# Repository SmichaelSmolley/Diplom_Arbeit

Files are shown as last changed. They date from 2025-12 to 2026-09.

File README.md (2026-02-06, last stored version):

# VS Code Githubsetup

aus github die noreply email heraus suchen dann **git config --global user.email [deine email]**                                      

und auch den username einstellen: **git config --global user.name SmichaelSmolley**

# Ordnerstruktur

## Bokumentation

> In Dokumentation bitte nur words oder Rechnungen

## Hardware

> In Hardware bitte alle datein die mit der hardware seite der DIP zusammenhängen

## Software

> LIBs, python scripts und cpp desktop programme

> Um Python programme laufen zu lassen bitte die *venv.bat* ausführen, dieses installiert alle libs aus requirments, dann mit *.\venv\Scripts\activate* venv starten und dort mit *python dasprogramm* starten, wenn neue libs hinzukommen bitte chatgpt fragen wie du die requirments erweiterts.

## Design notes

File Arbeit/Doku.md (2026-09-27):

# Doku

### **_Spannungsversorgung_** 

Für ferschidenste ics oder uC worden LDOS gewählt weil niergents auf der PCB große kontinurliche ströme gebracuht werden. 
es werden 3,3V 5V und eine ± versorgung benötigt für die benötigten opvs. 
da die digital versorgung muss nicht shönsein da eigenlich nur spannung gebracuht wird nichts schönen doch die analog 5v versorgung sollte schön sein.
es werden hauptsächlich auf Psrr und auf low noise, nciht umbedingt high accuracy. 

### **_Drivers_** 

PINs.c

im PINs.c werden die GPIO pins konfiguriert. 

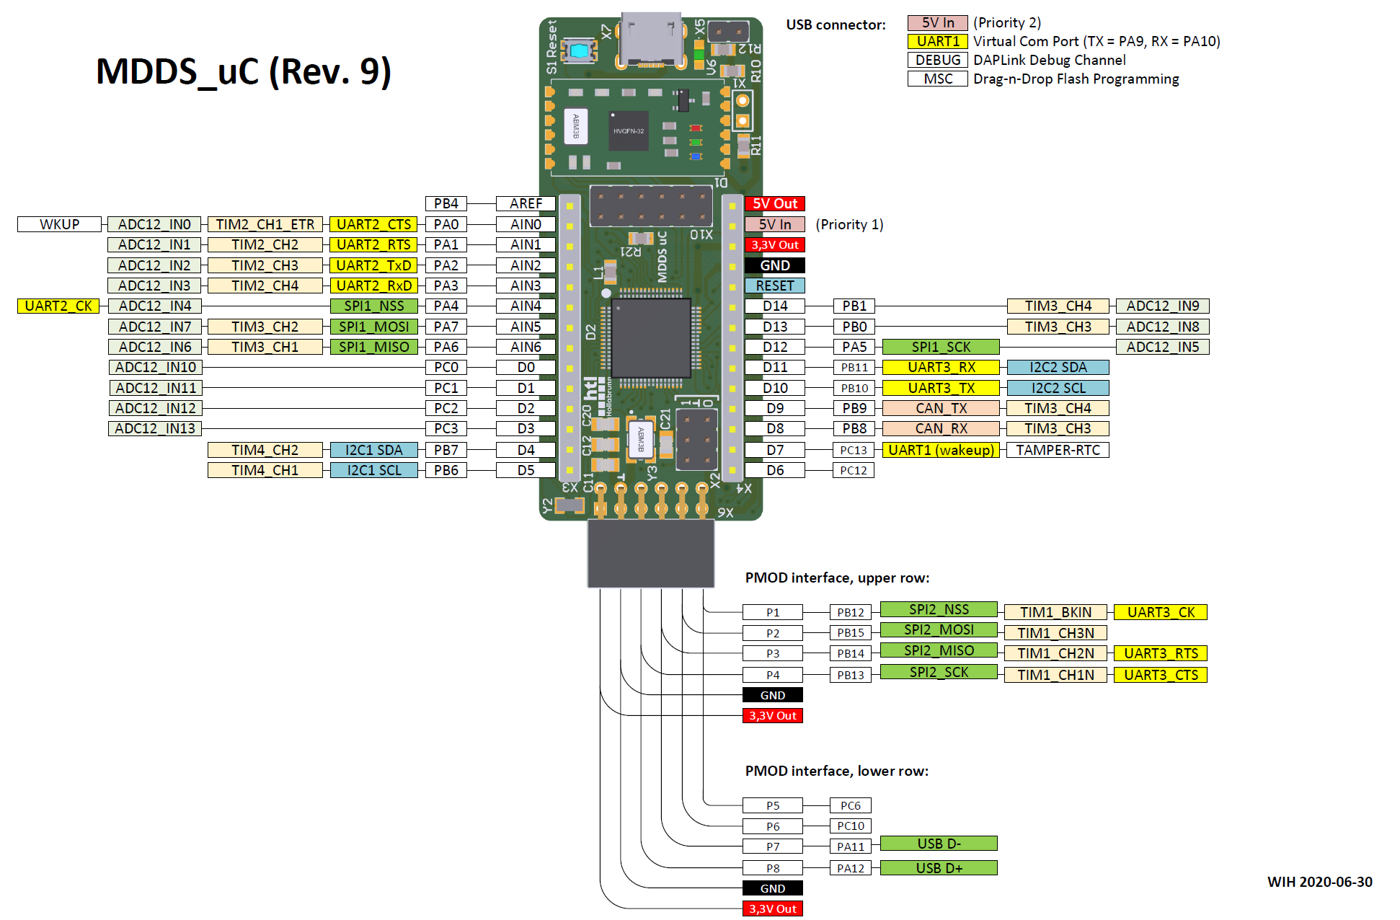
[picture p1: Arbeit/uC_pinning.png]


Der Port A: pin 1,2,4 werdenals Output push pullkofiguriert. PA1 ist die CS* für den DAC (AD5689) biem SPI bus. PA2 ist der konfigurations pin des DAC der zwischen einem gain von 1 und gain von 2 umschaltet, bei einem 1 auf PA2 ist der Gain 2, und damit ist die ausgangs range von 0V bis 5V, und bei PA2 low ist die range 0V bis 2.5V. PIN PA4 ist der CS* für den SPI bus des ADC ADS8681.
Port A: 5,6,7: Pin PA5,7 wird als Alternate funktion PP definiert für die SPI kommunikation. PIN PA6 idt für den MISO pin und ist für analog floating.

Port b: pin 1,4,7 sind im output push pull defniert, 1 ist für die Analog psu enable leitung und aktiviert die 5V versorgung. 4 ist für die Reset* leitung. 7 ist für die OPV enable leitung da die opv enleitungen nicht ganz funktioniern immer auf high lassen.
PB0 ist open drain ist für den One wire bus für in und out, auf diesem bus sind temp sensren und auch einen eeprom.

Portb PB8,9,11: die Ports PB8,9 sind open push pull welche auf die anzeige leds geleitet werden, 9 grün, 8 rot. Pin 11 ist für die 3,3V versorgung also immer high. 

port c: 0,1,2,3, sind immer gp pp und steuern die ralai spulen.

port C: 12 input pull up, ist die ADC* Alarm leitung diese liefert infos wenn ein alarm zustand beim adc auftritt. PC13 ist General purpus pp und ist für den ADC die Reset* leitung.

SPI.c

`#ifndef SPI_H
#define SPI_H

#include <stm32f10x.h>
#include <stdbool.h>

void spi1_init();

void spi1_set_baud(uint8_t baut);

void spi1_rx_dma(bool setting);

uint16_t spi1_transfer16(uint16_t tx_data);

uint8_t spi1_transfer8(uint8_t tx_data);

#endif`

die funmtion spi1 init wird die ganze regisdter konfig gesetzt. anfangs wird eine 8bit übertragung gesetz, es wird standart mäßig ein teiler von 16 verwendet. mit der funktion set baud kann der teiler gesetzt werden nach der tabelle:

	000: fPCLK/2
	001: fPCLK/4
	010: fPCLK/8
	011: fPCLK/16
	100: fPCLK/32
	101: fPCLK/64
	110: fPCLK/128
	111: fPCLK/256

die funktion rx_dma kann den dma für die z.b. adc auswetung geladen werden. die funktion spi transfer8 leitet einen transfer ein der daten die in einem uint8 angegeben wird, die funktion transfer 16 verwendet 2 mal die transfer 8 funktion beide funktionen sind blocking.

AD5689

Im `AD5689.c` wird der AD5689 DAC über SPI angesteuert. Die Initialisierung erfolgt mit `AD5689_init()`. Dabei wird der DAC zurückgesetzt, der Gain auf 1 gesetzt und der Ausgang zunächst auf 0 V gestellt.

Mit `AD5689_send_command()` werden die Befehle an den DAC übertragen. Dabei werden insgesamt 24 Bit übertragen. Das erste Byte enthält Befehl und Adresse, die nächsten zwei Bytes den 16-Bit-Datenwert.

Die Funktion `AD5689_set_Voltage()` wandelt eine gewünschte Spannung von 0 V bis 2,5 V in einen 16-Bit-DAC-Wert um. Werte außerhalb dieses Bereichs werden auf 0 V bzw. 2,5 V begrenzt. Der berechnete Wert wird anschließend an den ausgewählten DAC-Kanal übertragen.

Ads8681

Im `ADS8681.c` wird der ADS8681 ADC über SPI angesteuert.

`ADS8681_transfer_frame()` überträgt einen 32-Bit Frame. Dieser wird in zwei 16-Bit Übertragungen aufgeteilt. Vor der Übertragung wird `ADC_SPI_NCS` auf Low gesetzt und danach wieder auf High.

`ADS8681_send_Command_blocking()` erstellt den benötigten 32-Bit Frame aus Command, Registeradresse und Daten. Der Frame wird anschließend übertragen. Danach wird ein NOP-Frame gesendet, um die Antwort des ADC aus dem Sendepuffer auszulesen.

`ADS8681_init()` setzt den ADC zuerst über `ADC_NRESET` zurück. Danach wird über das Range-Select-Register der Eingangsbereich eingestellt. Im Code wird `ADS8681_RANGE_SEL_UP_1_25_VREF` verwendet.

`ADS8681_get_VOLT()` wandelt den 16-Bit Rohwert des ADC in eine Spannung um. Dabei wird `VREF = 4,096 V` verwendet. Durch die eingestellte bipolare Eingangsspannung ergibt sich ein Messbereich von ungefähr `-2,56 V bis +2,56 V`.

# Messung am 22.09.2026

Messaufbau mit platiene von Drain 1V über 2*8,5Meg Ohm wiederstände an den Source anschluss.
ergebniss sollten:

Ir = 1V/ 17Meg OHM = 58.8nA
dann am TIA:
Uout = Ir * Rf = 58.8nA * 10Meg = 0,588V

nach dem Dämpfer:
Ud = Utia * (10/33) = 0,178V

bei einer messung mit mustimeter kamm richtige spannung bei der adc auswertung kammen die falschen daten, anschluss messung mit oszi nach dem dämper eins mit DC 0,178V überlagertes 400mV pp 50 Hz signal. vermutung aufgrund des widerstands aufbeu und einstrahlung da, denn diese einstarhlung ~10meg verstärkt wird ist es sehr groß. _Abschirmung notwendig_ .

code für die testung:

`int main()
{
	PIN_init();
	set_up_uart1();
	spi1_init();
	
PER_33V_PSU_EN = 1;
ANALOG_5V_PSU_EN = 1;
OPV_PSU_EN = 1;

cal_Select_Reset = 0;
cal_Select_set = 0;
Range_Select_Reset = 0;
Range_Select_set = 0;

DAC_GAIN=0;
DAC_SPI_NCS = 1;
ADC_SPI_NCS = 1;

uart1_set_baud(9600);

{
uint16_t i;
for( i = 0; i < 10000; i++);
}

spi1_set_baud(7);

uart_put_string("UART TEST\r\n");

set_range_10meg();
reset_GND_Relai();
AD5689_set_Voltage(0,AD5689_ADDR_DAC_AB);

wait_ms(1000);

static double buffer[1000];

AD5689_set_Voltage(1.0, AD5689_ADDR_DAC_AB);
char uart_buffer[64];
	wait_ms(1000);
	int i;
for ( i = 0; i < 20; i++)
{
    /* Frame 1: Ergebnis verwerfen */
    ADC_SPI_NCS = 0;
    spi1_transfer16(0x0000);
    ADC_SPI_NCS = 1;

for (volatile int j = 0; j < 1000; j++);

/* Frame 2: Ergebnis verwenden */
ADC_SPI_NCS = 0;
uint16_t raw = spi1_transfer16(0x0000);
ADC_SPI_NCS = 1;

sprintf(
    uart_buffer,
    "%d,0x%04X,%.9f\r\n",
    i,
    raw,
    ADS8681_get_VOLT(raw)
);

uart_put_string(uart_buffer);
}`

# Messung am 23.09.2026

beid er messung im DIC raum wurde mit den giwnsteck die netzspannugnen der pcb eingestellt:

psu1: Ch1: +9V Ch2 -9V
psu2: Ch1: 5V Ch2 6,5V

dnach wurde mit bnc to banana kabeln wurden zuerst mit einem 10Meg weiderstand verbunden zwischen Drain und source anschlussen auf der PCB.

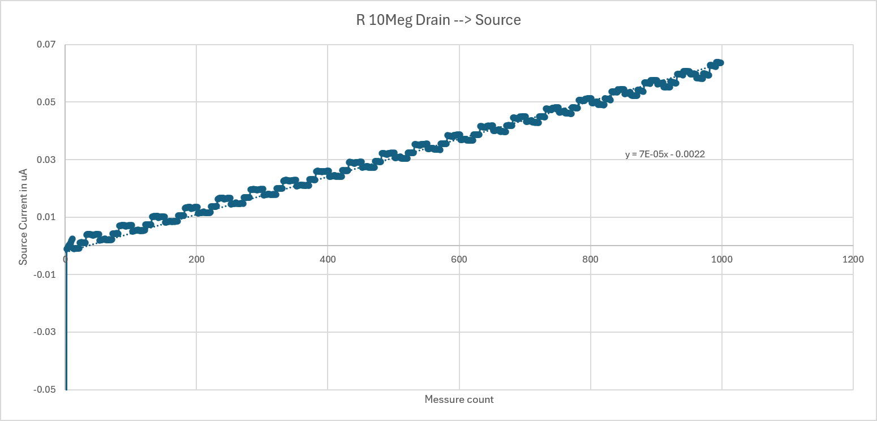
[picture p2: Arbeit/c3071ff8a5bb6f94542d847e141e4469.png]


bei jedem messpunkt wird die spannung des Drain ausgangs geändert, zusehen ist das ein ~50Hz raushcen über dem signal liegt, müsste bei transienten messungen rausgemittelt werden oder versuchen mit dem case zu arbeiten. um es zu minimieren, es wurde versucht bei der IDVG messung mittels 10messwerte pro punkt.

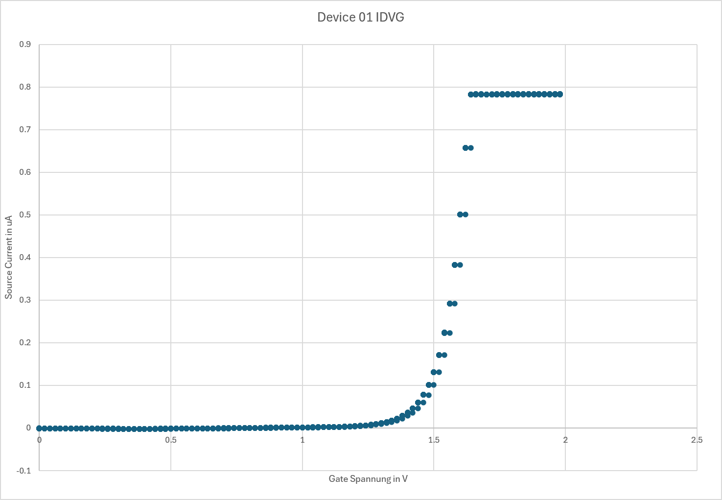
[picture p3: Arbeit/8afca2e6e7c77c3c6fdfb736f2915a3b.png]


Die idvg ab 1,5V gate spannung bis zu~1,7V ist die daten dichte punkte ziemlich gering.

# code 27.09
uint16_t Sps = 1000;
	
	static uint8_t buffer[2000];
	
	init_tim2(Sps);
	
	spi1_tx_dma_init();
	
	spi1_rx_dma_init();
	
	spi1_rx_dma(buffer, 2000);
	
	tim2_enable();
	
	/*static double buffer[1000];
	char uart_buffer[64];
	AD5689_set_Voltage(1.0, AD5689_ADDR_DAC_A);
	wait_ms(2000);
	LED_RED = 1;
	int i = 0;

	for(i = 0; i < 100; i++)
	{
		int j;

		for(j = 0; j < 10; j++)
		{
			ADC_SPI_NCS = 0;

			uint16_t raw = spi1_transfer16(0x0000);
			double volt = ADS8681_get_VOLT(raw);

			buffer[(i * 10) + j] = volt;

			ADC_SPI_NCS = 1;
		}

		DAC_SPI_NCS = 0;

		AD5689_set_Voltage(
			(i*0.02),
			AD5689_ADDR_DAC_B
		);
		wait_ms(100);
		DAC_SPI_NCS = 1;
		
	}
	
LED_GREEN = 1;

for(i = 0; i < 1000; i++) 
	{
		sprintf( 
		uart_buffer, 
		"%i,%.9f\r\n", 
		i, 
		buffer[i] 
		);
		uart_put_string(uart_buffer);
	}

	LED_GREEN = 0;
	LED_RED = 0;
	
	AD5689_set_Voltage(0,AD5689_ADDR_DAC_AB);
	
	while(1)
	{
	}
	
	*/
	/*
	spi1_set_baud(2);
	
	uart1_set_baud(9600);

	init_tim2(1,79); //uint8_t clk_div, uint16_t period_ticks
	
	spi1_rx_dma_init();
	
	uint8_t Adc_data_buffer [1000];
	
	spi1_rx_dma(Adc_data_buffer,1000);
	
	spi1_tx_dma_init();
	
	tim2_enable();
*/
/*	
	
	// Nutzung von uint16_t anstelle von uint32_t
	//uint16_t data = (uint16_t)((ADS8681_RANGE_SEL_UP_1_25_VREF & ADS8681_RANGE_SEL_MASK) << ADS8681_RANGE_SEL_SHIFT);
		
	// Befehl und Adresse direkt in einen uint16_t Wert kombinieren (statt uint8_t bytes[2])
	//uint16_t cmd = (uint16_t)(((ADS868X_SPI_COMMAND_WRITE_FULL << 1) | ((ADS868X_REGISTER_ADDRESS_RANGE_SEL >> 8) & 0x01)) << 8) 
	//             | (ADS868X_REGISTER_ADDRESS_RANGE_SEL & 0xFF);

	//AD5689_init();
	//AD5689_set_Voltage(3, AD5689_ADDR_DAC_AB);
	
	//AD5689_send_command(AD5689_CMD_WRITE_DAC, AD5689_ADDR_DAC_AB, 0xFFFF);

	reset_GND_Relai();
	
	//set_range_100k();
	wait_ms(1000);
	//set_range_10meg();

	//TO-DO: test dac

	spi1_transfer16(0x0000);// das kein befehl mer in wait ist;
	while(1)
	{
		uint16_t raw = spi1_transfer16(0x0000);
		uart_put_char(raw >> 8);
		uart_put_char(raw & 0x00ff);
	}
	
	uint8_t ADC_SPI1_BUFF [100];
	uint8_t ADC_SPI1_DUMMY = 0x00;
	
	spi1_tx_dma_init(&ADC_SPI1_DUMMY, 100);
	spi1_rx_dma_init(ADC_SPI1_BUFF, 100);
	
	uint8_t i = 0;
	for(i = 0; i < 100; i++)
	{
		uart_put_char(ADC_SPI1_BUFF[i]);
	}
	
	uart_put_string("EOS");

	char buffer[64];
	while(1){
	ADC_SPI_NCS = 0;
	uint16_t raw = spi1_transfer16(0x0000);
	double volt = ADS8681_get_VOLT(raw);
	ADC_SPI_NCS = 1;
	sprintf(buffer, "%.3f\r\n", volt);
	uart_put_string(buffer);
	}
	*/

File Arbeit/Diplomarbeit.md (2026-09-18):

---
title: "Analyse von Degradationseffekten bei Feldeffekttransistoren"
author: "Watzek, Traube, Siedersleben, Pernerstorfer"
toc: false
toc-title: Inhaltsverzeichnis
toc-depth: 3
shift-heading-level-by: 1

header-includes:
  # header and footer
  - \usepackage{fancyhdr, titling, lastpage}
  - \pagestyle{fancy}
  - \fancyhf{}
  - \fancyhead[L]{27.01.2026}
  - \fancyhead[R]{Analyse von Degradationseffekten bei Feldeffekttransistore}
  - \fancyfoot[L]{\hspace{0.5cm}HTBL – Hollabrunn}
  - \fancyfoot[C]{Watzek, Traube, Siedersleben, Pernerstorfer}
  - \fancyfoot[R]{\thepage~/~\pageref{LastPage}\hspace{0.5cm}}
  - \renewcommand{\headrulewidth}{0pt}               # header line remove
  - \renewcommand{\footrulewidth}{0.4pt}             # footer line add

  # higher title
  - \usepackage{titling}
  - \setlength{\droptitle}{-8em}

  # margin
  - \usepackage[left=3cm,right=3cm,top=2cm,bottom=2cm]{geometry}
  - \setlength{\headwidth}{\textwidth}
---

\input{titlepage.tex}
\pagebreak
\renewcommand{\contentsname}{Inhaltsverzeichnis}
\tableofcontents
\pagebreak

# Begriffsdefinition

**ADC** – Analog-to-Digital Converter

**BTI** – Bias Temperature Instability

**DAC** – Digital-to-Analog Converter

**DUT** – Device Under Test

**FET** – Field-Effect Transistor

**GIDL** – Gate-Induced Drain Leakage

**HC** – Hot Carrier

**IDVG** – Drain Current over Gate Voltage

**MOS** – Metal-Oxide-Semiconductor

**MOSCAP** – MOS Capacitor

**MOSFET** – MOS Field-Effect Transistor

**MSM** – Measure-Stress-Measure

**OPV** – Operational Amplifier

**PSD** – Power Spectral Density

**RAM** – Random Access Memory

**RDS** – Resistance between Drain and Source

**RTN** – Random Telegraph Noise

**RTS** – Random Telegraph Signal

**SILC** – Stress-Induced Leakage Current

**SNR** – Signal-to-Noise Ratio

**SPICE** – Simulation Program with Integrated Circuit Emphasis

**VTH** – Threshold Voltage

\pagebreak

# Ausgangslage

Heutzutage werden in der Elektronik Schalter meist mit Feldeffekttransistoren realisiert. Diese sind geeignet für hohe Schaltfrequenzen, können kleiner hergestellt und zuverlässiger designt werden. Diese nutzen das Prinzip der elektrischen Felder. Durch das Anlegen einer Spannung am Gate des Transistors wird die Breite des leitfähigen Kanals zwischen den Drain- und Source-Anschlüssen moduliert. Durch diese Gegebenheit sind die Feldeffekttransistoren geeignet, als elektrische Schalter verwendet zu werden.

Doch auch rein elektrische Schalter wie MOSFETs können mit der Verwendung immer unzuverlässlicher werden, allerdings können sich auch die Eigenschaften wie der RDS mit der Alterung der Bauteile ändern. Ursache für diese Änderung mit dem Alter können Defekte in der Kristallstruktur des Bauteiles sein.

Da immer neue Verfahren zur Herstellung von MOSFETs entstehen und die entstehenden Produkte auf die Zuverlässigkeit und den MTTF untersucht werden. Effekte, die verstärkt mit zunehmendem Alter auftreten, sind Drifts der Vth und die Zunahme des GIDL. Neben diesen zeitlich langsamen Veränderungen können Defekte auch zu zeitlich veränderlichen elektrischen Signalen führen.

Diese Änderungen der Eigenschaften können Rückschlüsse auf die MTTF als auch die Ageing Rate erlauben. Weiters kann durch die Untersuchung solcher Effekte die Auswirkung von Defekten auf das Verhalten eines MOSFETs genauer charakterisiert werden.

# Theoretische Grundlagen

Während der Herstellung von Halbleitern werden verschiedene Schichten von verschieden dotiertem Silizium aufgetragen. Auch bei diesem Auftragen der Schichten können an den Grenzflächen zwischen Schichten Defekte auftreten, in Form von nicht verbundenen Atombindungen. Auch innerhalb einer Schicht können z. B. Einschlüsse von O (Sauerstoff-)Atomen oder fehlende Verbindungen zu Defekten in der Kristallstruktur des Siliziums führen.

Die Defekte an der Verbindungsstelle zwischen dem Isolator des MOSFETs und der Siliziumschicht, in der sich der leitfähige Kanal bildet, sind die Defekte, welche den größten Einfluss auf die Degradation haben. Dadurch, dass diese Defekte Ladungsträger aufnehmen oder abgeben können, sind geringere Energien der Ladungsträger notwendig. Da diese Ladungsträger auch leichter wieder abgeben können, sind diese Defekte eher für kurzfristige Effekte verantwortlich.

Defekte im Isolator sind stabiler und können Ladungsträger über längere Zeit speichern. Durch das Auf- und Abgeben von Ladungsträgern können sich Defekte im Isolator verändern und zur weiteren Degradation beitragen.

Degradation bedeutet, dass Defekte im MOSFET ihren Zustand ändern, dadurch, dass sie Ladungsträger aufnehmen. Durch das Abgeben und Aufnehmen von Ladungsträgern können Defekte aktiviert, verändert oder erzeugt werden.

Die relevantesten Eigenschaften, die sich durch die Degradation verändern, sind unter anderem die Ladungsträgermobilität im Leitungskanal und damit der RDS. Bei den in dieser Arbeit hauptsächlich behandelten N-Kanal-MOSFETs kann eine zunehmende Anzahl von Defekten und eingefangenen Ladungsträgern zu einer Verringerung der Ladungsträgermobilität führen. Dadurch kann der RDS zunehmen.

# Technische Grundlagen

## elektrische Messgrößen

Die relevanten Messgrößen die notwendig sind um auf defekt aktivität zu schleisen lassen sich auf 2 Spannungen und 1 strom herunter brechen. die beiden spannungen wären die Gate und Drain spannung des MOSFET, die relevanteste messgröße ist der Source strom den dieser ändert sich mit der zuhname der degradation. 

Der Source strom ändert sich in binären in ~10nA schritten.

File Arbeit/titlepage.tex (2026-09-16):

% titlepage.tex
\thispagestyle{empty}  % removes header/footer for this page

\vspace*{2cm}

\begin{center}
{\Huge \textbf{Analyse von Degradationseffekten bei Feldeffekttransistoren}\par} % bold, big title
\vspace{1cm}

\begin{tabular}{ll}
\textbf{Beteiligte:} & Michael Watzek \\
& Peter Traube \\
& Felix Siedersleben \\
& Augustin Pernerstorfer \\
\textbf{Datum:} & \today \\
\end{tabular}

\vspace{1cm}

% Some extra notes
\end{center}

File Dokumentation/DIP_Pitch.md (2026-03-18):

# DIP_PITCH

## Bauteile

### Wiederstände

USF340-1.00M-0.1%-5PPM
USF340-10.0M-0.1%-5PPM

### Digital
MPU ESP32 Wroom dev board
LVTTL Diff. Sender SN65LVDS1
LVTTL Diff. Transsever SN65LVDS2
LVTTL Diff. Quad Recifer DS90LV048A
LVTTL Diff. Quad Sender DS90LV047A

### Analog
OPV OPA928 ultra low Bias, low noise Opv
OPV LMC6001 low Bias, low noise Opv

### Converter
ADC ADS8681 16Bit, variable Input range, low glitch adc

### PSU
LDO LT3094EMSE#TRPBF low noise, low DropOut, Negative LDO
LDO LT3042EMSE#TRPBF low noise, low Dropout, Positive LDO

### BOX

Modulares Messgeräte-Chassis
https://www.metcase.de/
Instromenten gehäuse
so in der art etwas
Eigentlich ein euro card case und die platienen werden sich an die euro card halten
https://subrack.eu/120-subracks-frames/74183-1-x-3u-84hp-x-178-module-holder-subrack-p160

## Dokumentation

### Idee der Arbeit

Durch den Aufbau des MOSFET, liegt eine Isolierungsschicht am Balk, da solche Isolatoren fertigungsbedingt nicht perfekt hergestellt werden können enstehen unreinheiten, sogenannten ladungsfallen, denn bei einem stromfluss durch den nkanal kann durch den Tunneleffekt dazu kommen das siche ladungsfallen mit elektronen befüllt werden diese verringern durch ihre ladung die dicke des kanales und diese änderung äusert sich als RTN(Random Telegram Noise), dieses ist wiederum messbar. durch analyse des RTN lassen sich rückschlusse auf die Lebensdauer und beschaffenheit von solchen Halbleitern evaluieren.

### Bereichseingrenzung

Es soll eine messschaltung für die messung von nA strömen entworfen werden um die änderung im Strom durch das RTN zu vermessen. Auch die Ansteerung der anschlüsse (Drain, Gate), sollen ansteurbar sien zur automatischen erfassung von der IDVG kennlineie und einstellung des Source stromes. dies soll von einer MCU gstert und reguliert werden diese nimmt die messdaten auf und speichert diese bis zum ende der messung und sendet diese nach dem beendigen der messung an ein Auswerte gerät weiter leiten. 

Auf diesem Auswerte gerät sollen die messdaten entgegengenommen werden und analysiert werden(FFT, Transienten, Digital Tiefpassfilter).

### Motivation der Arbeit

war cool und so

## Arbeitsprogress

+ programmerstellung für die berechnung der TIA stufe
+ Block-Diagramm des Analog Messsystems
+ Auswahl des ADS8681
+ Besprechung mit TU-Kontakt
+ Programm lib erstellung für ADS8681 Kommunikation
+ Herstellung einer Test Kommunikations Platine
+ Entwicklung eines entwurfes für ein Modulares Messsystems

## Blockdiagramm Basic Idee

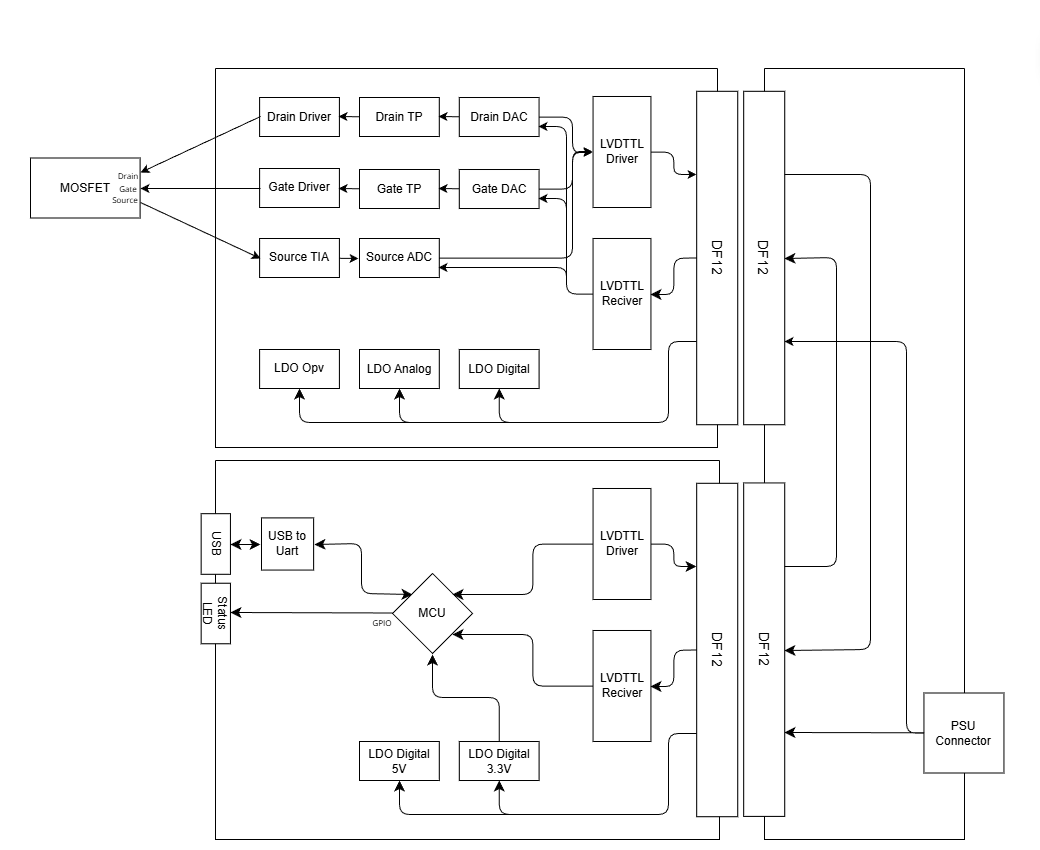
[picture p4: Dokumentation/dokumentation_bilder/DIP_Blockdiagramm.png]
Modulares Messsystem Block


#### DF12:

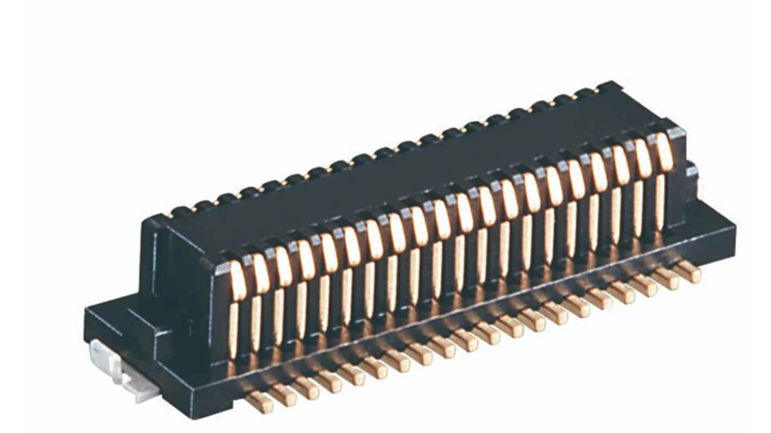
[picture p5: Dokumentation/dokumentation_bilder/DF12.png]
DF12 Conn


#### Board Edge Conn

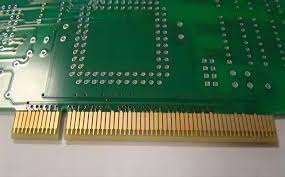
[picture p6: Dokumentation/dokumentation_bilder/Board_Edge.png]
Board Edge Conn


villeicht tausche ich die DF12 noch mit "Board Edge Connector" ist besser für frequentes ein und ausstecken. 

## Diff-Leitung Stecker Systems

Es sollten Diff-Leitungen verwendet werden um EMV zu verbessern und um das EM abstralen zu minmieren und da es sich um eine leitung über 20cm handelt sollte wegen der leitungslänge eine LVD (Low Voltage Diff) Driver und reciver verwedent werden. bei diesen Diff Drivern und Recivern handelt es sich um 100 Ohm systeme, die leitungen mussen entweder mit 100 Ohm abgeschlossen werden bevor die driver und reciver angeschalten werden, es muss eine logik her welche das eichschalten verbitet wenn kein reciver da ist.

## Spannungs Versorgung

Es werden die einzelnen LDO's auf die zuversorgenden Bereiche zu platzieren wenn es sich um spannungs Kritische Bauteile handelt,um Leitungs Wiederstand zu minimieren. Weiters soll auf die Rauschunterdrückung geachtetwerden um dadurch entstehenden Störungen zu minmieren. Zu überselgen ist ob ein Power good verwendet wird um davür zu sorgen das bei start up erst die spannung der bauteile steht dann daten gesendet werden.

## LVDS Impedanz anpassung

bei lvds muss auf die impedanz auf der pcb geachtet werden, die jetzigen lvds transiever sind ein 100 ohm prinzip.

## Messungs datenmengen

wir verwenden gerade so einen adc mit 16bit, der wunsch ist das wir die vollen 1Msps (1M messung pro sekunde) zu verwenden. das heist wir haben 2MByte pro sekunde, und wir wollen messungen bis zu 5min(300sek) daraus rechnet sich eine Messung hat eine daten menge von 600Mbyte(fuck viel, vieleicht so einen Flash chip oder eine sd karte oder so am besten über spi oder über ein anderes MCU protokoll), wir müssen das speichern, ein ansatz um die daten menge zu minimieren ist messungen zu mitteln(5 messungen zusammen addieren und später durch 5 rechenen) das ist aber auch mehr cpu lastig. 

Da auch die DAC angesteuert wrden müssen ist zu überlegenn die spi schnittstellen nicht alzu sehr zu belastgen.

## DMA

wir sollten einen dma verwenden um die CPU zu entlasten da die mit der controlle der umgebung und der steuerung der DAC und sonst beschäftigt ist. der DMA über nimmt die comm mit dem ADC speichert alle daten ins ram dort könnten wir einen weiteren ansetzten um die daten aus dem Ram auf einen flash speicher zu geben. die cpu sollte nicht das daten lifting übernehmen

## Cycle Buffer

ein cycle buffer oder ringbuffer oder einefach zwei buffer, wärend der eine buffer beschreiben wurde wird der andere z.b. auf die Flash zelle speicher, wenn der erste voll ist wird es wieder gecycled

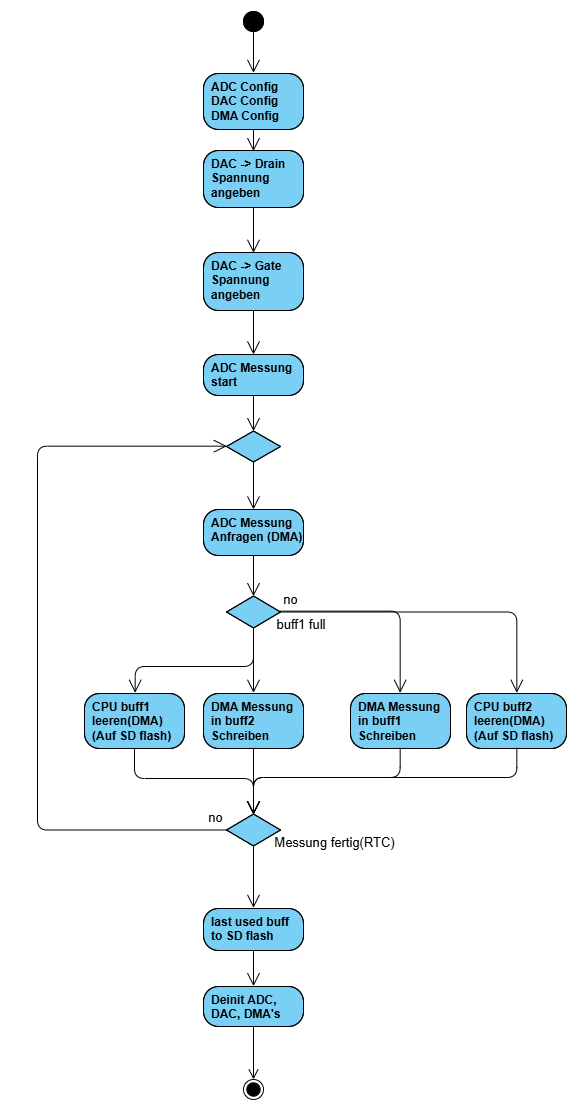
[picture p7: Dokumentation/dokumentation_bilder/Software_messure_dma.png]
buffer cycle


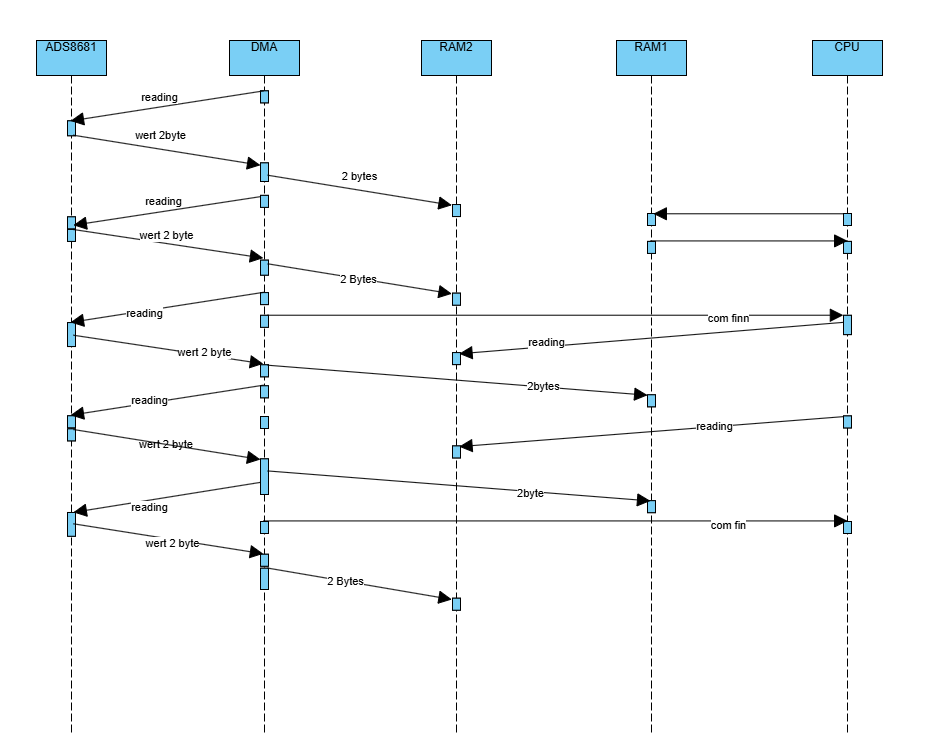
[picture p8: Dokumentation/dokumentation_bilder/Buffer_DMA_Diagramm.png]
Buffer Cycle


## Software Calibrate

einmal nach dem start up der analog platine soll die option eines callibireirn begeben sein, einmal den ADC einlesen, eingang auf null legen offset merken, rausch messung zur bestimmung des signal noise distance temperatur messung und psu kontrolle.

## MCU Auswahl

der uC muss die anforderungen erfüllen: genug dma, SPI speed, genug ram für die buffer, und funktionalität der usb und rs232  verbindung. ambesten einen stm m4 oder einen esp. bei einem stm können wir schon leichter programmieren und einen esp nicht aber der ist bisschen leistungsfähiiger und leichter of board(auf eine eigene platine bringen) bringen.

## Messbox

ich hätte mir so was vorgestellt keine ahnung wie das heist bitte herausfinden.

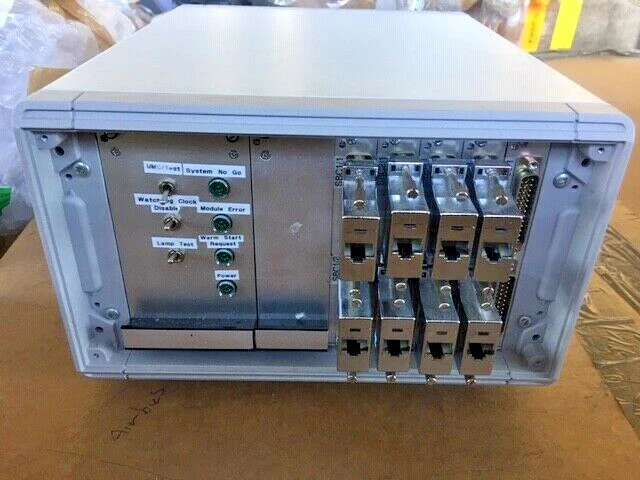
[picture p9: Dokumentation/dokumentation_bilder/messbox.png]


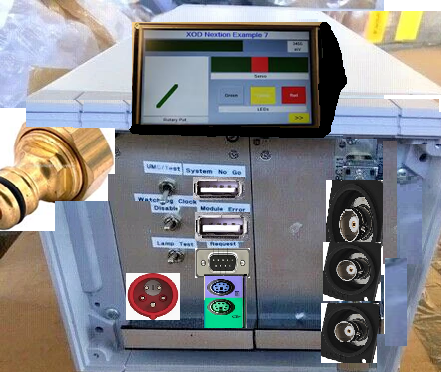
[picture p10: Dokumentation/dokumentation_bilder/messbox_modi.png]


## Software
### Software Data Structure Messure

<<<<<<< Updated upstream
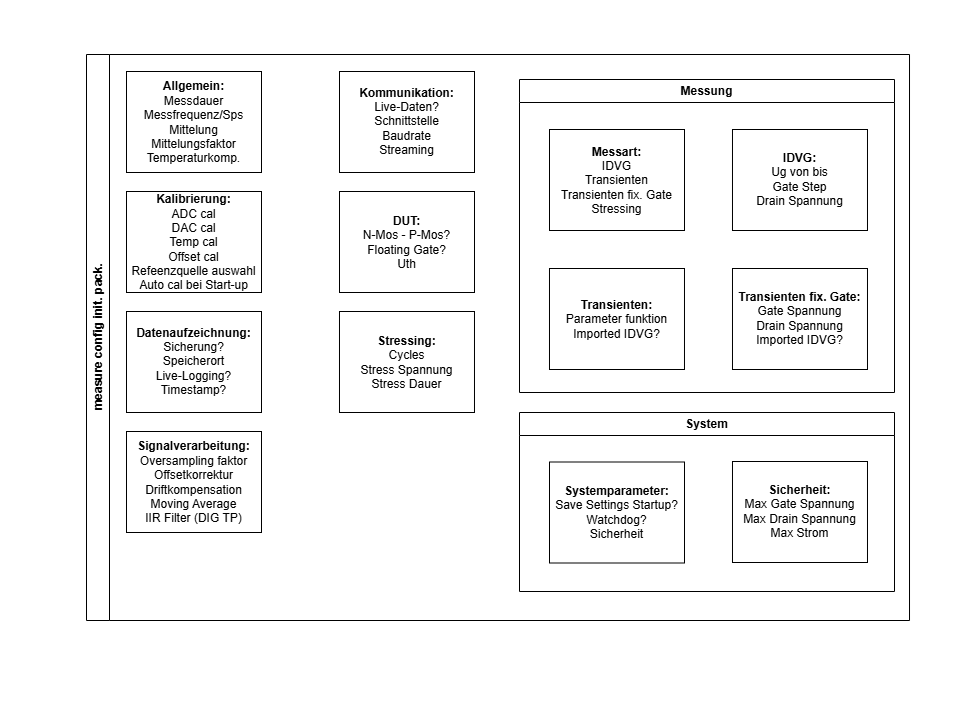
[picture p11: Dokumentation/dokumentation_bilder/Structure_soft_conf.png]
Software Data Structure Messure


=======
>>>>>>> Stashed changes

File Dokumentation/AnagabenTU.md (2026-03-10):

# Diplomarbeitsspezifikationen

## Grundlegende Angaben:
Es soll ein modulares und rauscharmes Messsystem zur Charakterisierung von MOSFETs und zur Untersuchung deren RTN-Effekten entworfen werden. RTN entsteht durch einzelne Defekte im Gate-Oxid oder an der Grenzfläche, welche durch das Einfangen und Abgeben von Ladungsträgern entstehen. Durch diesen Vorgang entstehen diskrete Stromstufen im Sourcestrom des MOSFETs. Mit diesem Messsystem sollen diese Stromfluktuationen analysiert sowie die Auswirkungen von Stressspannungen auf das Auftreten von Defektaktivitäten untersucht werden.

## Funktionelle Angaben:

ID-VG:
Die Gate-Spannung soll mittels eines DC-Sweeps variiert werden, während die Drain-Spannung konstant gehalten wird. Der Sourcestrom des MOSFETs wird über einen TIA gemessen. Die Drain- und Gate-Spannung sollen auch durch das Messgerät zur Verfügung gestellt werden. Die Sweep-Parameter (Startspannung, Endspannung, Schrittweite) sollen konfigurierbar sein.

RTN Messung:
Für die Untersuchung von Random Telegraph Noise wird ein fester Arbeitspunkt am MOSFET eingestellt (konstante Gate- und Drain-Spannung). Anschließend wird der zeitabhängige Strom über einen längeren Zeitraum aufgezeichnet. Bei kleinen MOSFET-Strukturen können dabei Stromstufen auftreten. Diese können durch einzelne aktive Defekte im Isolator oder an der Grenzschicht zwischen Isolator und Bulk-Material entstehen. Die Messdaten werden anschließend analysiert. Folgende Auswertungen sind vorgesehen: Histogramm der Stromwerte, Stromsprunghöhen, Dwell-Times der einzelnen Zustände und Power Spectral Density (PSD) zur Analyse des Low-Frequency-Noise.

Stress Messung:
Beim Stressen wird eine erhöhte Gate-Spannung über einen definierten Zeitraum angelegt, wodurch sich Defekte im Gate-Oxid oder an der Grenzfläche laden können. Nach der Stressphase wird der MOSFET erneut am Arbeitspunkt vermessen, um Veränderungen im Stromverhalten oder der Defektaktivität zu analysieren. Je nach Device-Größe kann es zu Stromstufen oder zu einem kontinuierlichen Stromanstieg kommen.

Frequenzanalyse:
Die aufgezeichneten Stromtransienten sollen zur Berechnung der PSD verwendet werden, um das Rauschen des Messgerätes zu analysieren. Weiters soll die PSD verwendet werden, um charakteristische Noise-Spektren sowie mögliche Störfrequenzen zu identifizieren.

Strom Messbereich:
Das Messsystem soll mehrere Bereiche abdecken, um sowohl kleine als auch größere Ströme messen zu können. Das Hauptziel ist die Messung von Strömen im Bereich unter 10 nA, da RTN-Effekte typischerweise in diesem Bereich auftreten.
Strom-Messbereich:
10 nA – 1 µA
1 µA – 1 mA

Rauschverhalten
Das Messsystem soll so ausgelegt werden, dass das Eigenrauschen des Verstärkers möglichst gering ist, um Ströme im Nanoampere-Bereich detektieren zu können. Das Rauschverhalten soll über die Power Spectral Density (PSD) charakterisiert werden. Das Eigenrauschen des Messsystems soll klein genug sein, um Stromfluktuationen im Bereich unter 10 nA detektieren zu können.

Linearität:
Die Linearität des Strommesspfades soll mit Hilfe einer Referenzstromquelle überprüft werden. Dabei sollen Offsetfehler, Gainfehler sowie die Nichtlinearität des Systems bestimmt werden.

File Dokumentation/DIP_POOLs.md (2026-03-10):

# DIP_POOLs

so einteilung in tehemen und die dann in pools und so das sich jeder eines aussuchen kann was er machen will

## Digital

- [ ] LVDS Trancivers -Peter
- [ ] LVDS Impedanz berechnung -Peter
- [ ] MCU auswahl
- [ ] USB - Uart
- [ ] Rs232
- [ ] Speicher (Massenspeicher)
- [ ] DMA
- [ ] DMA Trigger
- [ ] DAC auswahl
- [x] ADC auswahl -Michael
- [ ] SPI Hintergrund -Peter

## Analog

- [x] TIA Schaltung -Michael
- [ ] Gate Schaltung -Michael
- [ ] Drain Schaltung -Michael
- [ ] LDO Auswahl
- [ ] Rauschberechnung
- [ ] PSRR
- [x] Bandbreitenanalyse -Michael
- [x] OPV Supply -Michael (Vorrübergehend)
- [ ] 1/f rauschen -Felix
- [ ] Rauschdichte 
- [ ] 50Hz Filter 
- [ ] Guard-Rings 
- [ ] PCB Oberfläche
- [ ] Leckströme
- [ ] Messungs Blockdiagramm -Michael

## Software

- [x] Software Parameter -> uC -Michael
- [ ] Software Blockdiagramm -Michael
- [ ] DMA Support
- [ ] Callibrate
- [ ] Software ADC
- [ ] Software DAC
- [ ] Cycle Buffer
- [ ] PC MCU Comm
- [ ] MCU PC Comm
- [ ] System init
- [ ] System tests
- [ ] System stability
- [ ] SPI Hs

## EMV

- [ ] Leitungsgebundene
- [ ] gestrahlte Störung
- [ ] Gleichtakt vs. Differenziell
- [ ] Nahfeld vs. Fernfeld
- [ ] Koppelform(cap, ind, gal)
- [ ] Low-Freq-kopp
- [ ] 50Hz magnetfeld Koppelung
- [ ] Masseführung
- [ ] Versorgungs ripple
- [ ] LDO PSRR
- [ ] GND Split
- [ ] Stecker
- [ ] Abschirmung Metallgehäuse
- [ ] Messung (Nahfeldsonde) (Spektrum) (Ripple)

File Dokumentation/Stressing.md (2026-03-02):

# Stressing-Measure

## Stressing
- TDDB .. Time-Dependent Dielectric Breakdown (zeitabhängiger dielektrischer Durchschlag)
- DIP .. Diplomarbeit
- FG .. Floating-Gate MOSFET
- DUT .. Device under Test
- ID-VG .. Drain-Strom über Gate-Spannung

Das Stressen ist eine der Hauptanalysen der DIP, wobei in der DIP 2 Arten von MOSFET's gestresst werden, ein "Normaler" und ein Floating-Gate.
Stressen heißt, dass das Gate mit hohen Spannungen (je nach MOSFET) zu versorgen ist. Während der Messung darf am Drain keine Spannung anliegen, da diese zu hohen Drain-Strom führt, welcher den Source TIA und den Drain Driver zerstören könnte. Bei einem normalen MOSFET soll das TDDB vermeseen werde, bei einem FG soll die Endurance vermessen werden. Die Messungen geben auskunft über die Lebensdauer und über das Verhalten des DUT

Das Stressen wird in Zyklen aufgebaut, z.b. es sollen 100 Stresszyklen durchgeführt werden, danach eine IDVG-Messung vorgenommen werden und anschließend weitere 100 Stresszyklen.
Durch das Stressen erwartet man sich folgenden Effekte in der Messung der ID-VG Kennlinie zu erkennen:

- Verschiebung der Threshold-Spannung
    - Das Aufladen von Traps (Fallen Oxid) beim TDDB. Traps sind Defekte in der Oxidschicht.
 
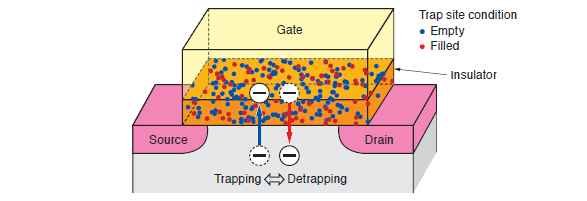
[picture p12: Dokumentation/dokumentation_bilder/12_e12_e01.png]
traps


- Verschiebung der Kurve nach rechts bei einem N-Kanal.

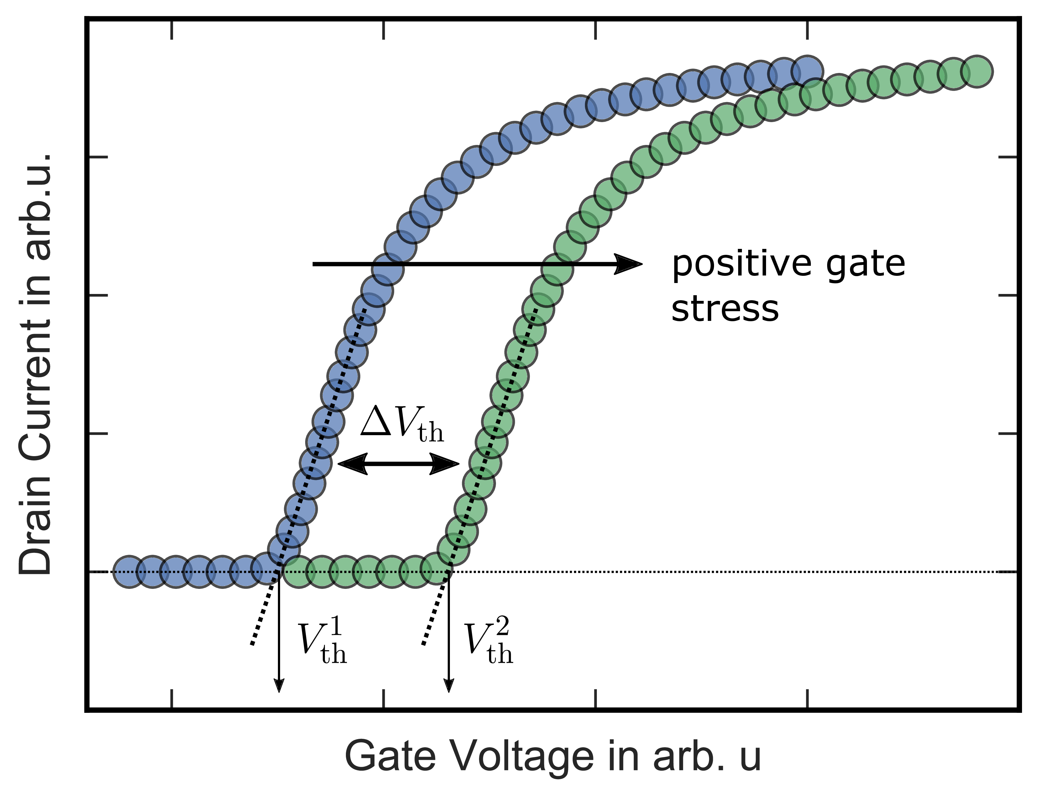
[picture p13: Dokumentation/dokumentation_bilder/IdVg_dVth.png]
IDVG


- Leakage Current durch das Oxid
    - Durch das Stressen können lokale Schwachstellen enstehen-> Leakage steigt
    - kann im Subthreshold-Bereich den Strom steigern
- Reduzierung des Kanalstromes
    - wenn die Fallen aufgeladen sind, kann es zur Mobility Beeinträchtigung der Elektronen kommen
    - IDVG wird flacher

Messung eines FG

- Abbau des Tunneloxids
    - Jedes schreiben oder löschen erzeugt Traps und lokale Defekte
    - Diese Führen zur Threshold-Verschiebung im nicht beschriebenen Zustand, bzw. zum Ladungsverlust am FG
- Die Ladung am FG kann sich auch ohne Strom langsam ändern
- Vth-Drift: Der gleiche Program/Erase-Befehl führt nach 100 Zyklen zu einer anderen Threshold-Spannung, weil sich Fallen im Oxid angesammelt haben.
- Subthreshold-Leak: Leichte Erhöhung durch Oxid-Defekte.
- Programmier-/Lösch-Effizienz sinkt: Die Zelle benötigt evtl. höhere Spannung oder längere Zeit, um dieselbe Threshold-Spannung zu erreichen.
- Langzeit-Ausfallrisiko: Nach sehr vielen Zyklen (10⁴–10⁶) kann das Oxid durchbrechen → permanente Datenverluste.
- Durch das Analysiern der Threshold-Verschiebung und durch das steigen des RTN lassen sich Rückschlüsse auf die Lebenszeit schließen

## Measure

Die Größen welche vermessen werden sollen sind das RTN, IDVG und leak current. 

### RTN

Bei RTN handelt es sich um Random Telegraph Noise, bei diesen handelt es sich um Rauschen im nA Bereich. Es handelt sich um ein digital ähnliches Rauschen(deswegen Telegrapf). Dieses tritt auf beim Laden und Entladen von Fallen im Oxid. Die Häufigkeit von diesem Rauschen kann Rückschlüsse auf den Zustand des Oxides liefern, und damit auf die Auswirkungen des Stressens. Bei einem langen Stressen eines FG kann das Tunnel Oxid beschädigt werden und so kann vermehrt RTN vorkommen. 

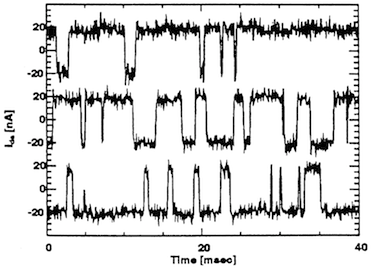
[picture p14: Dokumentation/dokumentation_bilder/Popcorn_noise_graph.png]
RTN


### IDVG

Bei der IDVG handelt es sich um die Kennlinie eines MOSFET (der Drain-Strom über die Gate-Spannung).

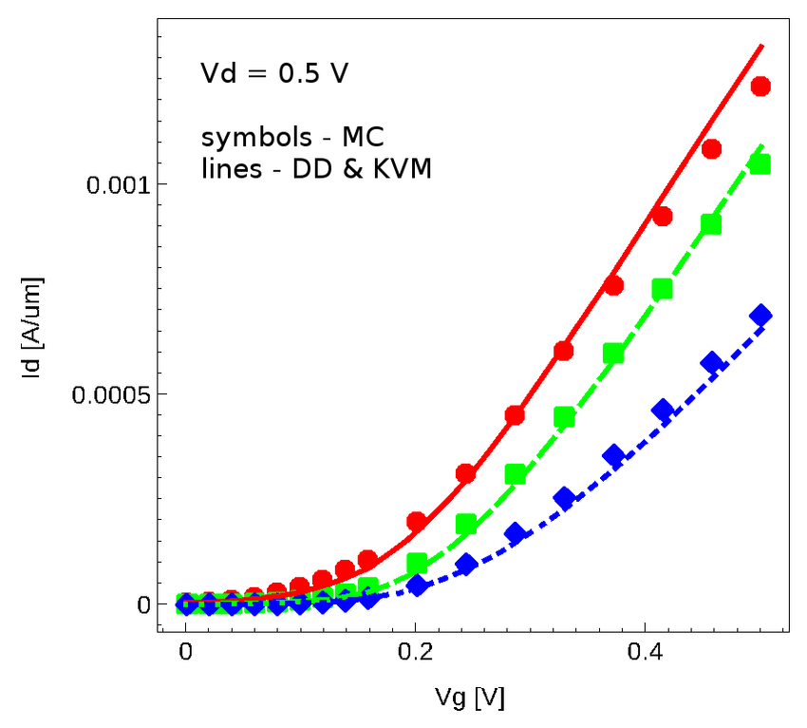
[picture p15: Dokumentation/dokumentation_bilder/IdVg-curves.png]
IDVG


Diese können durch einen Sweep über die Gain-Spannung erstellt werden. Bei dieser Kennlinie kann es zu Veränderungen durch verschiedenste Stresseffekte kommen. Die Threshold-Spannung kann durch das Stressen von geladenen Ladungsfallen erhöht werden, was die gesammte Kennlinie nach rechts verschiebt. Die Steigung kann ebenfalls durch das Stressen beeinflusst werden. Ebenfalls kann der Subthreshold-Strom durch Beschädigungen im Oxid, welche Leakage-Current zulassen, beeinflusst werden.

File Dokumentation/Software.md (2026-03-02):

## Software

Anzudenken ist eine funktion die Stresst (n cycles-mit den itgegebenen parametern), dann misst, und wieder stresst,( es sollen einfach ein programm ablauf vorgenommen werden, die die mitgegebenen parameter nimmt)

Parameter einer Messung:

**Allgemein:**

- Messdauer
- Messfrequenz/Samplingrate
- Mittelung
- Mittelungsfaktor
- Temperaturkompensation?

**Messart:**

- IDVG
    - Gate von bis
    - Gate Step
    - Drain Spannung
- Transienten
    - Parameter funktion
    - Imported IDVG
- Transienten fixed Gate
    - Gate Spannung
    - Drain Spannung
    - Imported IDVG?
        - Source Current
- Stressing
    - Cycles
    - Count
    - Stress Spannung
    - Stress Dauer

**Signalverarbeitung:**

- Oversampling Faktor
- Offsetkorrektur
- Driftkompensation
- Moving Average
- IIR Filter (Dig TP)

**Kalibrierung:**

- ADC cal
- DAc cal
- Temp cal
- Offset cal
- Referenzquelle auswählen
- Auto cal bei Start-up?

**Datenauzichnung:**

- Speicherung?
- Speicherort
    - RAM
    - SD
- Live Logging?
    - Logging Intervall
- Timestamp?

**Kommunikation:**

- Live-Daten?
- Schnittstelle
    - USB
- Baudrate
- Streaming
    - kontinuierlich
    - paketbasiert

**Systemparameter:**

- Save Settings at Startup?
- Watchdog?
- Sicherheit
    - Max Gate Spannung
    - Max Drain Spannung
    - Max Strom

**DUT:**

- N-MOS - P-MOS?
- Floating Gate?
    - Program/Erase-Spannung
- Uth

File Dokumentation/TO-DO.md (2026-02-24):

## To-Do Liste

+ Zeichnen des Blockdiagramms (done)
+ Blockdiagramm für ein Modulares Messsystems (done)
+ erklärung Diff-Leitungen Stecker Systems(done)
+ peter Quälen
+ Programm ssd zustand

## To-Dos alsnächstes

- [ ] Esp Footprint
- [ ] dev board
- [ ] messure with board
- [ ] 

## To-Dos allgemein
**Versorgung**
- [ ] Eigangsspannung auf Platinen Definieren(Drop out berücksichtigen)
- [ ] Verlustleitung der LDO's berechnen
- [ ] Termische evaluierung der LDO's
- [ ] PG(Power Good) Signal entweder verwenden oder nicht (eher schon schon wichtig beim LT3094 **BIGL** fragen)
- [ ] ESD Schutz und überspannung Schutzkonzept

**Ground-Konzept**
- [ ] Durchgehende Ground-Plane
- [ ] Via-Fence bedenken
- [ ] Rückstrompfade analysieren (Digital und Analog)
- [ ] Sicherstellen: Kein Split unter LVDS-Leitungen
- [ ] Analog-Referenzpunkte klar definieren und stützen

**TIA / Hochimpedanzbereich**
- [ ] Guard-ring und pines für opa928 einplanen
- [ ] feadback wiedestand villeicht mit reed relais
- [ ] hoch impedanz leitungen kurz halten maybe guard
- [ ] Leckstromquellen klein halten (Stecker, Fluxreste, Feuchte)
- [ ] Masse für analog stabil und keine hohe leistung und keins Schalten

**Rauschbetrachtung**
- [ ] Noise maybe berechnen 
- [ ] PSRR der LDOs prüfen 100Hz
- [ ] 50-Hz-Einkopplung analysieren
- [ ] EMV box bauen
- [ ] Digitale Lastströme vom Analogbereich fernhalten

**LDO-Layout**
- [ ] Ausgangskondensatoren laut Datenblatt auswählen
- [ ] SET-/Noise-Kondensator korrekt dimensionieren
- [ ] Masseanschlüsse lokal bündeln
- [ ] Datenblatt-Layout-Empfehlungen umsetzen

### Impedanzkontrolle
- [ ] Zielimpedanz definieren (100 Ω differentiell)
- [ ] PCB-Stackup festlegen (2-Layer oder 4-Layer)
- [ ] Leiterbahnbreite und Abstand berechnen
- [ ] Hersteller-Stackup-Daten einholen
- [ ] Impedanzsimulation durchführen (falls möglich)

### Routing-Regeln
- [ ] Beide Leitungen gleich lang führen
- [ ] Gleiche Anzahl an Vias pro Leitung
- [ ] Keine Via-Stubs
- [ ] Keine Unterbrechung der Referenzebene
- [ ] Keine 90°-Winkel
- [ ] GND nahe am Diff-Pair platzieren

### Stecksystem
- [ ] Board-to-Board oder Edge-Connector festlegen
- [ ] Mechanische Führung berücksichtigen
- [ ] GND-Pins um jedes LVDS-Paar anordnen
- [ ] Kontaktanzahl für Erweiterung prüfen

### Mechanik
- [ ] Steckzyklen abschätzen
- [ ] Einschubmechanik definieren
- [ ] Führungsschienen oder Zentrierhilfen planen
- [ ] Toleranzen berücksichtigen
- [ ] Verriegelung oder Verschraubung einplanen
- [ ] EMV-Schirmkonzept berücksichtigen

### 5. Digitale Integration

- [ ] LVDS-Pegel prüfen
- [ ] 100-Ω-Termination am Empfänger platzieren
- [ ] Referenzspannung prüfen
- [ ] Clock-Verteilung bewerten
- [ ] Übersprechen zwischen LVDS und Analogbereich analysieren

### 6. Test- und Debug-Konzept

- [ ] Messpunkte einplanen (LDO, Sternpunkt, TIA-Ausgang)
- [ ] Analog- und Digitalteil separat testbar machen
- [ ] LVDS-Testpattern-Einspeisung vorsehen
- [ ] Versorgung getrennt messbar machen
- [ ] Optionale Serienwiderstände oder Jumper für Debug einplanen

### 7. Dokumentation

- [ ] Blockdiagramm erstellen
- [ ] Ground-Return-Path grafisch darstellen
- [ ] Impedanzberechnung dokumentieren
- [ ] LDO-Auswahl technisch begründen
- [ ] Noise-Budget berechnen
- [ ] Layoutentscheidungen begründen
- [ ] Alternativen vergleichen
- [ ] TIA berechnungen dokumentieren

### Themen zur Vertiefung

- [ ] Rückstrompfade bei High-Speed-Signalen
- [ ] Microstrip vs. Stripline
- [ ] Differential Impedance Berechnung
- [ ] Low-Frequency Noise bei LDOs
- [ ] EMV-Grundlagen
- [ ] Ground-Bounce und Referenzverschiebung
- [ ] Leckstrom-Mechanismen auf PCBs

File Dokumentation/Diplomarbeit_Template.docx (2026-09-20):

HÖHERE TECHNISCHE BUNDESLEHRANSTALT

HOLLABRUNN

Höhere Abteilung für Elektronik – Technische Informatik

Projektnummer: 10313 | Projekt Betreuer: BIGL
Version: 01 | Projekttitel: Messung und Analyse von Feldeffekttransistoren
Datum: 25.06.2026 | Teilnehmer: WATZEK, TRAUBE, SIEDERSLEBEN, PERNASTORFER

Inhaltsverzeichnis

# 1 Begriffsdefinition

ADC analog-to-digital coverter

BTI bias temperature instability

DAC digital-to-analog coverter

DUT device under test

FET field-effect transistor

GIDL gate-induced drain leakage

HC hot carrier

IDVG Drain current over Gate Voltage

MOS metal-oxide-semiconductor

MOSCAP MOS capacitor

MOSFET MOS field-effect-transistor

MSM measure stress measure

OPV operational amplifier

PSD power spectral density

RAM random access memory

RDS Resistance between Drain and Source

RTN random telegraph noise

RTS random telegraph signal

SILC stress induced leakage current

SNR signal-to-noise ratio

SPICE simulation program with integrated circuit emphasis

VTH Threshold Voltage

# 2 Theorie der Arbeit

## 2.1 Grundlagen von Feldeffekttransistoren

In the modern world, electronic devices have become an integral part of daily life.

This has been mainly enabled as the electronic industry has seen rapid progress in recent

years with the development of smaller, faster, and more reliable devices. At the heart

of most of the electronic devices lies the metal-oxide-semiconductor (MOS) transistor

as one of the main building blocks, which at a first glance seems like a simple stack of

three material layers [1]. MOS structures function by exploiting the field effect: applying

voltage to their metal gate terminal modulates the conductivity between the source

and drain terminals. This creates a channel at the semiconductor-insulator interface,

allowing for the switching of electronic signals, making them essential to reproduce the

binary logic necessary for logic gates of computer architectures – Quelle 1, Page 1

Heutztage sind in der elektronik werden schalter meist mit Feldeffekttransistoren realieseirt, diese sind geeignet für hohe schaltfrequenzne können kleiner hergesetllt und zuferlässiger desingt werdem. Diese nutzen das prinzips der elektrischen felder, durch das anlegen einer spannung am Gate des tranisitors wird die breite des leitfähigen kanals zwischen den Drain und Source anschlüssen moduliert. Durch diese gegebenheit sind die Feldefekt transistoren geeignet als elektrischeer schalter verwedet zu werden.

Die Bajeren die der entwiklung besserer FETs im wege steht ist die hersstellung und sind parameter wie leistungs aufnahme als auch schaltgeschwindigkeit. Diese parameter sind durhc die herstellung bestimmt und die defekte die bei dieser entsthen. Mosfets werden aus verscheidenen sichten aufgebaut, da dies wie nicht in der tehckink perfekt vor sich geht entstehen defekte zwischen den verscheidenen schichten als auch in den einzelnen schichten. Diese defekte in der silitium kristall struktur können die eigenschaften der halbleiter veerändern, das elektrische feld des matall gates, indem defekte ladungsträger aufnehmen können als auch abgeben können. Durch das aufnehmen kann sich

# 3 Grundlage der MOSFET Vermessung

## 3.1 MOSFET Parameter

Parameter eines FET können durch alterung ändern, durch dasändern kann in exctrenem alterung auch zu vollem versgen des bauteiles kommen z.b. Durchbruch des Gate isulators, nicht vostendiges leitend werden durch verschiebung der VTH. Die relevanten Parameter der Angepeilten messungen ist die IDVG, VTH, RDS, das RTN und deren verschiebung bei einem MSM verfahren.

## 3.2 Messung von MOSFET Parameter

Das bestimmen der genannten parameter ist möglich über das einstellen der Drain und Gate spannung und dem messen des resultierenden Drain Source Stromes.

Eine IDVG kann erstellt werden indem eine fixe Drain spannung am DUT angelegt wird und die gate spannung variiert wird und der Drain Source Current aufgezeichnet wird.

Die VTH kann bestimmt werden durch die analyse einer IDVG.

Der RDS kann durch die steigung der kennlienen in einem Ausgagngskannlienen feld bestimmt werden.

Ein Ausgangskannlinenfeld kann erstellt werden durch das anlegen einer bestimmten Gate spannung und dem variieren der Drain spannung und der aufzeichung des Drain Source Currents.

RTN kann analysiert werden durch das anlegen einer Gate spannung biss ein gewünschter drain source current erreicht ist, dieser wird über die gesamnmte messung fix gehalten. Bei dieser messung sind absulute source current werte nicht im haupt fokus sondern der unterschied zwischen den strom nivos des stromes bei einem absorbierten als auch emitierten lkadungsrträger.

## 3.3 Messungsaufbau

Das messen des drain Source Current würde auf mehrere weisen funktionieren, mithilfe von jall sensoren, einer OPV Intehratorschaltung, einem schalt wiederstand und den spannungsabfall andiesem allerdings bieten diese möglichzeiten nachteile wenn es entweder un den nano Ampereberichcj hejt oder in der sample grequenz. Ein hallsensor bietet nicht die nötige auflösing bei nano Ampere und kann zustag von aiseren einflussen beeinflusst werden. ein OPV intehrator schaltkeis bietet die nötige auflösung in nA bereich doch biestet nicht eine braicjbare sample frequenz. Bei einem Schant wiederstand wird der spannungs abfall gemessen dich dieser verschiebt je nach source current die Drain source soannung dieses musste kommpensiert werden denn dies würde wie eine strom gegenkoppplung wirken.

Eine schaltunf die offt für nano amperströme verwendet wird, im bezug auf das verstärken von photodioden, ein Tranzimpedanz wadler. Dieser misst den spannungsabfall über einenhohen feadbackwiederstand.

I = 1nA

R = 1GOhm

U=R*I=10^(+12) *10^(-12) =1V

Diese Schaltung bietet unter den richtigen bedingungen eine hohe samplerate, bis zu mehrerren kHz. Eines der größeren probleme ist unterandeerem die Granz als auch polefrquenzen und das thermische rauschen des Feadback wiederstandes begrenst die auflösung der schaltung.

Dies ist der Grobe aufbau um eine Variable Drain und Gate spannung als auch eine messung des soruce stromes. Der I_Sorce fliest gegen ein phantom graund am – port des OPV U1 der OPV versucht diesen strom auszugleichen indem er die ausgagngsspannung am RF solange steigert bis über diesen wiederstand I_Source fliest. CF muss aufgund dieser gegebenheit eine geringe leak current haben um nicht die messung zu beeinflussen, witers begrenst er die frequenz der OPV schaltung, denn bei Tranz impedanz wandlern kann es zum schwingen könnem die die grenzfrequenz zu hoch gewählt wird. Zum schwingen kommt es aufgrund von parasietöten kapazitäten aud der Source seite des MOSFET.

Die Verstärkung des TIA lässt sich einfach mit den genannten gegebenheiten berechnen.

U_(out) = R_F *I_(Source) →(U_(out))/(I_(Source))=R_F

Allerdings ist diese schaltung inverteirend, das bedeutet um von einem ADC verarbeitet zu werden sollte ein wieterer invertierender OPV verwendet werden um einen Positiven zusammenhang zwischen Ausgangsspannung und eingangsstrom ensteht. Der nachgeschaltener OPV sollte auch eine bereichs anpassung vornehmen um den eingangsspannungsbereich des ADC zu berücksichtigen.

### 3.3.1 Grenzfrequenz

Der Cf wurde mittels einem erstellen python programm berechnet.

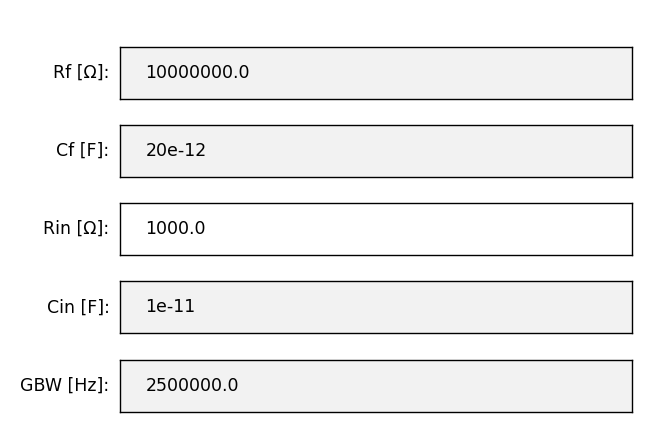
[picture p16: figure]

In diesem Programm konnte durch Iteratiefes ausprobieren ein wert für CF gefunden bei diesem die bandbreite der schaltung noch hochgenug ist um nicht zufiel signal wegzuschneiden, aber auch die stabilität der schaltung gegeben ist.

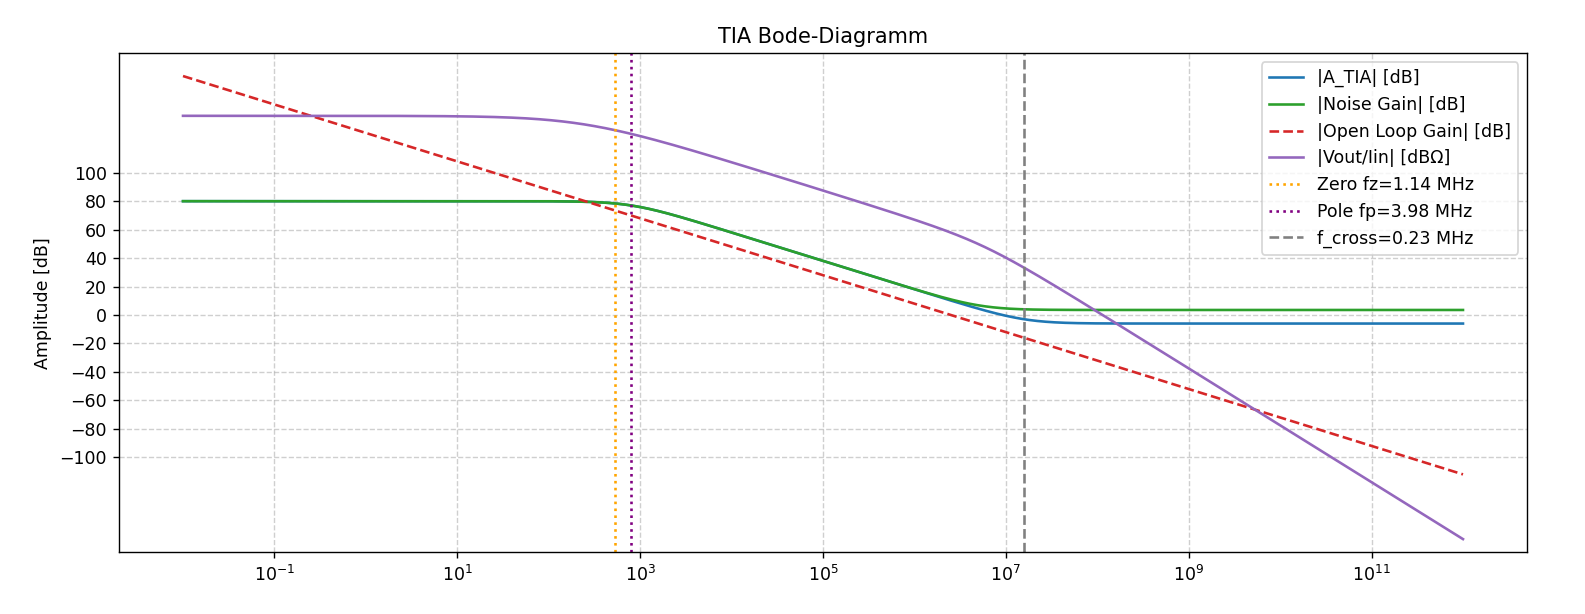
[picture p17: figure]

Von dem TU Wien Kontakt wurde auch empfolen die schaltung aufzubauen und die stabilität prüfen wenn diese nicht gegeben ist einen gröseren kondensator verwenden.

### 3.3.2 Thermisches Rauschen

Dieses Rauschen ensteht durch die inenntemperatur eines leiters und damit die bewegung von ladungsträgern in einem Leiter.

e_n =√(4*k*T*R_f)

k Bolzmankonstante = 1.380649×10⁻²³ J⋅K⁻¹

T die Temperatur in Kelvin

R der wert des Wiederstands

Diese Formel bedeutet das ein wärmerer als auch grösererwiederstand mehr rasuchen. Dies kann umgerechnet werden von Spannungsrasuchen zu Stromrauschen.

i_n = (e_n)/(R_f)

Temperature in K | 298,15
Bolzmankonstante | 1,38065E-23
Resistor in Meg | Thermisches Spannungs | Thermisches Strom
| Rauschen in nV/√Hz | Rauschen in fA/√Hz
0,1 | 40,578 | 405,779
1 | 128,318 | 128,318
10 | 405,779 | 40,578
100 | 1283,184 | 12,832
1000 | 4057,785 | 4,058

# 4 Schaltungs-erstellung Blockdiagramm

Es werden 2 Variablen spannungsquellen gebraucht vür die Gate als auch Darain spannung, da sloche meist mit DACs realiesiert werden, wird entweder ein DAC imt min 2 Channeln oder 2 DAC verwendet, es wird eher die erste variabte verwendet werden. da zumindest der Drain Anschluss stromliefern muss also belastet wird muss nach dem DAC ausgang ein Buffer eingebaut werden doch da es ein guter ansatz ist wird das bei beiden anschlüssen eingeplant. Diese buffer werden gleich mit einem Tiefpass fileter geplant da bei einem DAC ausgang zu hochfrequenzten störungen kommen kann.

Für die DAC Buffer müssen OPVs verwendet werden welche möglichst einen zero Offset haben um die eingestellte spannung nicht zu verfälschen, weiters müssen diese möglichst rasucharm sein um verälschen zu minimieren. Aus diesen Kreterien wurde der OPA189 ausgesucht.

Für die digitaliesierung des TIA muss ein ADC vberwendet werden da hohe samplerate gebraucht werden wird ein SAR ADC verwednet welcher eine Sample rate von bis zu 1MSps. Um eine einfache daten verarbeitung mit und da ADCs mit einer höheren bit zahl mit einem höheren preis kommen wird ein 16 bit SAR ADC verwendet, nämlich der ADS8681, dieser wurde ausgesucht aufgrund seiner SPI schnitschtelle seiner hohen samplerate und der einstellbaraen eingangs range.

Der OPV des TIA muss einen sehr geringen bias strom auf seinen + und – eingangs ports haben in einer grösenordnung die mindesetens um den faktor 10^3 kleiner ist als die zumessene größe, da messungen bis unter 1nA möglich sein sollen darf der bias current maximal 1pA betragen.

Weiters wäre eine geringe offset spannung des OPV sinvoll, doch dieser kann durch mehr punkt kallibrierung weggerechnet werden. Ein von der TU empfolener OPV für diese aufgabe ist der OPA928 doch dieser ist schwer zu implementirern, deswegen wurde auf ein älteres modell zurückgegriffen dem LMC6001.

## 4.1 Spannungsversorgung

Für die OPVs wurde eine Bipolare Versorgung von +-8V gewählt. Um diese zu bekommen werden 2 LODs verwendet, einer für die Positive versorgung und einer für die negative. Es werden LDOs verwendet da diese keinen Rippel erzeugen und viel rausch ärmer sind als DCDC wandler. Weiters dämpfen LDOs meist mit hohem faktor den rippel der versorgung zu unterdrücken, auch das genannt PSRR Power Supply Rejektion Ratio. Ein wichtiger Faktor für die OPV versorgung ist das sie langzeit stabiel ist und auch geringes eigenrauschen hat. Die beiden Ic welche häufig für diesen zweg verwendet werden sind die LT3094 für die negative spannungsversorgung und der LT3042 für die positive Versorgung, diese beiten die möglichkeit mittels eimen Widerstand die ausgangsspannung einzustellen.

Das gesammte Digital System ist auf eine Versorgung von 3,3V ausgelegt, und um diese zu verfügung zustellen wird auch ein LDO verwendet, da eine digitalversorgung keine low noise oder high accrucysy bracuht kann ein „Wald und Wiesen“ LDO verwendet werden. In diesem fall wird der TLV76733 verwendet.

### 4.1.1 LT3042

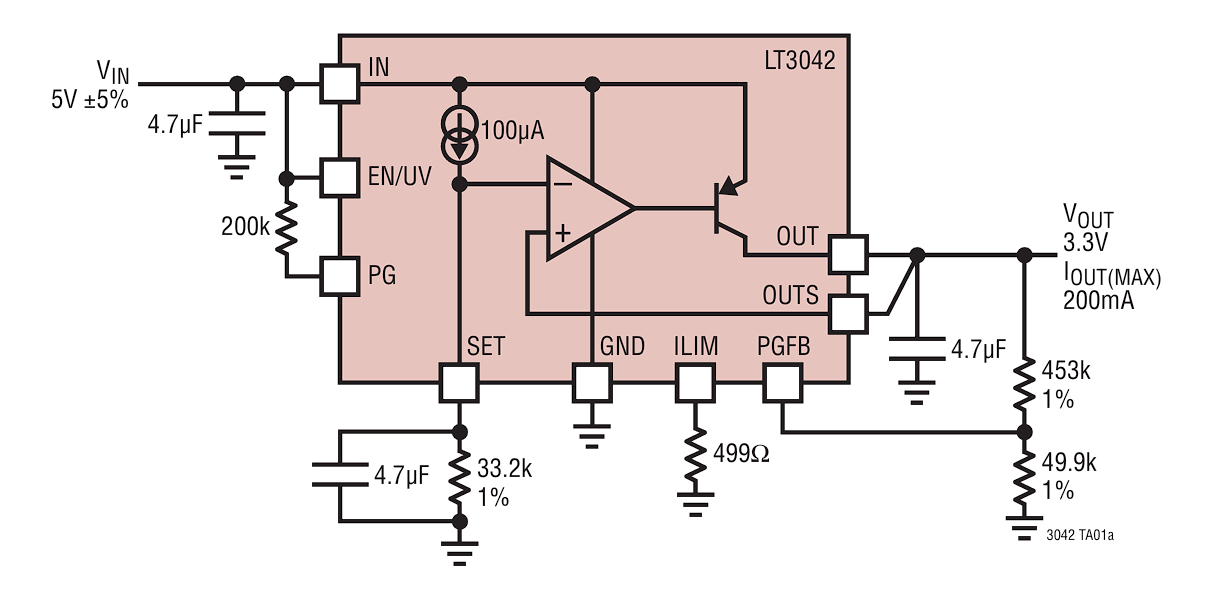
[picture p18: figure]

Mittels des SET Widerstand in dieser grafik 33.2k wird die ausgangsspannung gesetzt.

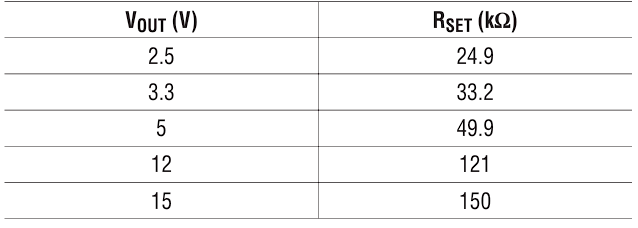
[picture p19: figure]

Mittels des ILIM Wiederstand kann eine Strombegränzung eingestellt werden, wenn diese funktion nicht gebrascuht wird kann dieser Pinn auf 0V gelegt werden.

Der Spannungsteiler der mit dem PIN PGFB verbunden ist stellt die Power Good spannung ein, wenn die spannung am PGFB pin über 0,3V steigt wird der PIN PG Auf 0V gezogen mittels einem Open Collectoe ausgangs, wenn die PGFB und PG funktion nicht gebracuht wird kann PGFB auf 0V gelegt werden kann und PG Floating gelassen wird. Das ist Falsch fehl funktion wenn auf 0V gezogen, eher auf Vin ziehen.

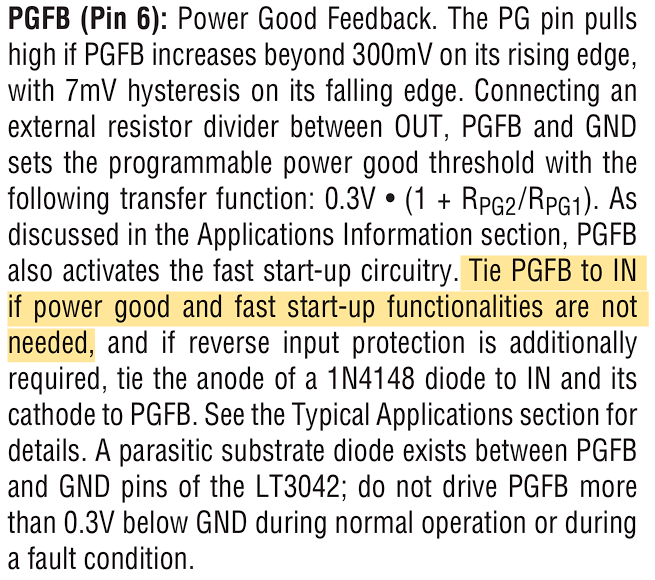
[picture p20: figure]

Die selben eigenschaften gelten für LT3094.

Da der DAC und der ADC eine 5V „Analog“ versorgung brauchen wird aufgrund der guten eigenschaften und um das Development zu erleichtern auch ein LT3042 verwendet.

### 4.1.2 TLV76733

Mit dem EN PIN kann die 3,3V Output angeschalten werden. dieser ic kann einen ausgangsstrom von 500mA liefern, dies wird für die ansteuerung der relais gebraucht.

# 5 ADC

Als adc wird der ADS8681 vorerst verwendet, doch da in der entwikluing der Platine viele kommunikations probleme aufgetreten sind, in zwischen zeit da keine einstellung auf dem ads8681 vorgenommen werden kann wird die standart einstellung verwendet.

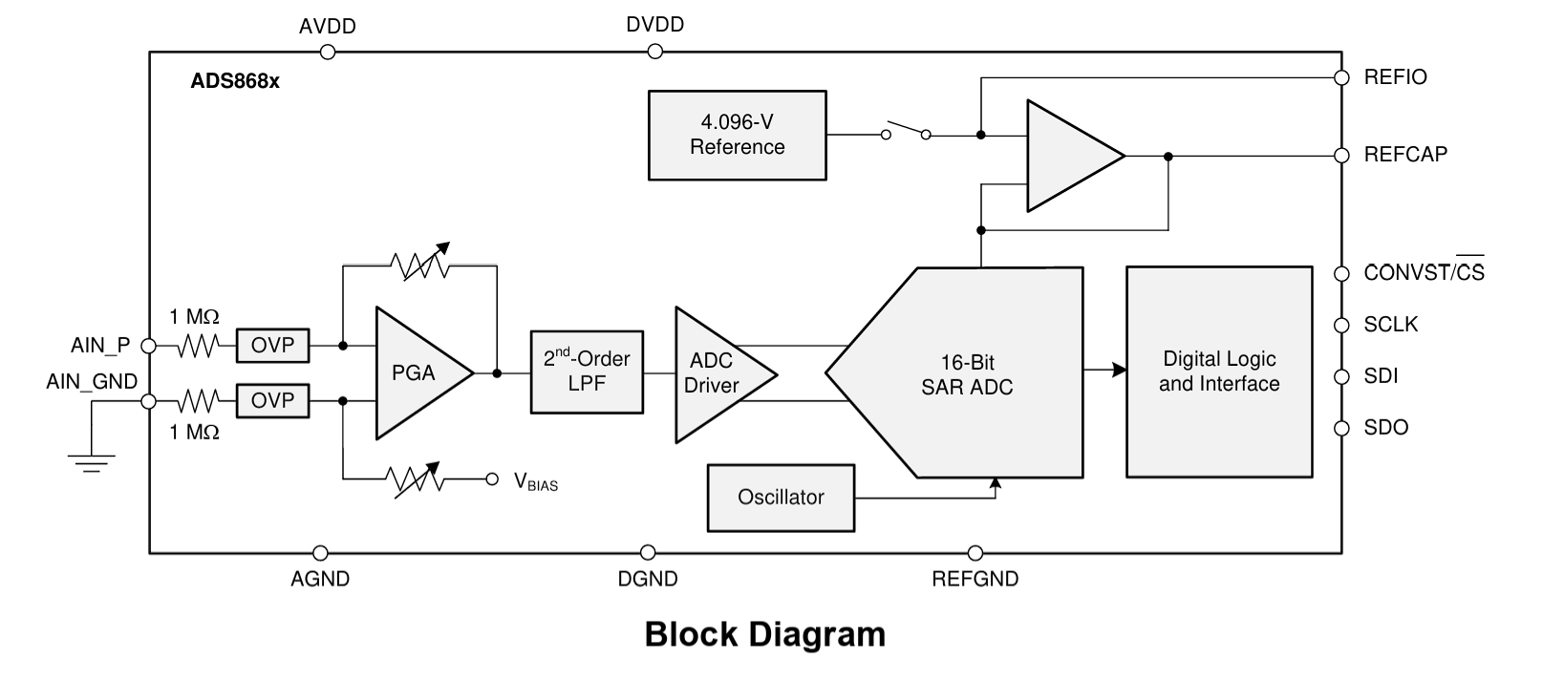
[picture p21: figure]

Bei einem ADS8681 kann intern umgeschalten werden zwischen der internen Referenz welche natürlich nicht die langezit stabilitär als auch temperat stabilität einer externen hat.

Anzudenken ist eine externe referenz auf der platine einzubauen um abgleiche zu treffen, von einer stabielen refernez z.b. LM399, ADR1000 oder ADR1001. Diese referenzen sind temperatur stabiel also beheizt, dies verbessert die stabilitär als auch sind diese referenzen extrem langzeit stabil unter 1 ppm / jahr.

## 5.1 Externe Referenzen

Diese refernezn haben eine hohe initerial abweichung vom soll wert, dieser wert muss nachgemessen werden von diesem können die refferenzen z.b. 4.096V abgeleitet werden. anders können auch nicht beheizte referenzen verwendet werden z.b. ADR4540 welche eine refenz von 4.096V. doch diese sind wie gesagt nicht beheizt und beiten deshalb nicht die gleiche temperatur und lagzeit stablität von unter 1 ppm/a bei diesen ist von einem drift von >10ppm/a zu rechnen.

Ein großer fall warum das einbauen von diesen ist das diese um die langzeit stabilitä zu bestitzen müssendise dauer bestromt sein allein durch einmalges ausschalten der versorgung kann zu einer änderung und dauerhafter änderung der stabilität von mehreren ppm führt.

Das bedeutet das ein ausfall freie versorgung gewärleistet werden muss z.b. entweder eine netztversorgung und nothaber eine akku versorgung doch ein anschluss an das netz das mann wieder ein 50hz brummen hat. Doch dies kann auch wieder durch z.bn. wie die verwednetern ldos verwednen.

Generell rachen soche refenzen viel platz auf der leiterplatte meist bnracuhen eine gesamte eruo card(100mm*160mm).

## 5.2 Temp_drifft

Auch die vorverstärker stufe des ADC und der internen DAC(da es ein SAR ist) haben einen temperatur dirft, deswegen ist es wichtig bei gleichbleibender temperatur zu messen. Deswegen muss vor einer messung „gewartet“ werden biss alle bauteile auf betriebs temperatur sind auch Thermal equilibrium, dies bedeutet das das gerät warmgelaufen ist bis zu der temperatur in welcher die abgegebene wärme energie gleich der abgegebene wärme energie ist.

## 5.3 Sample rate

Da Phänomne untersucht werden wollen die in einem bereich von wenigen us bis wenigen ms auftreten, deshalb wurde angenommen das bei einem phänomehen von 10us mindestens 10 sampels genommen werden wollen um es genügent aufzuzeichnen zu können wurde eine mindest samplerate von 100kHz angelegt.

## 5.4 Eingangsspannungsbereich

Beim ADS8681 ist der eingangsspannungsbereich programmierbar von:

/* = ±3 × VREF */

/* = ±2.5 × VREF */

/* = ±1.5 × VREF */

/* = ±1.25 × VREF */

/* = ±0.625 × VREF */

/* = 3 × VREF */

/* = 2.5 × VREF */

/* = 1.5 × VREF */

/* = 1.25 × VREF */

Das ist eine nützliche funktion bei einem messystem bei dem sich die range des messsignal sich ändert. Dies wäre praktisch doch wird nicht unbedingt benötigt. Da bei der test platine ein problem mit der kommunikation ADC konnte der eingangsbereich nicht umgestellt werden.

Um die range des TIA auf den fixewn eingangssapnnungsbereich zu bringen wurde ein inverterender verstärker verwendet. Da die range auf die einstellung Vref*1,25 vorgesehen war wurde eine dämpfung von 0.333 eingebaut. Denn vom TIA (wenn ein Rail to Rail) die versorgung wurde mit +-8V ausgelegt, kommt es zu 8V*0.333=2,663V. doch da die standart einstellung +-0,625*VREF=+-2,56V dies bedeutet da der TIA opv kein rail to rail ist also es ie zu einer 8V ausgangsspannung kommt geht sich der bereich aus. Doch wird nur ein positives signal erweartet dswegen wird die hälfte der range versoren.

## 5.5 ADS8681 Schaltung

Fehler die gemascht wurden war das RVS und REFIO verbunden wrde dies wurde im nachhinein behoden, denn RVS ist ein GP output und hat immer wenn eine messung möglich wäre REFIO auf gnd gezogen, der ADC wurde nicht beschädigt.

# 6 OPVs

Die auswahl der opv ist sehr kritisch für die eingengsstufe den TIA muss ein OPV verwendet werden welcher einen geringen eingangsstrom hat, besstenfalls noch einen geringen Output offset doch dieser kann aus den messungen heraus gerechnet werden.

Alerdings beötigen die OPV der Ausgangsstufe für GATE und DRAIN des MOSFET eine Geringe Ofset spannung da bei diesen das offset nicht nachgemessen wird und damit nicht herausgerechnet werden kann, anzudenken it eine digitale rückkopplung zumachen also den DAC ausgang mit enem ADC rückzumessen um die offset spannung rückzurechnen.

Nicht nur das rückführen des DAC signals könnte verwendet werden um das offset zu minimieren weiters aknn auch eine referenz wie im karpitel 5.1 verwendet werden zum abgleichen.

Für den TIA eingsngsstufe weurde von der TU der LMC6001 empolen da dieser einen eingangsstrom bias von maximal 25fA

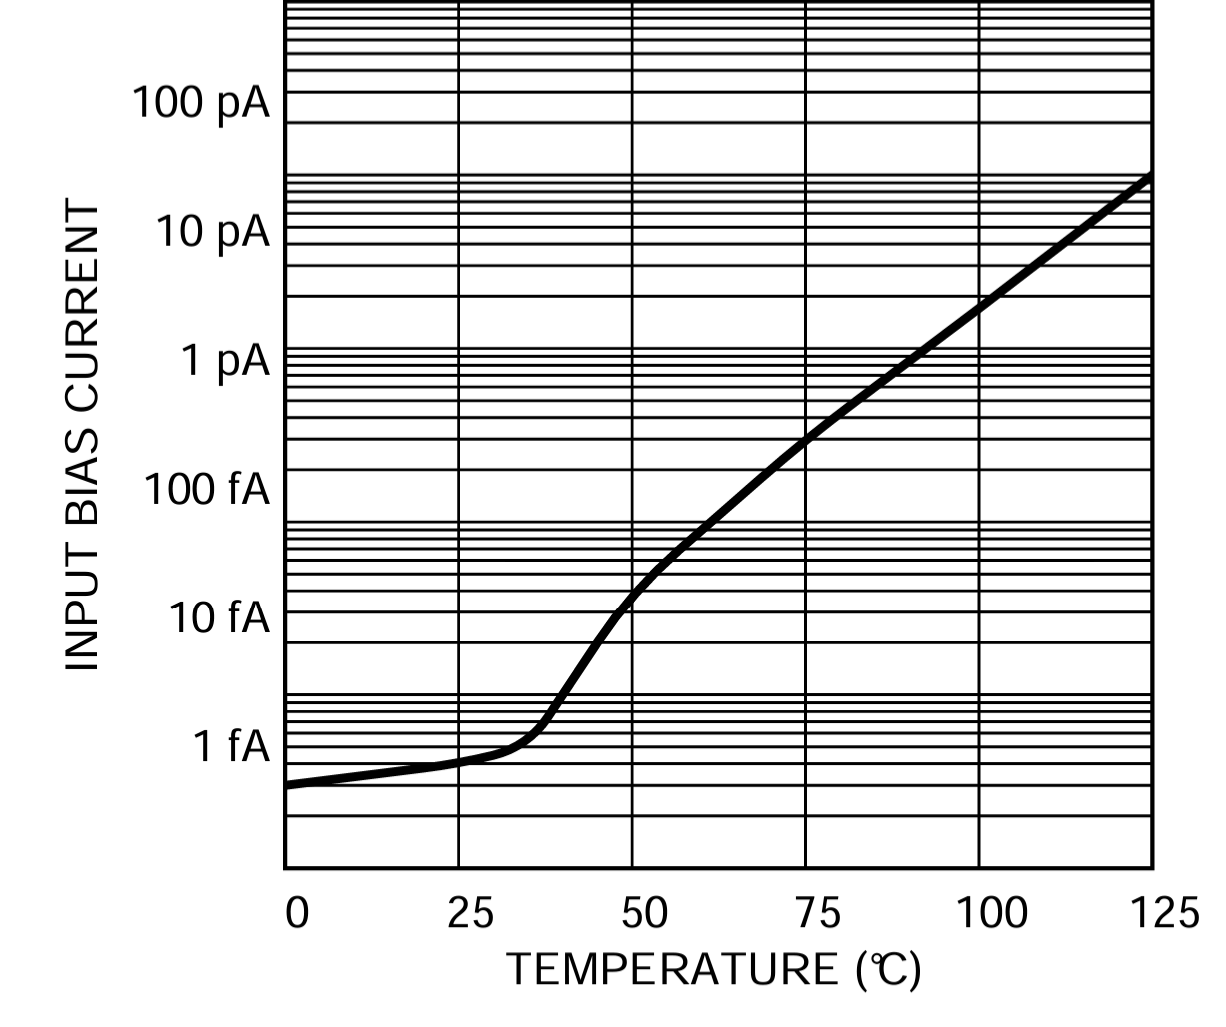
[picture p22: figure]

Der Temperatur dirft hat auch auf dieses Bauteil große auswirkungen doch da selbst bei 125°C der Eingangsstrom bias um den faktor 10 kleiner ist als das kleinste messsignal.

Für die Buffer oder 2verstärkerstufen wird ein OPA197 verwendetda dieser ein Einzelner 36-V-Präzisions-Operationsverstärker mit Rail-to-Rail-Eingang und Ausgang mit niedriger Offsetspannung ist.

# 7 DAC

Um die spannungen GATE DRAIn für den MOSFET einzustellen, sl ein DAC verwendet werden um eine variable spanung einzustellen, entweder 2 DAC für jede spannung oder einen dac mit 2 channels. Es wurde die 2 variante gewählt. Ebenfalls wie bei ADC wurde ein 16bit DAC verwendet. Ein AD5689RBRUZ.

## 7.1 AD5689 Schaltung

Bei AD5689 wird der gain eingang verwendet um zwischen einer 0-2.5V n einer 0-5V range unzuschalten.

# 8 Abschließende Bemerkungen

(Besondere Vorkommnisse während der Übung (z.B.: Feueralarm, NOT-AUS), besondere Erkenntnisse, Verbesserungsvorschläge)

# 9 Inventarliste

(Inventarliste – auch verwendete „Geräte des Übungsplatzes“ wie PC oder „Geräte der Abnahmeeinheit“, die BMKZ der verwendeten Geräte müssen mit den BMKZ in den Messschaltungen übereinstimmen! )

HTBL – Hollabrunn Seite 3 von 3

Elektronik – Technische Informatik Diplomarbeit Messung und Analyse von Feldeffekttranistoren

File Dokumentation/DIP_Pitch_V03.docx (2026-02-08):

HÖHERE TECHNISCHE BUNDESLEHRANSTALT

HOLLABRUNN

Höhere Abteilung für Elektronik – Technische Informatik

Klasse / Jahrgang: 4AHEL | Schüler: Peter Traube, Michael Watzek | Übungsleiter:
Version: V03 | Arbeitstitel: Experimentelle Bauteilcharakterisierung in der Mikroelektronik
Datum der Version: | Kontakt: Projektass. Dipl.-Ing. Patrick Reisinger TU Wien

Unterschrift:

Inhaltsverzeichnis

# 1 Einleitung

## 1.1 Motivation der Arbeit

Das Messen von Strömen in einer Größenordnung von Nanoampere ist eine nicht triviale Aufgabe. Solche Messysteme die solche Ströme zuverlässig messen können sind in der Regel Preisintensiv, und nicht für die Messung von RTN (Random Telegramm Noise) ausgelegt. Bei modernen MOSFET Systemen gewinnt die Analyse von RTN mehr an Bedeutung. Durch die Untersuchung von RTN kann Rückschlüsse auf Ladnungsfallen (Oxid Unreinheiten) innerhalb der Metalloxidschicht des MOSFET liefern, welche wiederum Auskunft geben über die Lebensdauer und Verschleißmechanismen innerhalb der Halbleiter.

## 1.2 Problemstellung bei der Messung sehr kleiner Ströme

Beim Messen von solchen Größen von Strömen können kleine Parameteränderungen beim Messvorgang einen großen Effekt auf die Genauigkeit des Ergebnisses haben. Neben Eigenschaftsveränderungen von Bauteilen durch Temperaturschwankungen und elektromagnetische Störungen von außen können Veränderungen auslösen. Besonders bei solchen Messungen ist deshalb auf die EMV- und Temperaturstabilität zu achten.

## 1.3 Zielsetzung der Diplomarbeit

Das Ziel der Arbeit ist die Entwicklung eines modularen Messsystems zur Messung von sehr kleinen Strömen zur Analyse Zeitkritischer Phänomene. Es soll ein rauscharmes Analog-Frontend entwickelt werden, welches zur Messung von Nanoampere-Strömen sowie zur Erfassung zeitabhängiger Rauschphänomene (Random Telegraph Noise, RTN) genutzt werden kann. Das Messsystem soll vollständig modular aufgebaut sein, um ein schnelles Wechseln der Messbereiche und der Größe des Messstromes zu ermöglichen.

Das entwickelte Messsystem soll in Betrieb genommen und anhand exemplarischer Messungen validiert werden.

# 2 Theoretische Grundlagen

## 2.1 Elektrisches Rauschen

### 2.1.1 1/f-Rauschen

Das 1/f-Rauschen beschreibt ein niederfrequentes Rauschphänomehenm dessen Leistung mit sinktinder Frequnez zunimmt. Dies tritt bei lagen messzeiten auf und äufeert sich in Siganldrifts. Bei der Messung kann 1/f-Rauschen die erfassung von Zeillich kritischen Effekten, wie RTN, erheblich beeinflussen und stellt eine limitierung in der Messgenauihkeit dar.

### 2.1.2 Temperaturrauschen

Termperaturänderungen ändern die elektrischen eigenschaften der Bauteile, insbesonders Offsetspannungen, Biasströme, Widerstände und Verstärkungsfaktoren. Selbst bei geringen Temperaturschwankungen können diese Effekte auftreten und zu messbaren signal veränderungen füren. Aus diesen Gründen ist eine möglicht temperaturstabile Umgebung und die Erfassund der Temperatur im Messaufbau von bedeutung, um temperatur bedingte effekte zu beurteilen.

### 2.1.3 EMV

Elektrische Strörungen

## 2.2 MOSFETs im Subthreshold- und nA-Bereich

## 2.3 Strommessung im nA-Bereich

# 3 Messsystem Konzept

## 3.1 Gesamtarchitektur

## 3.2 Messstrategie

# 4 Analoger Frontend-Entwurf

## 4.1 Transimpedanzverstärker

## 4.2 Signalaufbereitung

## 4.3 Analoge Versorgung

## 4.4 Bias-Spannungen

# 5 Analog-Digital-Wandlung

## 5.1 Auswahl des ADC

## 5.2 ADC-Beschaltung

## 5.3 Digitale Schnittstelle des ADC

# 6 Digitale Signalverarbeitung und Steuerung

## 6.1 Mikrocontroller-Anbindung

## 6.2 Erzeugung der Bias-Spannungen

HTBL – Hollabrunn Traube, Watzek / 4AHEL Seite 3 von 3

Diplomarbeit Experimentelle Bauteilcharakterisierung in der Mikroelektronik

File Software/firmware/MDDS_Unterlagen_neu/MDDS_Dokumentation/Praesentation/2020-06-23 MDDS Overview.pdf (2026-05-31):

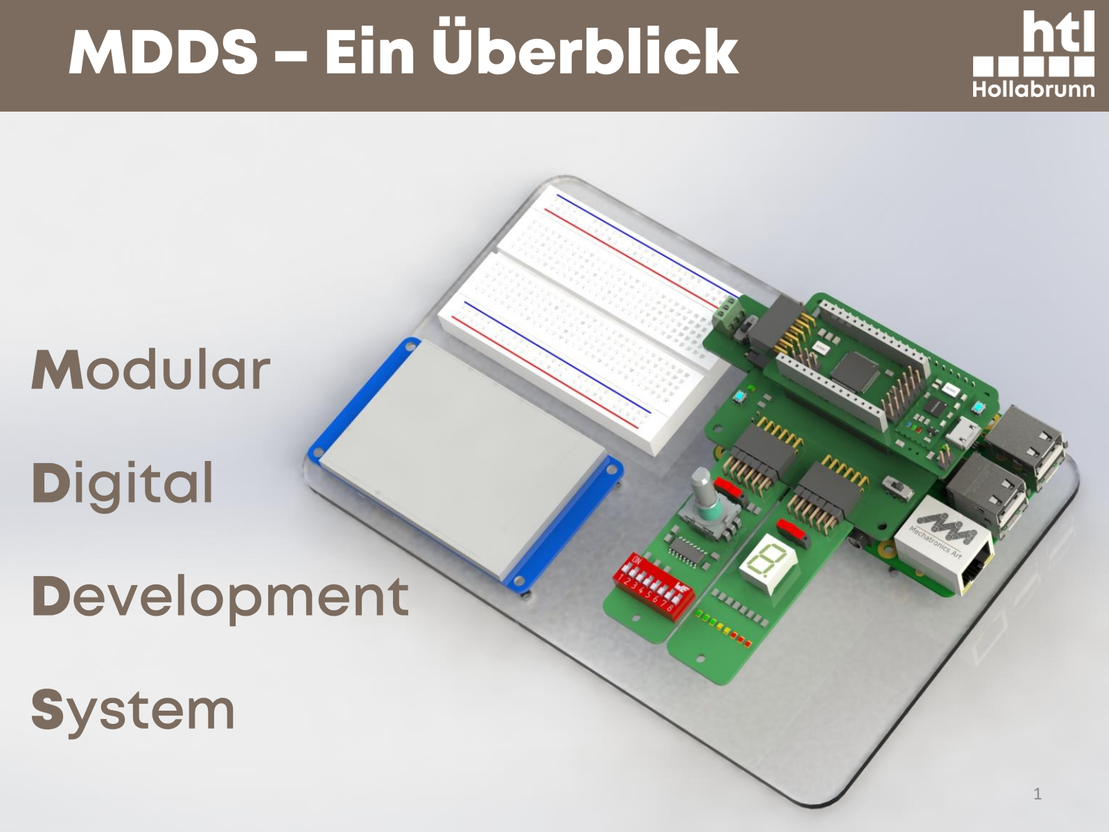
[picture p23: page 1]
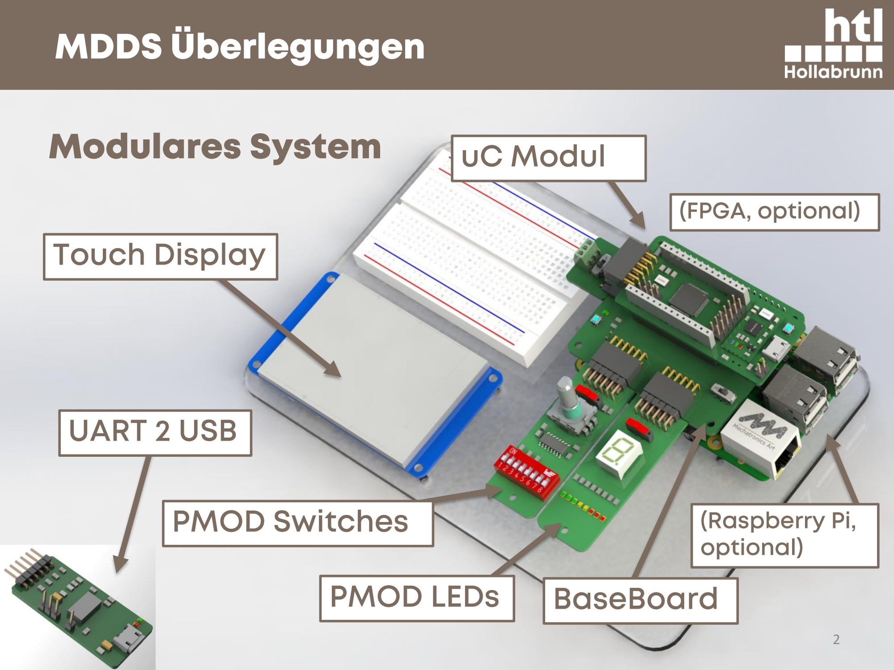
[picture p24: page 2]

••••



••••

Shield; VCC; GND; Micro-USB; USB_D-; USB_D+; TGT_SWCLK; TGT_SWIO; TGT_NRESET; TGT_TX; TGT_RX; Interface DAPLink.SchDoc; Target Target.SchDoc; V_USB; Power Supply Power_Supply.SchDoc

Shield; VCC; GND; Micro-USB; USB_D-; USB_D+; TGT_SWCLK; TGT_SWIO; TGT_NRESET; TGT_TX; TGT_RX; Interface DAPLink.SchDoc; Target Target.SchDoc; V_USB; Power Supply Power_Supply.SchDoc

•••


•••


•••


••


••


# MDDS_uC (Rev. 8)


(Priority 2)
Virtual Com Port (TX = PA9, RX = PA10)
DAPLink Debug Channel
Drag-n-Drop Flash Programming

PMOD interface, upper row:

PMOD interface, lower row:

# MDDS-Base Board (Rev.3)



D11
D10 | PB10 PB11

### UART3_TX

UART3_RX | I2C2 SDA I2C2 SCL

# MDDS-Base Board (Rev.3)

# BaseBoard connected

to Raspberry Pi B+/...

D6 | PC12
D7 | PC13 | UART1 (wakeup) | TAMPER-RTC
D13 | PB0 | TIM3_CH3 | ADC12_IN8
D14 | PB1 | TIM3_CH4 | ADC12_IN9

# Mögliche Kommunikations-Verbindungen:

# Raspberry UART0 <-> CM3 UART3

Raspberry I²C | <-> CM3 I²C1
Raspberry SPI | <-> CM3 SPI1
AIN4 | PA4 | SPI1_NSS | UART2_CK | ADC12_IN4
AIN0 | PA0 | UART2_CTS | TIM2_CH1_ETR | ADC12_IN0 | WKUP
D8 | PB8 | CAN_RX | TIM3_CH3
| TIM4_CH2 | I2C1 SDA | PB7 | D4
| TIM4_CH1 | I2C1 SCL | PB6 | D5
ADC12_IN1 | TIM2_CH2 | UART2_RTS | PA1 | AIN1
| TIM3_CH4 | CAN_TX | PB9 | D9
| | | PA2 | AIN2
| | | PA3 | AIN3

### ADC12_IN2 ADC12_IN3

### TIM2_CH3 TIM2_CH4

### UART2_TxD UART2_RxD

### AIN5

### AIN6

PA7

PA6

### ADC12_IN7

### ADC12_IN6 SPI1_MOSI

### TIM3_CH1 SPI1_MISO TIM3_CH2

ADC12_IN5 | SPI1_SCK | PA5 | D12

D1
D2
D3

PC1
PC2
PC3

### ADC12_IN11 ADC12_IN12 ADC12_IN13

ADC12_IN10 | PC0 | D0

### RESET

AREF | PB4


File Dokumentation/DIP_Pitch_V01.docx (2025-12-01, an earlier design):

HÖHERE TECHNISCHE BUNDESLEHRANSTALT

HOLLABRUNN

Höhere Abteilung für Elektronik – Technische Informatik

Klasse / Jahrgang: 4AHEL | Schüler: Peter Traube, Michael Watzek | Übungsleiter:
Version: V01 | Arbeitstitel: Experimentelle Bauteilcharakterisierung in der Mikroelektronik
Datum der Version: 03.11.2025 | Kontakt: Projektass. Dipl.-Ing. Patrick Reisinger TU Wien

Inhaltsverzeichnis

Anhang: Messprotokoll (Mitschrift bei der Übung)

# 1 Theorie zur Arbeit

## 1.1 Grundmessung

### 1.1.1 Messung der IdVg

Bei der Messung der Id/Vg-Charakteristik wird der Drainstrom in Abhängigkeit der angelegten Gate-Spannung erfasst. Hierzu wird die Gate-Spannung schrittweise variiert, während der resultierende Drainstrom kontinuierlich gemessen und aufgezeichnet wird. Die erhaltenen Daten ermöglichen die Bestimmung wichtiger Transistorparameter wie Threshold-Spannung (Vth) und mögliche Leckströme. Die Messung dient somit als Grundlage für die weiterführende Analyse von RTN.

### 1.1.2 Messung des RTN (Random Telegramm Noise)

#### 1.1.2.1 Random Telegramm Noise

Bei RTN handelt sich um ein „bitweises“ Rauschen, welches durch das Laden und Entladen von Unreinheiten im Metall-Oxid entsteht, dieses Rauschen lässt sich durch eine Veränderung im Id über die Zeit messen.

#### 1.1.2.2 Stressen

Beim Stressen handelt es sich um den Vorgang eine hohe Vg (bei einem P-kanal handelt es sich um eine besonders niedrige) an den Gate Anschluss anzulegen, um die Unreinheiten im Oxid bewusst zu laden, um RTN zu provozieren.

#### 1.1.2.3 Messung

Die Messung des RTN erfolgt durch die kontinuierliche Erfassung des Id unter definierten Bias Bedingungen. Dabei wird der Transistor nach einer Stresseinwirkung (ist auch ohne das vorherige Stressen möglich) in einen stationären Arbeitspunkt versetzt, und die zeitabhängige Änderung des Kanalstroms wird mit hoher zeitlicher Auflösung ausgezeichnet. Die Auswertung des Messsignals erlaubt Rückschlüsse auf die Zeitkonstanten des Ladens und Entladens, die Anzahl aktiver Fallen.

# 2 Aufbau der Analogschaltung

## 2.1 TIA

Für die Auswertung des Id wird ein Trans Impedanzwandler in einer Tiefpass Konfiguration verwendet. Dieser wandelt – je nach Messstufe – den gemessenen Strom in eine proportionale Spannung um, wobei typischerweise 1 V pro definierter Strompotenz eingestellt wird.
Die Dimensionierung des Rückkopplungsnetzwerks, bestehend aus Rf und Cf, bestimmt dabei sowohl die Verstärkung als auch die Bandbreite der Stufe. Die Werte für den Kompensationskondensator Cf werden mithilfe eines Programms grafisch ermittelt damit Stabilität des Verstärkers sicherzustellen.

Eine korrekte Auslegung des TIA ist entscheidend, um Messfehler durch Überschwingen, Rauschen oder Instabilität zu vermeiden und eine saubere Erfassung des Drainstroms über den gesamten Messbereich zu gewährleisten.

## 2.2 DAC Output Driver

Beim schnellen Umladen der parasitären Kapazitäten am MOSFET-Gate ist eine hohe Stromverfügbarkeit erforderlich. Der DAC-Output-Driver dient dazu, die vom Digital-Analog-Wandler erzeugte Spannung mit ausreichender Stromstärke und Anstiegszeit an das Gate des Transistors auszugeben. Dadurch wird sichergestellt, dass die eingestellte Gate-Spannung auch bei hohen Kapazitätswerten und schnellen Signaländerungen präzise anliegt. Der Gate Driver wird mit einem Rail-to-Rail Operationverstärker aufgeführt.

# 3 Digitalisierung

## 3.1 Bussystem

ür die Kommunikation zwischen dem ADC und dem DAC wird das SPI-Bussystem (Serial Peripheral Interface) verwendet. Dieses Bussystem ermöglicht eine schnelle und zuverlässige Datenübertragung, wodurch sich auch größere Datenmengen effizient verarbeiten lassen.

Das SPI-Protokoll basiert auf einem Master-Slave-Prinzip:

Der Master (in diesem Fall meist der Mikrocontroller oder FPGA) steuert die Kommunikation und taktet die Datenübertragung, während die Slaves (z. B. ADC oder DAC) auf die Befehle des Masters reagieren.

## 3.2 ADC

Für den TIA-ADC wird ein ADC mit einer Bitbreite von 16 Bit verwendet, um die gewünschte Auflösung zu erzielen. Ein ADC wird mit einer Sample-Rate von mindestens 1000 kSps angestrebt. Mit dieser Sample-Rate ist es möglich, transiente Analysen zu messen, als auch schnelle Signaländerungen zu erfassen.

# 4 Berechnung TIA

s=j*2*pi*f

## 4.1 Berechnung A_TIA

Berechnung der feadback impedanz:

Zf=(RF)/(1+s*Rf*Cf)

Berechnung der Eingangsimpedanz:

Zin=(Rin)/(1+s*Rin*Cin)

Berechnung der spannungs verstärkung A_TIA

A_(tia) = -(Zf)/(Zin)

# 5 Abschließende Bemerkungen

(Besondere Vorkommnisse während der Übung (z.B.: Feueralarm, NOT-AUS), besondere Erkenntnisse, Verbesserungsvorschläge)

# 6 Inventarliste

(Inventarliste – auch verwendete „Geräte des Übungsplatzes“ wie PC oder „Geräte der Abnahmeeinheit“, die BMKZ der verwendeten Geräte müssen mit den BMKZ in den Messschaltungen übereinstimmen! )

(V_(out))/(Id)= -((Zf)/())/((1+(Zf)/(Zin))/(A(s)))

HTBL – Hollabrunn Traube, Watzek / 4AHEL Seite 3 von 3

Diplomarbeit Experimentelle Bauteilcharakterisierung in der Mikroelektronik

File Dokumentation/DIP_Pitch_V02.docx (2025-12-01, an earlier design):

HÖHERE TECHNISCHE BUNDESLEHRANSTALT

HOLLABRUNN

Höhere Abteilung für Elektronik – Technische Informatik

Klasse / Jahrgang: 4AHEL | Schüler: Peter Traube, Michael Watzek | Übungsleiter:
Version: V02 | Arbeitstitel: Experimentelle Bauteilcharakterisierung in der Mikroelektronik
Datum der Version: 22.11.2025 | Kontakt: Projektass. Dipl.-Ing. Patrick Reisinger TU Wien

Unterschrift:

Inhaltsverzeichnis

# 1 Idee der Arbeit

Die Grund Idee ist ein programmierbares Messgerät zu erstellen welches verwendet werden kann um die einige Kennlinien eines MOSFET’s zu vermessen und diese hinterher auszuwerten. Die Kennlinien, die erstellt werden sollen, sind die IDVG (Drain Strom über Gate Spannung) und eine Transienten-Analyse des Source-Stromes. Die IDVG soll erstellt werden und als Grundlage für die restlichen Messungen verwendet werden, ebenfalls aus dieser Kennlinie soll, die des Rdson über die Gate Spannung erstellt werden. Es soll zu der Erleichterung der Messauswertung soll der Ausgang der verwendeten DAC’s nicht vermessen werden, sondern es wird der Soll-Wert, der sich aus der Ansteuerung ergeben sollte, verwendet. Für die Umwandlung und Aufbereitung des Source-Currents wird ein Trans-Impedanzwandler verwendet und um dessen Signal auf sie den Eingangsspannungsbereich des verwendeten ADC‘s zu wandeln wird ein invertierender Verstärker mit einer Verstärkung kleiner 1, um auch bei voll Aussteuerung des Trans-Impedanzwandlers in den Eingangsgrenzen des ADC‘s zu bleiben. Für die Kommunikation zwischen den ADC‘s, DAC’s und dem Micro-Controller wird ein SPI-Bus verwendet da dieser über eine sehr hohe Datenübertragungsrate verfügt. Als Micro-Controller wird der Cortex M3 verwendet da dieser über 2 separate SPI-Schnittstellen verfügt, als auch über eine Schnittstelle für eine Verbindung zwischen uC und PC. Da die USB-Verbindung über eine zu kleine Datenübertragungsrate verfügt um eine Liveübertragung der Messergebnisse ist der plan die gemessenen daten im Arbeitsspeicher des uC zwischenzuspeichern und nach der Fertigstellung der Messung an den PC übertragen werden. Um die Datenmenge im Arbeitsspeicher zu reduzieren ist es eine Überlegung die Werte arithmetische Mittelung direkt am Arbeitsspeicher durchzuführen z.b. 5 Messwerte zusammenrechnen und diese bei der Übertragung an den PC wieder durch 5 rechnen so wird automatisch unerwünschtes rauschen herausgemittelt. Dies ist anzudenken da es beim Kortex nur begrenzt Arbeitsspeicher zur Verfügung steht.

Bei einer Messung, die angedacht ist, allerdings schwer umzusetzen ist, handelt es sich um Random Telegramm Noise. Dieses Stör Signal welches durch das Landen und Entladen von Unreinheiten in der Isolationsschicht des MOSFET‘s auftreten kann hat eine ungefähre Größe

von wenigen nA.

# 2 Source Messstufen

## 2.1 Schaltung


## 2.2 Beschreibung

Der Feedback Wiederstand des Trans-Impedanzwandler stellt die Verstärkung des Source-stromes ein, da eine Messung von z.b. 100 uA bis zu wenigen nA möglich sein soll, muss der Feedback widerstand verändert werden. Der Feedback Widerstand wird so dimensioniert das bei dem gewünschten Source-stromes 1 V am Feedback Wiederstand abfallt z.b. bei einem Source-strom von 1uA wir der Feedback wiederstand mit 1MΩ dimensioniert. Der TIA wird symmetrisch mit +- 8V versorgt (+ub, -ub), daraus ergibt sich eine maximale Aussteuerung bei einem Source-strom von +-8uA (bei dem gewählten rail-to-rail Operationsverstärker). Da ein der Ausgangsspannungsbereich größer ist als der Eingangsspannungsbereich der meisten ADC’s, wird ein invertierender Verstärker mit einer Dämpfung von ~-0,3 verwendet;

±8V* -0,3=±2,4V

Da beide Verstärkerstufen der TIA und der Dämpfer haben eine negative Verstärkung, deswegen kommt es bei einem Stromfluss von dem Drain und source des MOSFET zu einer positiven ausgangs Spannung bis maximal 2,4 V.

Die Gate Spannung als auch die Drain Spannung werden von einem DAC und einer nach geschalteten verstärkerstufe. Der maximale Drain Strom hängt von der ausgangs Stufe des drain Verstärkers ab, denn wenn der MOSFET voll durchschaltet kann es zu hohen source strömen kommen und diese können den TIA-Operationsverstärker beschädigen. Deswegen ist eine Schaltungserweiterung anzudenken, welche eine zu hohe Gate Spannung verhindert oder den Source-strom limitiert.

## 2.3 Berechnung TIA

Quelle: https://www.ti.com/lit/an/sboa122/sboa122.pdf

In dieser Application-Note ist eine Formel für die Strom-Spannungs-wandlung zu finden welche umgeformt werden kann um die gesuchten Parameter zu bestimmen.

(U_(out))/(I_(in))=-(Z_f)/(1+((1+(Z_f)/(Z_G))/(A(s))))=-(Z_f *A_(ol) *Z_(in))/(Z_(in) *(A_(ol) +1)+Z_f +Z_(in) *s/(ω_A)+Z_f *s/(ω_A))

Mit Hilfe eines Python-Programms konnte grafisch ermittelt werden bei welchen Feedback Kondensator die größte Bandbreite und Stabilität bei den verschiedenen Meiststufen möglich ist. Für die Berechnung dafür musste ein eingangs Impedanz angenommen werden dies setzt sich zusammen aus dem widerstand Rdson und der parasitären Kapazitäten des MOSFET‘s:


Z_(in) =(R_(in))/(1+s*R_(in) *C_(in))

Z_f =(R_f)/(1+s*R_(in) *C_(in))

Aus diesen setzt sich die Spannungs Verstärkung zusammen, es ergibt sich die Formel eines normalen Invertierenden Verstärker:

A_(tia) =-(Z_f)/(Z_(in))

Das Noise-gain der Schaltung kann auch aus dem Application-Note extrahiert werden:

NG=1+(Z_f)/(Z_(in))

Daraus lässt sich schießen das zwar die Spannungs Verstärkung der Schaltung unter den 0dB punkt fallen allerdings das Noisegain minimal auf 0dB sinken kann, das bedeutet das das Rauschen minimal mit einer Verstärkung von 1 verstärkt wird.

Das Open-loop-Gain stellt sich aus dem Gain-bandwith-porduct und durch die Frequenz zusammen. Das Noise-gain muss sich für Stabilität mit dem Open-loop-Gain mit 20dB/dec schneiden. Die Stabilität kann auch über das Phasemargin ermittelt werden.

A_(ol) =(GBW)/f

Hier bei handelt es sich um eine vereinfachte Darstellung des Open-loop-Gain welches nicht Frequenz abhängig ist. Diese Formel beschreibt die frequenzabhängige Verstärkungsfunktion eines Operationsverstärkers im offenen Regelkreis:

A(s)=(A_(ol) *ω_a)/(s+ω_a)

Aus diesen Formeln wurde ein Python Skript erstellt welches mit Hilfe von matplotlib ein Bode-Diagramm erstellt und dieses ausgewertet werden kann, mithilfe dieses Programmes wurden folgende werte ermittelt:


*in diesem Programm stimmen die Frequenz Punkte nicht da besteht ein Rechnung Fehler

| Rf in MΩ | Cf in pF | Cin in pF | Fg in Hz | Fmesure in Hz
M4 | 0,01 | 50 | 40 | 318310 | 636620
M5 | 0,1 | 20 | 40 | 79577 | 159155
M6 | 1 | 5 | 40 | 31831 | 63662
M7 | 10 | 1 | 40 | 15915 | 31831
M8 | 100 | 1 | 40 | 1592 | 3183

*Für Rin wurde vom TU-Kontakt der Wert von 1000Ω vorgeschlagen, um das Berechnen zu erleichtern.

Die Frequenzen können ermittelt werden mit Hilfe der Formel:

F_g =1/(2*π*C_f *R_f)

Aus dieser Berechnung lässt sich die Grenz Frequenz der verschieden Messstufen Berechnungen und daraus wiederum die höchst sauber messbare Frequenz. Aus der Annahme das die Messfrequenz mindestens das doppelte das zumessende Signal ergibt sich eine mindest Abtast-fequenz aller Messstufen von 636kHz, da das wiederum die mindest Messfreuenz ist wird eine Messfrequenz gewählt die weit darüberliegt (~1Msps, bei höheren Messstufen kann eine niedrigere abtastrate gewählt werden, da eine M4 Messstufe voraussichtlich nicht gebaut wird muss auch nicht mit 1Msps abgetastet werden).

## 2.4 Source ADC

Das Aussuchen des ADC basiert auf den berechneten Gegebenheiten, eine abtastrate von 1Msps und durch den Kontakt an der TU wurde eine Auflösung von 16-bit vorgeschlagen. Der Eingangsbereich dieses ADC muss für mindestens 2,4V bipolar ausgelegt sein. Für die ersten Testversuche wurde der ADC „ADS8681“ ausgesucht mit einem Programmierbaren eingangs spannungsreich von +-2,56V bis hin zu +-12,288V und auch unipolar von +5,12V bis zu +12,288 und einer SPI-Schnittstelle, eine analoge Versorgung von 5V und eine digitale Versorgung von 3,3V, die eingangs Impedanz des Analog zu digital Konverter beträgt ungefähr 1MΩ. Der Eingang bandweite bei f-3dB beträgt 15kHz und bei f-0,1dB 2,5kHz.

Quelle: https://www.ti.com/lit/ds/symlink/ads8681.pdf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

Mithilfe dieses Referenzdesign wurde eine Test-Platine erstellt:

Quelle: https://www.ti.com/lit/df/tidrks6/tidrks6.pdf?ts=1763924205686

HTBL – Hollabrunn Traube, Watzek / 4AHEL Seite 3 von 3

Diplomarbeit Experimentelle Bauteilcharakterisierung in der Mikroelektronik

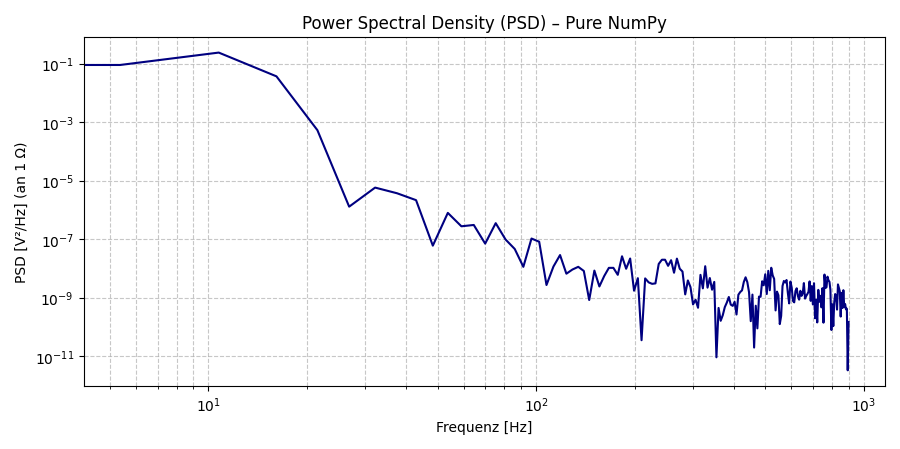
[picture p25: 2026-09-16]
Hardware/psd_10hz.png

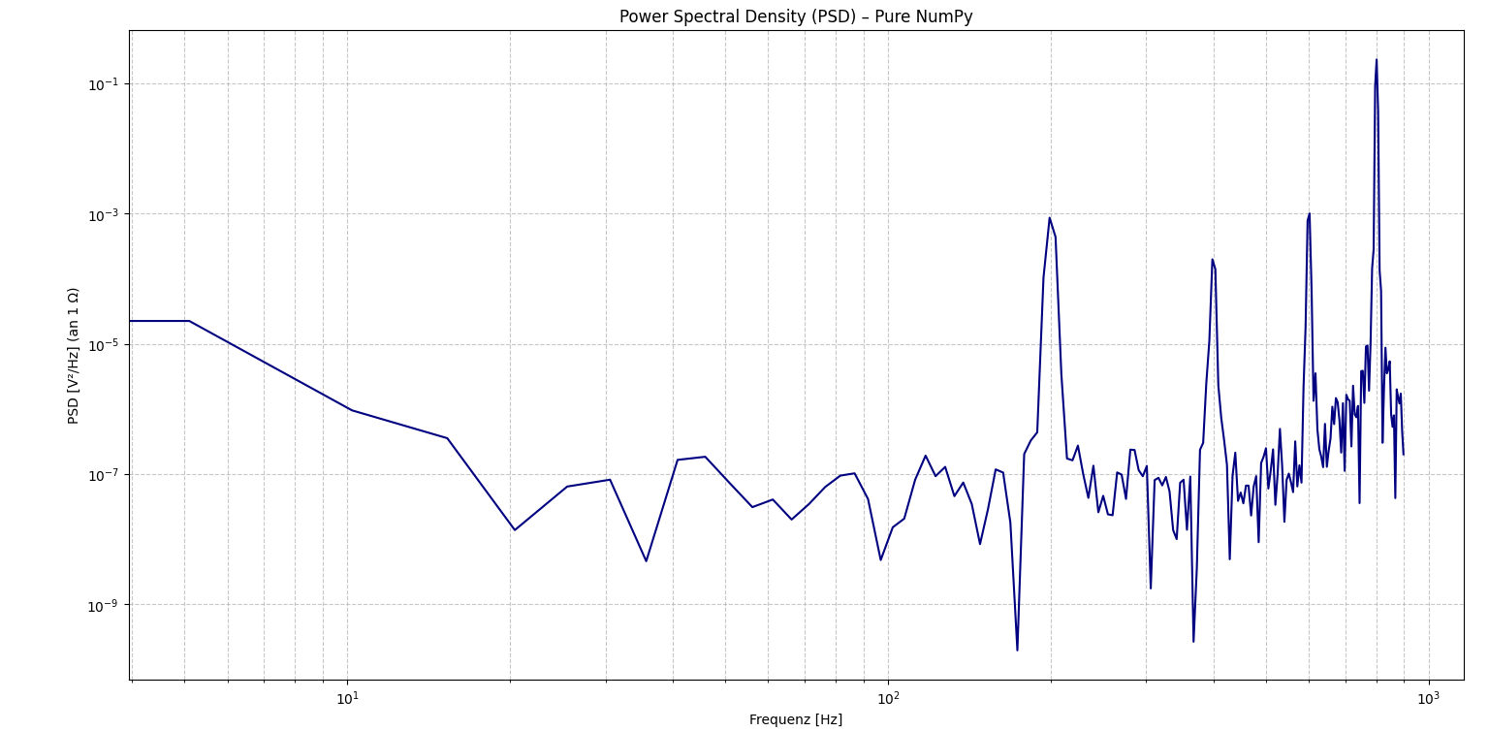
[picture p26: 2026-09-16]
Hardware/psd_1000hz.png

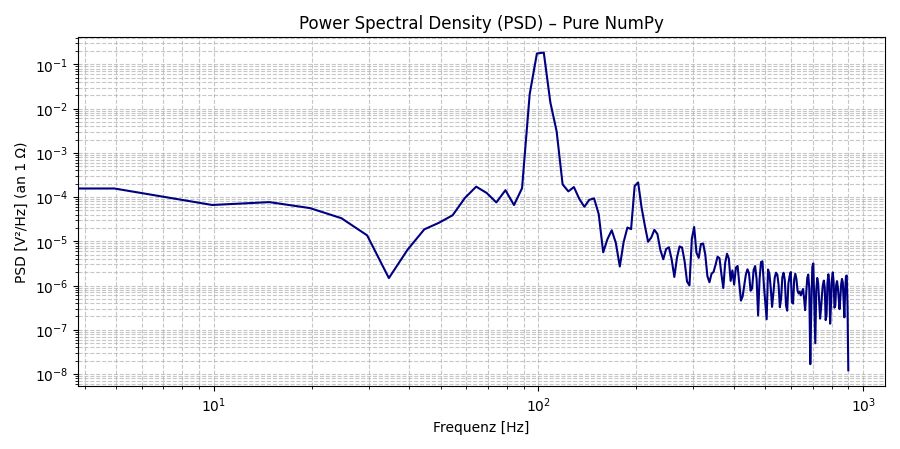
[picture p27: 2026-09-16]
Hardware/psd_100hz.png

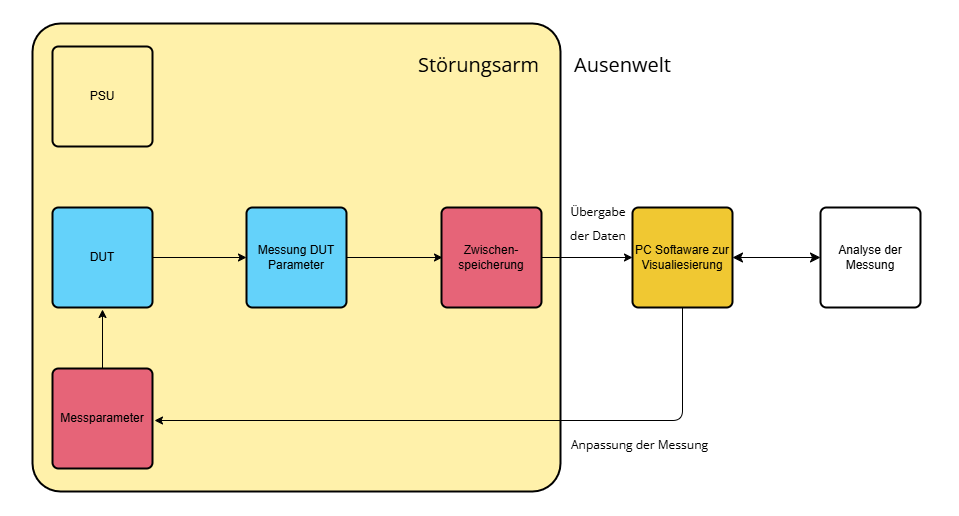
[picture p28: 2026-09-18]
Dokumentation/dokumentation_bilder/Untitled.png

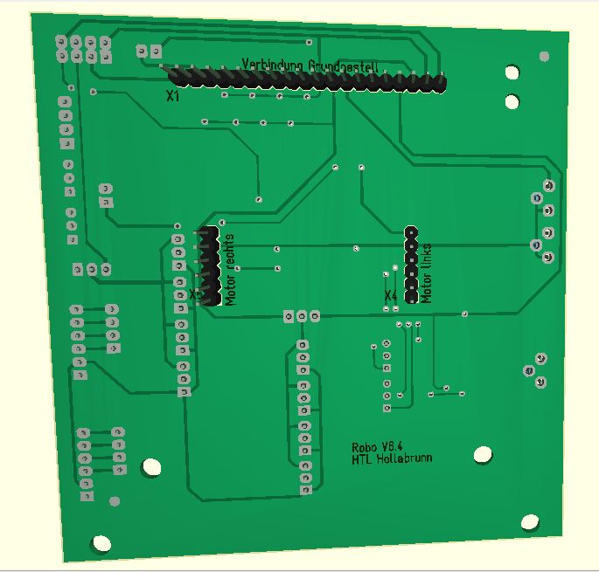
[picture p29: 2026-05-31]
Software/firmware/Unterlagen_ELLFI/2 Klasse EL/Hauptplatine_3D_Bot.JPG

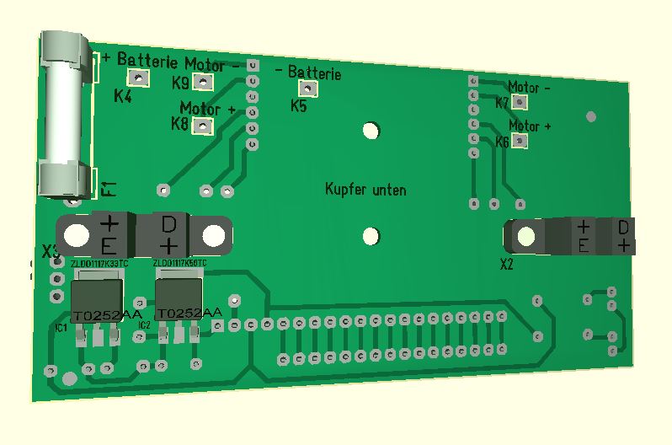
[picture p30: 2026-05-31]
Software/firmware/Unterlagen_ELLFI/1 Klasse EL/Verbindungsplatine_3D_Bot.JPG

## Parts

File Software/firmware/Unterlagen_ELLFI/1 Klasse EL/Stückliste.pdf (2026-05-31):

Pos | Name | Wert | Gehäuse
1 | C1 | 1µF | 2,54X5,08_RM5,08
2 | C2 | 1µF | 2,54X5,08_RM5,08
3 | C3 | 1µF | 2,54X5,08_RM5,08
4 | C4 | 1µF | 2,54X5,08_RM5,08
5 | D1 | Grün | LED_5MM_GRÜN
6 | D2 | Gelb | LED_5MM_GELB
7 | F1 | 6,3A | ESKA_Haltefedern_für_Sicherung_5x20
8 | IC1 | ZLDO1117K33TC | TO252AA
9 | IC2 | ZLDO1117K50TC | TO252AA
10 | K1 | Verbindung Grundgestell | 1X20_BUCHSE
11 | K2 | Motor rechts | 1X06_BUCHSE
12 | K3 | Motor links | 1X06_BUCHSE
35 | R1 | 390 | 0207
36 | R2 | 390 | 0207
37 | S1 | MIKRO-SCHIEBESCHALTER | SCHIEBE-SCHALTER_1-POL_8,5X3,5
38 | X2 | CNY37=TCST2000=TCST2103 | CNY37
39 | X3 | CNY37=TCST2000=TCST2103 | CNY37

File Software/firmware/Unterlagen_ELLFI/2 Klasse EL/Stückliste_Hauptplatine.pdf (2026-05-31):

Pos | Name | Wert | Gehäuse
1 | C1 | 22µF | SMD_R7X7_ELKO
2 | C2 | 100nF | 0603
3 | C3 | 100nF | 0603
4 | C4 | 100nF | 0603
5 | C5 | 10nF | 0603
6 | IC1 | 74AHC1G14DCK | SC70/5
7 | IC2 | 74AHC1G14DCK | SC70/5
8 | IC3 | 74AHC1G14DCK | SC70/5
9 | IC4 | 74AHC1G14DCK | SC70/5
10 | IC5 | 74AHC1G14DCK | SC70/5
11 | IC6 | 74AHC1G14DCK | SC70/5
12 | IC7 | L293DD | SO20
13 | IC8 | NE555D | SO8/WB3,9/P1,27
14 | R1 | 150 | 0805
15 | R2 | 150 | 0805
16 | R3 | 150 | 0805
17 | R4 | 150 | 0805
18 | R5 | 10k | 0805
19 | R6 | 10k | 0805
20 | R7 | 10k | 0805
21 | R8 | 10k | 0805
22 | R9 | 1K | 0805
23 | R10 | 50K | TRIMMER_CA6H
24 | R11 | 10k | 0805
25 | R12 | 1k | 0805
26 | R13 | 10k | 0805
27 | R14 | 1k | 0805
28 | R15 | 5K | TRIMMER_CA6H
29 | R16 | 5K | TRIMMER_CA6H
30 | R17 | 1k | 0805
31 | R18 | 1k | 0805
32 | R19 | 1k | 0805
33 | R20 | 1k | 0805
34 | R21 | 1k | 0805
35 | R22 | 1k | 0805
36 | R23 | 1k | 0805
37 | R24 | 1k | 0805
38 | V1 | 1N4148W | SOD123
39 | V2 | 1N4148W | SOD123
40 | X1 | Verbindung Grundgestell | Stiftleiste_1x20_G_2,54
41 | X2 | Linienfolger | 1X04_BUCHSE
42 | X3 | LDR´s | 1X02_BUCHSE
43 | X4 | Motor links | Stiftleiste_1x06_G_2,54
44 | X5 | Motor rechts | Stiftleiste_1x06_G_2,54
45 | X6 | Getriebe | 1X02_BUCHSE
46 | X7 | Motor_L | 1X03_BUCHSE
47 | X8 | Modul 1 | 1X06_BUCHSE

48 | X9 | Modul 2 | 1X06_BUCHSE
49 | X10 | Dat1 | 1X04_BUCHSE
50 | X11 | Dat2 | 1X04_BUCHSE
51 | X12 | Versorgung | 2X04_BUCHSE
52 | X13 | Jumper | Stiftleiste_1x03_G_2,54
53 | X14 | Jumper | Stiftleiste_1x03_G_2,54
54 | X15 | Jumper | Stiftleiste_1x03_G_2,54
55 | X16 | Jumper | Stiftleiste_1x03_G_2,54
56 | X17 | Jumper | Stiftleiste_1x03_G_2,54
57 | X18 | Jumper | Stiftleiste_1x03_G_2,54
58 | X19 | Jumper | Stiftleiste_1x03_G_2,54
59 | X20 | Jumper | Stiftleiste_1x03_G_2,54
60 | X21 | Jumper | Stiftleiste_1x03_G_2,54
61 | X22 | Jumper | Stiftleiste_1x03_G_2,54
62 | X23 | Motor_R | 1X03_BUCHSE
63 | X24 | PWM links | Stiftleiste_1x03_G_2,54
64 | X25 | PWM rechts | Stiftleiste_1x03_G_2,54

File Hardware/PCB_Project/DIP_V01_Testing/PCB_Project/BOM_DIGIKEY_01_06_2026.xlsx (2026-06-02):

HTL-Hollabrunn | Projektname: |  |  | Firma: |  |  |  |  | Datum:
Materialbestellung | ADFET |  |  | digikey |  |  |  |  | 2026-06-01
Antragsteller: Michael Watzek | Klasse: 4AHEL |  | Projektnummer: 10313
Bauteilinformation Name |  |  |  |  |  | Preis/Stück |  | Preis/VPE |  | Gesamt
 |  | Bestellnr. | benötigte Stückzahl | Stück/ VPE | Anzahl VPE | exkl. MWSt | inkl. MWSt | exkl. MWSt | inkl. MWSt | inkl. MWSt
22pF Capacitor Keramik 1206 low ESR low ESL C0G/NP0 |  | 399-C1206C220J2GACTUCT-ND | 2 | 2 | 1 | 0.390 | 0.468 | 0.780 | 0.936 | 0.936 | https://www.digikey.at/de/products/detail/kemet/C1206C220J2GACTU/2215424
CAP CER 0.1UF 50V X7R 1206 |  | 399-C1206C104J5RACTUCT-ND | 19 | 19 | 1 | 0.220 | 0.264 | 4.180 | 5.016 | 5.016 | https://www.digikey.at/de/products/detail/kemet/C1206C104J5RACTU/411249
CAP CER 10UF 16V X7R 1206 low ESL low ESR |  | 399-C1206C106K4RACTUCT-ND | 13 | 13 | 1 | 0.270 | 0.324 | 3.510 | 4.212 | 4.212 | https://www.digikey.at/de/products/detail/kemet/C1206C106K4RACTU/789657
CAP CER 4.7UF 50V X7R 1206 |  | 399-C1206C475K5RACTUCT-ND | 4 | 4 | 1 | 0.340 | 0.408 | 1.360 | 1.632 | 1.632 | https://www.digikey.at/de/products/detail/kemet/C1206C475K5RACTU/5119822
CAP CER 1UF 25V X7R 1206 |  | 399-C1206C105K3RACTUCT-ND | 7 | 7 | 1 | 0.190 | 0.228 | 1.330 | 1.596 | 1.596 | https://www.digikey.at/de/products/detail/kemet/C1206C105K3RACTU/411254
1N4148W-7 Diode SDO123_DIO |  | 1N4148W-FDICT-ND | 4 | 4 | 1 | 0.140 | 0.168 | 0.560 | 0.672 | 0.672 | https://www.digikey.at/de/products/detail/diodes-incorporated/1N4148W-7-F/814371
BNC Elbow Connector |  | 343-CONBNC002-ND | 4 | 4 | 1 | 1.880 | 2.256 | 7.520 | 9.024 | 9.024 | https://www.digikey.at/de/products/detail/te-connectivity-linx/CONBNC002/16013841
RES SMD 10K OHM 0.1% 1/4W 1206 |  | YAG2329CT-ND | 10 | 10 | 1 | 0.180 | 0.216 | 1.800 | 2.160 | 2.160 | https://www.digikey.at/de/products/detail/yageo/RT1206BRD0710KL/1079472
RES SMD 33K OHM 0.1% 1/4W 1206 |  | YAG5107CT-ND | 1 | 1 | 1 | 0.200 | 0.240 | 0.200 | 0.240 | 0.240 | https://www.digikey.at/de/products/detail/yageo/RT1206BRE0733KL/1080313
78.7k Resistor SMD 1206 Dünnschicht 0,1% |  | P78.7KBCCT-ND | 2 | 2 | 1 | 0.230 | 0.276 | 0.460 | 0.552 | 0.552 | https://www.digikey.at/de/products/detail/panasonic-industry/ERA-8AEB7872V/3071174
0 Resistor SMD 1206 Dünnschicht |  | 749-MCA12060Z0000ZP500CT-ND | 3 | 3 | 1 | 0.080 | 0.096 | 0.240 | 0.288 | 0.288 | https://www.digikey.at/de/products/detail/vishay/MCA12060Z0000ZP500/26633624
1k Resistor SMD 1206 1% |  | RNCP1206FTD1K00CT-ND | 6 | 6 | 1 | 0.080 | 0.096 | 0.480 | 0.576 | 0.576 | https://www.digikey.at/de/products/detail/stackpole-electronics-inc/RNCP1206FTD1K00/2240337
RES SMD 4.7K OHM 1% 1/4W 1206 |  | 13-RT1206FRE074K7LCT-ND | 4 | 4 | 1 | 0.080 | 0.096 | 0.320 | 0.384 | 0.384 | https://www.digikey.at/de/products/detail/yageo/RT1206FRE074K7L/1083255
RES SMD 3.9K OHM 1% 1/4W 1206 |  | 13-RT1206FRE073K9LCT-ND | 2 | 2 | 1 | 0.080 | 0.096 | 0.160 | 0.192 | 0.192 | https://www.digikey.at/de/products/detail/yageo/RT1206FRE073K9L/1083196
RES SMD 2.7K OHM 1% 1/4W 1206 |  | 13-RT1206FRE072K7LCT-ND | 1 | 1 | 1 | 0.080 | 0.096 | 0.080 | 0.096 | 0.096 | https://www.digikey.at/de/products/detail/yageo/RT1206FRE072K7L/1083113
49.9k Resistor SMD 1206 0,1% Dünnschicht |  | YAG2053CT-ND | 1 | 1 | 1 | 0.180 | 0.216 | 0.180 | 0.216 | 0.216 | https://www.digikey.at/de/products/detail/yageo/RT1206BRD0749K9L/1079848
LT3042EMSE#TRPBF Ultralow Noise LDO 200mA |  | LT3042EMSE#TRPBFCT-ND | 2 | 2 | 1 | 6.430 | 7.716 | 12.860 | 15.432 | 15.432 | https://www.digikey.at/de/products/detail/analog-devices-inc/LT3042EMSE-TRPBF/5233182
LT3094EMSE#TRPBF Ultralow Noise LDO 500mA Negative |  | 505-LT3094EMSE#TRPBFCT-ND | 1 | 1 | 1 | 7.790 | 9.348 | 7.790 | 9.348 | 9.348 | https://www.digikey.at/de/products/detail/analog-devices-inc/LT3094EMSE-TRPBF/9606784
OPA197IDBVR Single precisiopn rail-to-rail low offset OPV |  | 296-47813-1-ND | 3 | 3 | 1 | 1.500 | 1.800 | 4.500 | 5.400 | 5.400 | https://www.digikey.at/de/products/detail/texas-instruments/OPA197IDBVR/5962128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
TLV76733DGNR 1A 3,3V LDO |  | 296-TLV76733DGNRCT-ND | 1 | 1 | 1 | 0.820 | 0.984 | 0.820 | 0.984 | 0.984 | https://www.digikey.at/de/products/detail/texas-instruments/TLV76733DGNR/15856577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
2N7002DW Dual Mosfet |  | 2N7002DWCT-ND | 2 | 2 | 1 | 0.430 | 0.516 | 0.860 | 1.032 | 1.032 | https://www.digikey.at/de/products/detail/onsemi/2N7002DW/1785764
DS28E07R+T 1-Wire EEPROM |  | 175-DS28E07+TCT-ND | 1 | 1 | 1 | 1.620 | 1.944 | 1.620 | 1.944 | 1.944 | https://www.digikey.at/de/products/detail/analog-devices-inc-maxim-integrated/DS28E07-T/5396363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
AD5689RBRUZ Dual 16-Bit DAC |  | 505-AD5689RBRUZ-ND | 1 | 1 | 1 | 11.700 | 14.040 | 11.700 | 14.040 | 14.040 | https://www.digikey.at/de/products/detail/analog-devices-inc/AD5689RBRUZ/3925751
Schüler: …........................................................ |  | Projektleiter: …........................................................ |  |  |  | Lehrerkürzel: |  | Summe: |  | €75.97
 |  |  |  |  |  |  |  | inkl. MWSt
Unterschrift |  | Unterschrift

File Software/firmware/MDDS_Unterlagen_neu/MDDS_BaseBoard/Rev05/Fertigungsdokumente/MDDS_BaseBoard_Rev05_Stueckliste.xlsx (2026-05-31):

Line # | Name | Description | Designator | Quantity | Footprint | Manufacturer 1 | Manufacturer Part Number 1 | Manufacturer Lifecycle 1 | Supplier 1 | Supplier Part Number 1 | Supplier Unit Price 1 | Supplier Subtotal 1
 | 1k | Resistor 0805 5% 0.125W | R1 | 1 | 6-0805_M | TE Connectivity | CRG0805F1K0 | Volume Production | Digi-Key | A106056CT-ND | 0.08857 | 0.08857
 | 3.9k | Resistor 0805 5% 0.125W | R2, R3 | 2 | 6-0805_M | TE Connectivity | CRG0805F3K9 | Volume Production | Digi-Key | A126369CT-ND | 0.08857 | 0.17713
 | 4.7k | Resistor 0805 5% 0.125W | R6, R7, R8, R9, R10 | 5 | 6-0805_M | RND Components | RND1550805S8J0472T5E | Unknown | Distrelec | 30056891 | 0.0125 | 6.25
 | 12k | Resistor 0805 5% 0.125W | R5 | 1 | 6-0805_M | RND Components | RND1550805S8F1202T5E | Unknown | Distrelec | 30056730 | 0.0185 | 1.85
 | 100n | Capacitor | C1 | 1 | C0805 | Kyocera AVX | 08055C104KAT2A | Volume Production | Digi-Key | 478-1395-1-ND | 0.09742 | 0.09742
 | 680R | Resistor 0805 5% 0.125W | R4 | 1 | 6-0805_M | RND Components | RND1550805S8J0681T5E | Unknown | Distrelec | 30056902 | 0.0125 | 6.25
 | 434153017835 | 3.5x2.9mm SMD J-Bend WS-TASV, height 1.7 mm, 350 gf | S1 | 1 | 434153017835 | Wurth Electronics | 434153017835 | New Product | Digi-Key | 732-10143-6-ND | 0.49597 | 0.49597
 | DS18B20+ | Programmable Resolution Digital Thermometer, 1-Wire Interface, ±0.5°C Accuracy, 3-Pin TO92, -55°C to +125°C, Pb-Free | D2 | 1 | Q3+1 | Maxim | DS18B20+ | Not Recommended for New Design | Digi-Key | DS18B20+-ND | 3.86 | 3.86
 | GND | WR-PHD 2.54 mm THT Pin Header, 02p | X12 | 1 | 61300211121 | Wurth Electronics | 61300211121 | Volume Production | Digi-Key | 732-5315-ND | 0.10197 | 0.10197
 | I2C1 Pull Up Jumper | WR-PHD 2.54 mm THT Dual Pin Header, 04p | X11 | 1 | 61300421121 | Wurth Electronics | 61300421121 | Volume Production | Distrelec | 30024524 | 0.41 | 2.05
 | I2C2 Pull Up Jumper | WR-PHD 2.54 mm THT Dual Pin Header, 04p | X10 | 1 | 61300421121 | Wurth Electronics | 61300421121 | Volume Production | Distrelec | 30024524 | 0.41 | 2.05
 | I/O Power Source Select | WS-SLTV THT Mini Slide Switch, Same Side Connection, DPDT | X7 | 1 | 452404020202 | Wurth Electronics | 452404020202 | Unknown | Digi-Key | 732-13666-ND | 2.09 | 2.09
 | Jumper | 2 Position Jumper with test point |  | 4 |  | Assmann | AKSPT/GBLACK | Manual Solution | RSComponents | 674-2384 | 0.247 | 0.988
 | LED Green 2mA | SMD LED green 0805 2mA | V1 | 1 | LED_0805_GREEN | Kingbright | APT2012LZGCK | Volume Production | Digi-Key | 754-1939-1-ND | 0.49597 | 0.49597
2 | M24C32RMN1 | 32 Kbit Serial I²C Bus EEPROM | D1 | 1 | SOP8_N | STMicroelectronics | M24C32-RMN6TP | Volume Production | Digi-Key | 497-8644-6-ND | 0.15942 | 0.15942
9 | MAX1000 left (J1) | WR-PHD 2.54 mm Socket Header, 14p | X1 | 1 | 61301411821 | Wurth Electronics | 61301411821 | Unknown | Distrelec | 30024905 | 0.83 | 4.15
10 | MAX1000 right (J2) | WR-PHD 2.54 mm Socket Header, 14p | X2 | 1 | 61301411821 | Wurth Electronics | 61301411821 | Unknown | Distrelec | 30024905 | 0.83 | 4.15
11 | Raspberry Pi 3 Connector | GPIO Header for Raspberry Pi A+/B+/Pi 2/Pi 3 - 2x20 | X3 | 1 | rpi | Wurth Electronics | 61304021821 | Unknown | Distrelec | 30024958 | 1.45 | 1.45
12 | PMOD1 | WR-PHD 2.54 mm Angled Dual Socket Header, 12p | X4 | 1 | 613012243121 | Wurth Electronics | 613012243121 | Unknown | Distrelec | 30024901 | 1.03 | 3.09
13 | PMOD2 | WR-PHD 2.54 mm Angled Dual Socket Header, 12p | X5 | 1 | 613012243121 | Wurth Electronics | 613012243121 | Unknown | Distrelec | 30024901 | 1.03 | 3.09
14 | PMOD3 | WR-PHD 2.54 mm Angled Socket Header, 6p | X6 | 1 | 613006143121 | Wurth Electronics | 613006143121 | Unknown | Distrelec | 30024873 | 0.56 | 1.68
15 | 02p | WR-PHD 2.54 mm THT Pin Header, 02p | X13 | 1 | 61300211021 | Wurth Electronics | 61300211121 | Volume Production | Digi-Key | 732-5315-ND | 0.10197 | 0.10197
17 | 06p | WR-PHD 2.54 mm THT Dual Pin Header, 06p | X9 | 1 | 61300621121 | Wurth Electronics | 61300621121 | Volume Production | Distrelec | 30024527 | 0.38 | 3.8

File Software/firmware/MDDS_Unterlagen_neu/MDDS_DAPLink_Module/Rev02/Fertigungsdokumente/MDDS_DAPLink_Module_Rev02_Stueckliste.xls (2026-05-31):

Line # | Name | Description | Designator | Quantity | Value | Manufacturer 1 | Manufacturer Part Number 1 | Manufacturer Lifecycle 1 | Supplier 1 | Supplier Part Number 1 | Supplier Unit Price 1 | Supplier Subtotal 1
 | 18p | CAP 25V ±20% 0603 | C1, C3 | 2 | 18p | KEMET | C0603C180K3GACTU | Volume Production | Digi-Key | 399-9019-6-ND | 0.24797 | 0.49595
 | 100n | CAP 25V ±20% 0603 | C2, C4, C5 | 3 | 100n | KEMET | C0603C104Z3VACTU | Volume Production | Digi-Key | 399-1100-1-ND | 0.08856 | 0.26569
 | LPC11U35FHI33/501 | 32-bit ARM Cortex-M0 MCU, LPC1100L Series, 32 kB Flash, 8 kB SRAM, 1 SPI, ADC, 32-Pin HVQFN | D1 | 1 |  | NXP Semiconductors | LPC11U35FHI33/501, | Volume Production | Digi-Key | 568-9586-ND | 3.99 | 3.99
 | 1.5k | Resistor 0603 | R1 | 1 | 1.5k | Vishay | CRCW06031K50FKEAHP | Volume Production | Digi-Key | 541-1.50KSDKR-ND | 0.15056 | 0.15056
 | 10k | Resistor 0603 | R2, R3 | 2 | 10k | Vishay | CRCW060310K0FKEAHP | Volume Production | Digi-Key | 541-10.0KSDKR-ND | 0.15056 | 0.30111
 | 1k | Resistor 0603 | R4, R5, R6 | 3 | 1k | Vishay Dale | CRCW06031K00FKEAHP | Volume Production | Digi-Key | 541-1.00KSCT-ND | 0.15056 | 0.45167
 | BSS84P | P-Channel SIPMOS Small-Signal-Transistor, -60 V VDS, -0.17 A ID, -55 to 150 degC, PG-SOT23, Reel, Green | V1 | 1 |  | Infineon | BSS84PH6327XTSA2 | Volume Production | Digi-Key | BSS84PH6327XTSA2CT-ND | 0.29226 | 0.29226
 | Green LED 2mA | Mono-color Chip LED Waterclear, size 0603, Green, 2mA | V2 | 1 | 2mA Green | Kingbright | APT1608LZGCK | Volume Production | Digi-Key | 754-1934-1-ND | 0.49595 | 0.49595
 | Red LED 2mA | Mono-color Chip LED Waterclear, size 0603, Red, 2mA | V3 | 1 | 2mA Red | Kingbright | APT1608LSECK/J3-PRV | Volume Production | Digi-Key | 754-1930-1-ND
 | Blue LED 2mA | Mono-color Chip LED Waterclear, size 0603, Blue, 2mA | V4 | 1 | 2mA Blue | Kingbright | APT1608LVBC/D | Volume Production | Digi-Key | 754-1933-1-ND | 0.49595 | 0.49595
 | 12MHz | Ceramic SMD Crystal, 12 MHz, +/- 20 ppm, 70 Ohm, -20 to 70 degC, 4-Pin SMD, RoHS, Tape and Reel | Y1 | 1 | 12MHz | Abracon | ABM3B-12.000MHZ-B2-T | Volume Production | Digi-Key | 535-9116-1-ND | 0.61108 | 0.61108

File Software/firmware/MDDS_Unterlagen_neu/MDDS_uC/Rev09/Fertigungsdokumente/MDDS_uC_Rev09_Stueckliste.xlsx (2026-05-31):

Line # | Name | Description | Designator | Quantity | Footprint | Manufacturer 1 | Manufacturer Part Number 1 | Manufacturer Lifecycle 1 | Supplier 1 | Supplier Part Number 1 | Supplier Unit Price 1 | Supplier Subtotal 1
 | 1k | Resistor | R19, R20 | 2 | RESC0805(2012)_N | TE Connectivity | 1623131-1 | Volume Production | Digi-Key | A106056CT-ND | 0.08857 | 0.17713
 | 2.7k | Resistor | R12 | 1 | RESC0805(2012)_N | TE Connectivity | CRG0805F2K7 | Volume Production | Digi-Key | A126359CT-ND | 0.08857 | 0.08857
 | 8MHz | Ceramic SMD Crystal, 12 MHz, +/- 20 ppm, 70 Ohm, -20 to 70 degC, 4-Pin SMD, RoHS, Tape and Reel | Y3 | 1 | ABRA-ABM3B-4_V | Abracon | ABM3B-8.000MHZ-B2-T | Volume Production | Digi-Key | 535-9720-1-ND | 0.96537 | 0.96537
 | 10p | Capacitor | C11, C12 | 2 | CAPC0805(2012)75_M | KEMET | C0805C100J5GACTU | Volume Production | Digi-Key | 399-1108-1-ND | 0.09742 | 0.19485
 | 10u | Polarized Capacitor | C8, C15 | 2 | 1206_Tantal, 1411_Cap_Pol | KEMET | T491A106M020AT | Volume Production | Digi-Key | 399-5152-6-ND | 0.61997 | 1.24
 | 12k 1% | Resistor | R13, R16 | 2 | RESC0805(2012)_N | TE Connectivity | CRG0805F12K | Volume Production | Digi-Key | A126337DKR-ND | 0.08857 | 0.17713
 | 14 Pins | samtec SSQ-114-03-G-S | X3, X4 | 2 | SSQ-114-03-G-S | Samtec | SSQ-114-03-G-S | End of Life | Mouser | 200-SSQ11403GS | 2.48 | 4.96
 | 18p | CAP 18pF 25V ±20% 0805 (2012 Metric) Thickness 0.75mm SMD | C2, C3, C20, C21 | 4 | CAPC0805(2012)75_M | Murata | GRM21A5C2D180JW01D | Volume Production | RSComponents | 8851711 | 0.157 | 7.85
 | 24k | Resistor | R10, R11 | 2 | RESC0805(2012)_N | TE Connectivity | CRG0805F22K | Volume Production | Digi-Key | A106059DKR-ND | 0.08857 | 0.17713
 | 32,768kHz | ABRACON ABS07-32.768KHZ-T CRYSTAL, 32.768KHZ, 12.5PF, SMD | Y2 | 1 | ABS07-32.768KHZ-T | Abracon | ABS07-32.768KHZ-9-T | Volume Production | Digi-Key | 535-9544-1-ND | 0.96537 | 0.96537
 | 33R | Resistor | R6, R7 | 2 | RESC0805(2012)_N | TE Connectivity | CRG0805F33R | Volume Production | Digi-Key | A126363DKR-ND | 0.08857 | 0.17713
 | 100k | Resistor | R21 | 1 | RESC0805(2012)_N | TE Connectivity | CRG0805F100K | Volume Production | Digi-Key | A106052CT-ND | 0.07844 | 0.07844
 | 100k 1% | Resistor | R14, R17, R18 | 3 | RESC0805(2012)_N | TE Connectivity | CRG0805F100K | Volume Production | Digi-Key | A106052CT-ND | 0.07844 | 0.23532
 | 100n | Capacitor | C9, C10, C14, C16, C17, C18, C19 | 7 | CAPC0805(2012)75_M | Kyocera AVX | 08055C104KAT2A | Volume Production | Digi-Key | 478-1395-1-ND | 0.09742 | 0.68196
 | 330R 1% | Resistor | R15 | 1 | RESC0805(2012)_N | TE Connectivity | CRG0805F330R | Volume Production | Digi-Key | A106061DKR-ND | 0.08857 | 0.08857
 | 61300621121 | WR-PHD 2.54 mm THT Dual Pin Header, 6p | X2 | 1 | 61300621121 | Wurth Electronics | 61300621121 | Volume Production | Digi-Key | 732-5295-ND | 0.47826 | 0.47826
 | 61301221121 | WR-PHD 2.54 mm THT Dual Pin Header, 12p | X10 | 1 | 61301221121 | Wurth Electronics | 61301221121 | Volume Production | Digi-Key | 732-5297-ND | 0.69082 | 0.69082
 | 434153017835 | 3.5x2.9mm SMD J-Bend WS-TASV, height 1.7 mm, 350 gf | S1 | 1 | 434153017835 | Wurth Electronics | 434153017835 | New Product | Digi-Key | 732-10143-6-ND | 0.49597 | 0.49597
 | 613012243121 | WR-PHD 2.54 mm Angled Dual Socket Header, 12p | X6 | 1 | 613012243121 | Wurth Electronics | 613012243121 | Unknown | Distrelec | 30024901 | 1.03 | 3.09
 | AO7800 |  | V7 | 1 | SOT363_ | Alpha & Omega Semiconductor | AO7800 | Volume Production | TME | AO7800 | 0.23683 | 0.71048
 | DAPLink Module |  | D1 | 1 | DAPLink Module | HTL Hollabrunn | DAPLink Module Rev02 | Manual Solution | HTL Hollabrunn | DAPLink Module Rev02 | 6 | 6
 | ferrite bead | Inductor | L1 | 1 | RESC0805(2012)_N | Wurth Electronics | 742792031 | Volume Production | Digi-Key | 732-4638-6-ND | 0.19485 | 0.19485
 | GND Test Point | WR-PHD 2.54 mm THT Pin Header, 2p | X5 | 1 | 61300211121 | Wurth Electronics | 61300211121 | Volume Production | Digi-Key | 732-5315-ND | 0.11514 | 0.11514
 | Green LED | LED Green, size 0805 | V6 | 1 | LED_0805_GREEN | Kingbright | APT2012LZGCK | Volume Production | Digi-Key | 754-1939-1-ND | 0.49597 | 0.49597
 | Micro-USB | Micro USB 2.0 SMT Type B Horizontal 5 Contacts High Current WR-COM | X7 | 1 | 629105150521 | Wurth Electronics | 629105150521 | Volume Production | Digi-Key | 732-5960-6-ND | 1.83 | 1.83
 | STM32F303RE | STM32 ARM-based 32-bit MCU with 128 Kbytes Flash, 64-pin LQFP, Industrial Temperature | D2 | 1 | STM32F103RBT6_WIH | STMicroelectronics | STM32F303RET6 | Volume Production | Digi-Key | 497-15163-ND | 6.84 | 6.84
 | TLV1117LV33DCYR | Single Output LDO, 1 A, Fixed 3.3 V Output, 2 to 5.5 V Input, 4-pin SOT-223 (DCY), -40 to 125 degC, Green (RoHS & no Sb/Br) | U1 | 1 | DCY0004A_N | Texas Instruments | TLV1117LV33DCYR | Volume Production | Digi-Key | 296-28778-1-ND | 0.41626 | 0.41626
 | TT8J11 |  | V5, V8 | 2 | SOTFL65P190X85-8N | Rohm | TT8J11TCR | Volume Production | Digi-Key | TT8J11TCRDKR-ND | 0.36312 | 0.72625

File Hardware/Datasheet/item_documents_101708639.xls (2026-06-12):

Document Id | Document Version | Document Project Id | Title | Status | Creation date | Author | Document type | Document type Id | Doc. attributes | External reference | Modification date | File names
3234434 | 1 |  | HPM7177 ADC Mezzanine Schematics | Released | 2025-02-13 |  | Schematics | 300 |  |  | 2025-02-20, 15:29 | EDA-04061-V4-2_project.zip; EDA-04061-V4-2_sch.pdf
3234336 | 1 |  | HPM7177 ADC Mezzanine Specification | Released | 2025-02-12 |  | Engineering Specification | 32 |  |  | 2025-02-20, 15:29
3234437 | 1 |  | HPM7177 ADC Mezzanine PCB-Layout | Released | 2025-02-13 |  | PCB-Layout | 301 |  |  | 2025-02-20, 15:29 | EDA-04061-V4-2_pcb.pcbdoc; EDA-04061-V4-2_pcb.pdf
2663362 | 1 |  | HPM7177 ADC Mezzanine Board Manufacturing Data | Released | 2021-11-16 |  | Fabrication General | 49 |  |  | 2021-11-18, 13:46 | EDA-04061-V4_mfg.zip; EDA-04061-V4_mfg.pdf; EDA-04061-V4_specif.pdf
3234337 | 1 |  | HPM7177 ADC Mezzanine Assembly Data | Released | 2025-02-12 |  | Fabrication General | 49 |  |  | 2025-02-20, 15:29 | EDA-04061-V4-2_pcb-mat.xls; EDA-04061-V4-2_pcb-mat.pdf; EDA-04061-V4-2_SMD-top.pdf; EDA-04061-V4-2_SMD-bot.pdf; [has 4 file(s) more...]
3234338 | 1 |  | HPM7177 ADC Mezzanine Mechanical Parts | Released | 2025-02-12 |  | Fabrication General | 49 |  |  | 2025-02-20, 15:30
3234339 | 1 |  | HPM7177 ADC Mezzanine Picture | Released | 2025-02-12 |  | Illustration | 38 |  |  | 2025-02-20, 15:30 | EDA-04061-V4-2_3D.pdf; EDA-04061-V4-2_3D-top.jpg; EDA-04061-V4-2_3D-bot.jpg
3234340 | 1 |  | HPM7177 ADC Mezzanine Supplier Info | Released | 2025-02-12 |  | Management Cost | 70 |  |  | 2025-02-20, 15:30

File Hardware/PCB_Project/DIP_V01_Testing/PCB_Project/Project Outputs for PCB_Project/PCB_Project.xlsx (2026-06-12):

Comment | Description | Designator | Footprint | LibRef | Quantity
22pF | Capacitor | C1, C56 | C1206-KUE | Capacitor | 2
100nF | Capacitor | C2, C3, C4, C5, C11, C13, C14, C16, C17, C18, C34, C37, C39, C41, C43, C48, C50, C54, C55 | C1206-KUE | Capacitor | 19
10uF | Capacitor | C6, C8, C10, C12, C15, C27, C35, C45, C46, C47, C49, C51, C52 | C1206-KUE | Capacitor | 13
4.7uF | Capacitor | C7, C9, C28, C36 | C1206-KUE | Capacitor | 4
1uF | Capacitor | C25, C26, C38, C40, C42, C44, C53 | C1206-KUE | Capacitor | 7
 | Capacitor | C29 | C1206-KUE | Capacitor | 1
GREEN | Typical INFRARED GaAs LED | D1, D2 | 6-0805_N-KUE | LED0 | 2
RED | Typical INFRARED GaAs LED | D3 | 6-0805_N-KUE | LED0 | 1
1N4148W-7 | Description | D5, D6, D7, D8 | SOD123_DIO | 1N4148W-7 | 4
G6SK-2F-TR DC3 | Description | K1, K2 | RELAY_G6SK-2F DC3_OMR | G6SK-2F-TR DC3 | 2
LMC6001AIN/NOPB | Ultra-Low Input Current Amplifier 8-PDIP -40 to 85 | N1 | DIP8 | LMC6001AINNOPB | 1
ADS8681IPW | 16-bit, 1MSPS 1-ch SAR ADC with programmable (Â±12V, Â±10V, Â±6V, Â±5V, Â±2.5V) input ranges on 5V supply 16-TSSOP -40 to 125 | N3 | PW16_TEX | ADS8681IPW | 1
STM32F103 |  | N4 | DIP28 | STM32F103 | 1
BNC | BNC Elbow Connector | P1, P2, P3, P9 | BNC_RA CON | BNC | 4
Header 4 | Header, 4-Pin | P4 | HDR1X4 | Header 4 | 1
Header 2 | Header, 2-Pin | P5, P10, P11, P12 | HDR1X2 | Header 2 | 4
2N7002DW | Description | Q1, Q2 | SC-88SC70-6SOT-363_419B-02_ONS_OSI | 2N7002DW | 2
CNS020-10MP | CNS 020 10K 0,02% e2 | R1 | RES_CNS020_VIS | CNS020-10KP | 1
10k | Resistor SMD | R2, R9, R14, R15, R34, R36, R37, R38, R45, R46 | C1206-KUE | ResistorSMD | 10
33k | Resistor SMD | R3 | C1206-KUE | ResistorSMD | 1
10 | Resistor SMD | R4 | C1206-KUE | ResistorSMD | 1
78.7k | Resistor SMD | R5, R8 | C1206-KUE | ResistorSMD | 2
0 | Resistor SMD | R6, R7, R19, R20, R41 | C1206-KUE | ResistorSMD | 5
1k | Resistor SMD | R10, R33, R35, R43, R44, R47 | C1206-KUE | ResistorSMD | 6
4.7k | Resistor SMD | R11, R12, R13, R39 | C1206-KUE | ResistorSMD | 4
3.9k | Resistor SMD | R16, R17 | C1206-KUE | ResistorSMD | 2
2.7k | Resistor SMD | R18 | C1206-KUE | ResistorSMD | 1
49.9k | Resistor SMD | R40 | C1206-KUE | ResistorSMD | 1
Y0062100K000T9L | No Description Available | R42 | RES_S102K_7P62X2P67_VIS | Y0062100K000T9L | 1
LT3042EMSE#TRPBF | 20V, 200mA, Ultralow Noise, Ultrahigh PSRR RF Linear Regulator | U1, U10 | 05-08-1664_ADI | LT3042EMSETRPBF | 2
LT3094EMSE#TRPBF | âˆ’20V, 500mA, Ultralow Noise, Ultrahigh PSRR Negative Linear Regulator | U2 | MSE_05-08-1666_ADI | LT3094EMSETRPBF | 1
AD5689RBRUZ | Dual, 16-Bit nanoDAC+ with 2 ppm/Â°C Reference, SPI Interface | U3 | RU_16_ADI | AD5689RBRUZ | 1
OPA197IDBVR | Single, 36-V, precision, rail-to-rail input output, low offset voltage op amp 5-SOT-23 -40 to 125 | U7, U8, U15 | DBV5_TEX | OPA197IDBVR | 3
DS18B20+ | Programmable Resolution 1-Wire Digital Thermometer | U9 | 21-0248A_Q3-1_MXM | DS18B20+ | 1
TLV76733DGNR | Adjustable- and fixed-output, 1-A, 16-V, positive-voltage low-dropout (LDO) linear regulator 8-HVSSOP -40 to 125 | U12 | VSSOP8_DGN_TEX | TLV76733DGNR | 1
DS28E07+T | 1024-Bit, 1-Wire EEPROM | U16 | 21-0250_Q3+4_MXM | DS28E07+T | 1

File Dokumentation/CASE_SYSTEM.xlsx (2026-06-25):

HTL-Hollabrunn | Projektname: |  |  | Firma: |  |  |  |  | Datum:
Materialbestellung | ADFET |  |  | Reichelt |  |  |  |  | 2026-06-24
Antragsteller: Watzek Michael | Klasse: 5AHEL |  | Projektnummer: 10313
Bauteilinformation Name |  |  |  |  |  | Preis/Stück |  | Preis/VPE |  | Gesamt
 |  | Bestellnr. | benötigte Stückzahl | Stück/ VPE | Anzahl VPE | exkl. MWSt | inkl. MWSt | exkl. MWSt | inkl. MWSt | inkl. MWSt
Systemgehäuse Artikel-Nr.: GEH SG 1-10 |  |  | 1 | 1 | 1 | 60.720 | 75.900 | 60.720 | 75.900 | 75.900 | https://www.reichelt.de/de/de/shop/produkt/systemgehaeuse-50437
Einschubkassetten 10TE(50,5mm) |  |  | 1 | 1 | 1 | 28.360 | 35.450 | 28.360 | 35.450 | 35.450 | https://www.reichelt.de/de/de/shop/produkt/einschubkassetten_10te_50_5mm_-50417
 |  |  |  |  |  | 0.000 |  | 0.000 | 0.000
 |  |  |  |  |  | 0.000 |  | 0.000 | 0.000
 |  |  |  |  |  | 0.000 |  | 0.000 | 0.000
 |  |  |  |  |  | 0.000 |  | 0.000 | 0.000
 |  |  |  |  |  | 0.000 |  | 0.000 | 0.000
 |  |  |  |  |  | 0.000 |  | 0.000 | 0.000
 |  |  |  |  |  | 0.000 |  | 0.000 | 0.000
 |  |  |  |  |  | 0.000 |  | 0.000 | 0.000
 |  |  |  |  |  | 0.000 |  | 0.000 | 0.000
 |  |  |  |  |  | 0.000 |  | 0.000 | 0.000
 |  |  |  |  |  | 0.000 |  | 0.000 | 0.000
 |  |  |  |  |  | 0.000 |  | 0.000 | 0.000
Schüler: …........................................................ |  | Projektleiter: …........................................................ |  |  |  | Lehrerkürzel: |  | Summe: |  | €111.35
 |  |  |  |  |  |  |  | inkl. MWSt
Unterschrift |  | Unterschrift

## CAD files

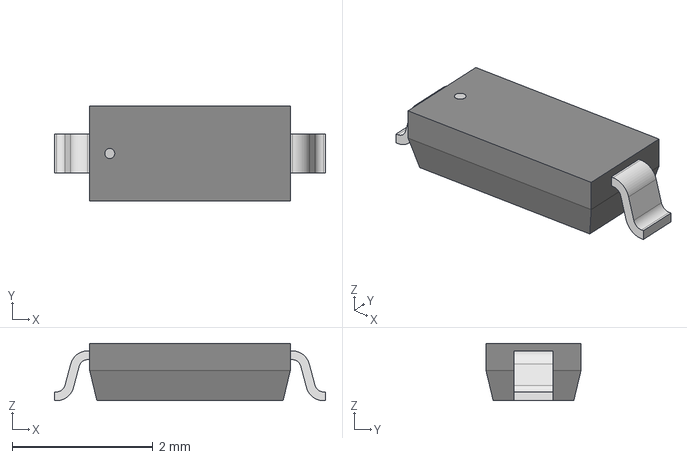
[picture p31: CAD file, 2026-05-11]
Hardware/Altium_libs/ul_1N4148W-7/Altium/1N4148W-7/SOD123_DIO.step
3.85 x 1.35 x 0.815 mm

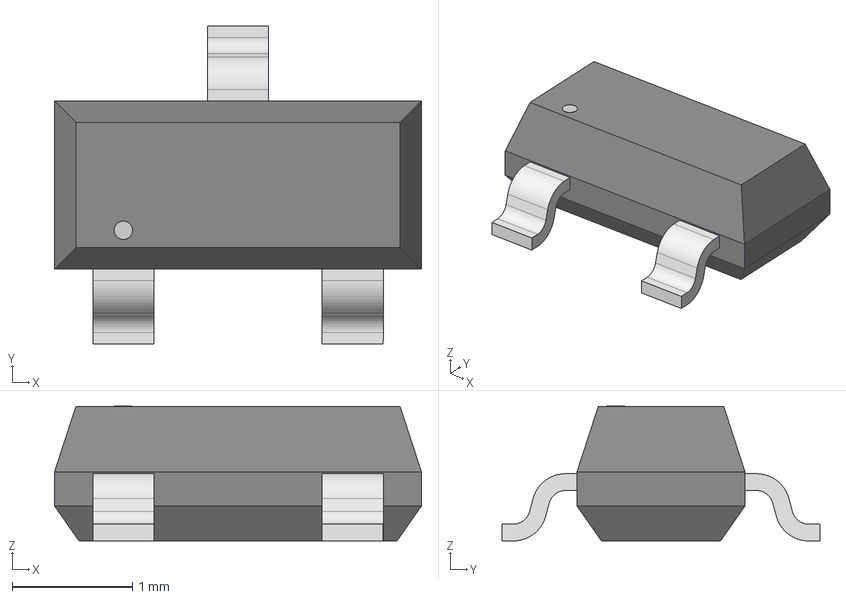
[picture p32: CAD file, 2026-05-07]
Hardware/Altium_libs/ul_2N7002/Altium/2N7002/SOT-23TO-236_318-08_ONS.step
3.05 x 2.64 x 1.12 mm

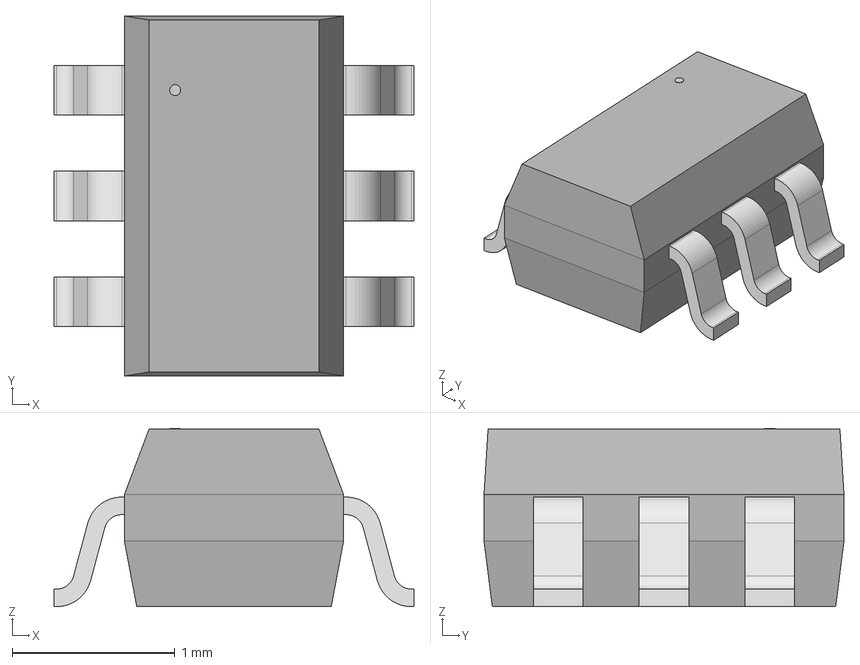
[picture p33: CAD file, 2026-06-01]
Hardware/Altium_libs/ul_2N7002DW/Altium/2N7002DW/SC-88SC70-6SOT-363_419B-02_ONS_OSI.step
2.21 x 2.21 x 1.09 mm

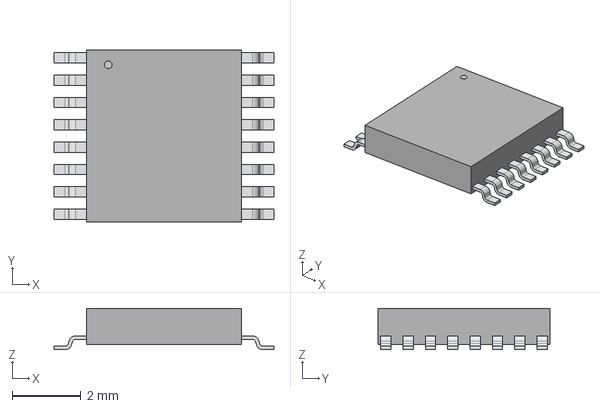
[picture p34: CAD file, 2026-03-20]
Hardware/Altium_libs/ul_AD5689RBRUZ/Altium/AD5689RBRUZ/RU_16_ADI.step
6.40 x 5.00 x 1.20 mm

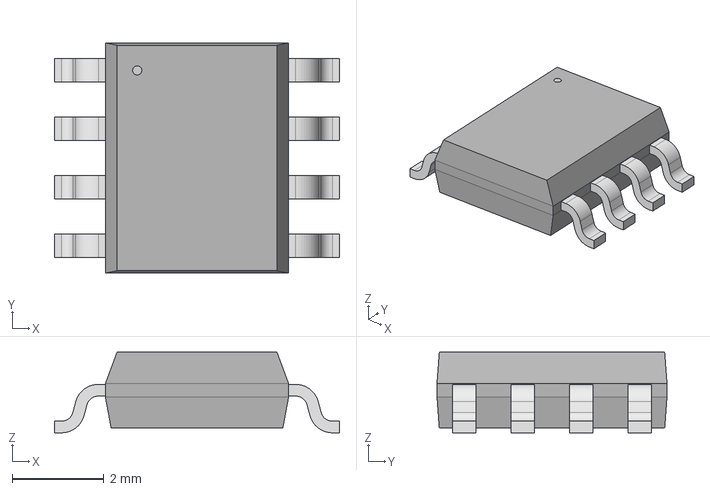
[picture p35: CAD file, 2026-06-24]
Hardware/Altium_libs/ul_ADR4540BRZ/Altium/ADR4540BRZ/R-8_ADI.step
6.20 x 5.00 x 1.75 mm

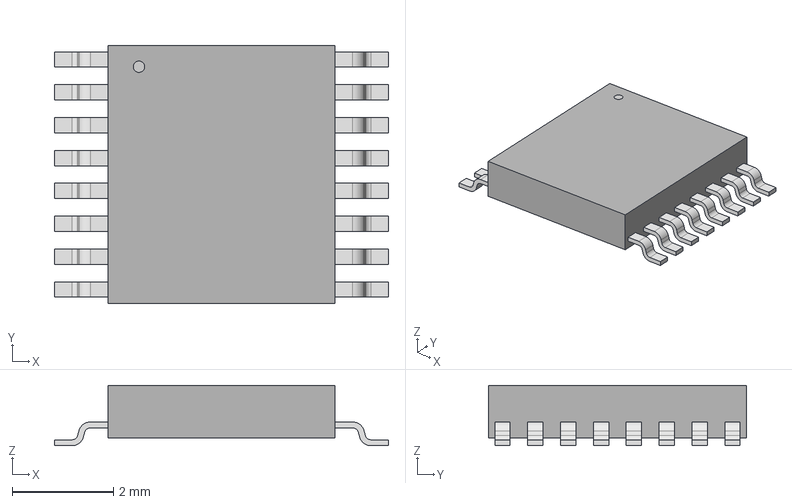
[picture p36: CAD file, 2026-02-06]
Hardware/Altium_libs/ul_ADS8681IPW/Altium/ADS8681IPW/PW16_TEX.step
6.60 x 5.11 x 1.20 mm

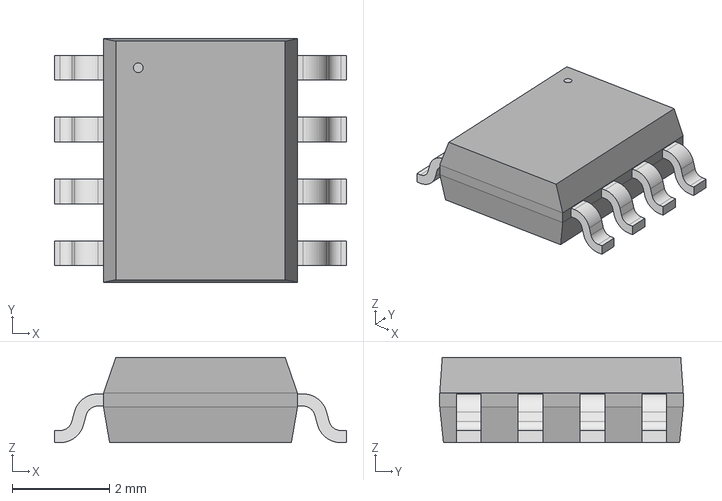
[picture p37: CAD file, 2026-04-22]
Hardware/Altium_libs/ul_APS6404L-3SQR-SN/Altium/APS6404L-3SQR-SN/APS6404L-3SQR-SN_APY.step
6.00 x 5.00 x 1.75 mm

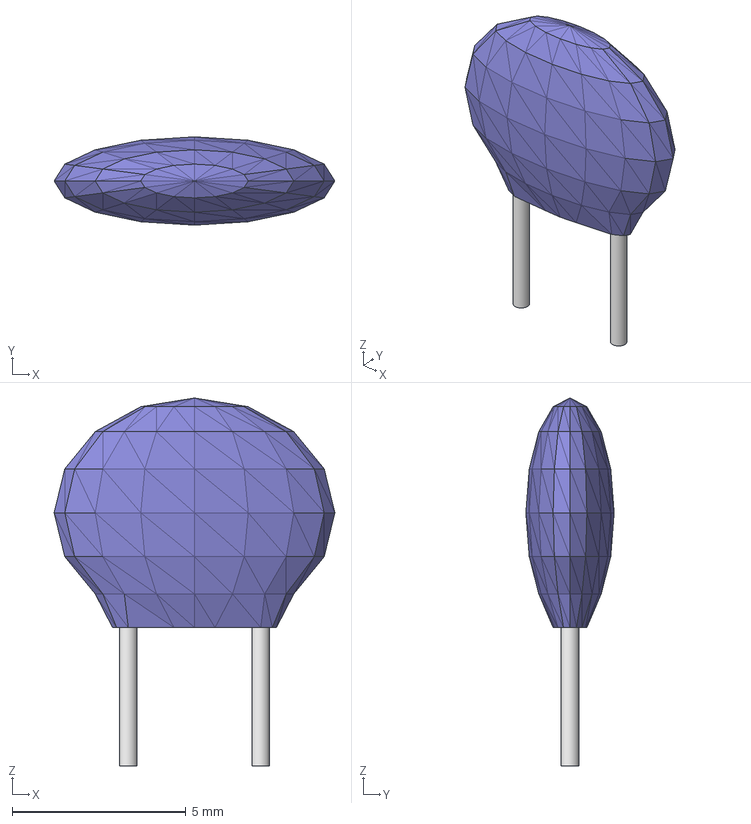
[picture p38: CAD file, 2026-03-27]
Hardware/Altium_libs/ul_CNS020-10KP/Altium/RES_CNS020_VIS.step
8.08 x 2.54 x 10.6 mm

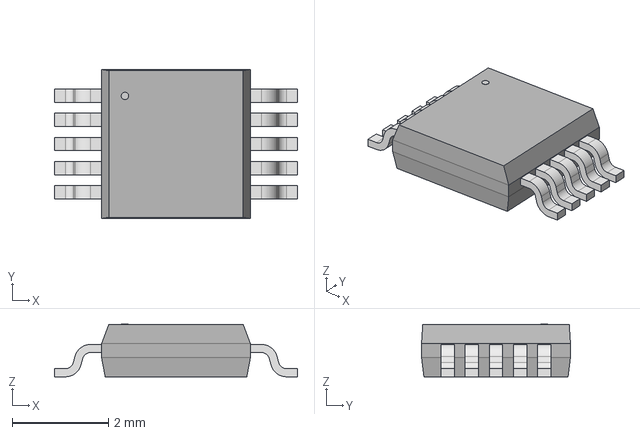
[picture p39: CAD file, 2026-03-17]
Hardware/Altium_libs/ul_DAC8562SDGST/Altium/DAC8562SDGST/DGS10.step
5.05 x 3.10 x 1.09 mm

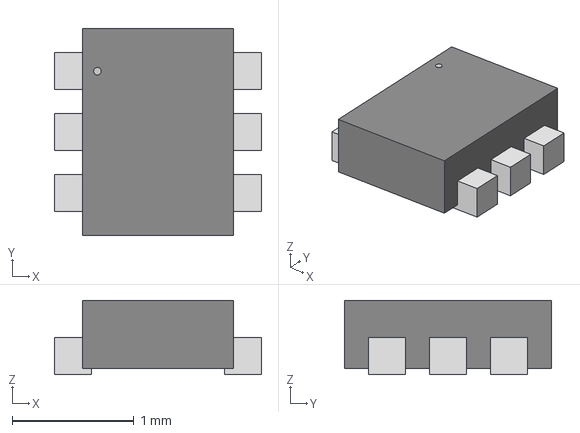
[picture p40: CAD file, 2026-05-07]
Hardware/Altium_libs/ul_DMC2400UV-7/Altium/DMC2400UV-7/SON_400UV-7_DIO.step
1.70 x 1.70 x 0.612 mm

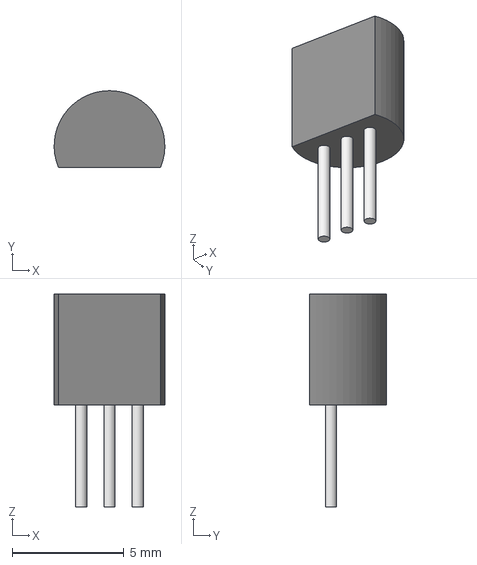
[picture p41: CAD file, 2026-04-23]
Hardware/Altium_libs/ul_DS18B20-/Altium/DS18B20-/21-0248A_Q3-1_MXM.step
4.95 x 3.43 x 9.53 mm

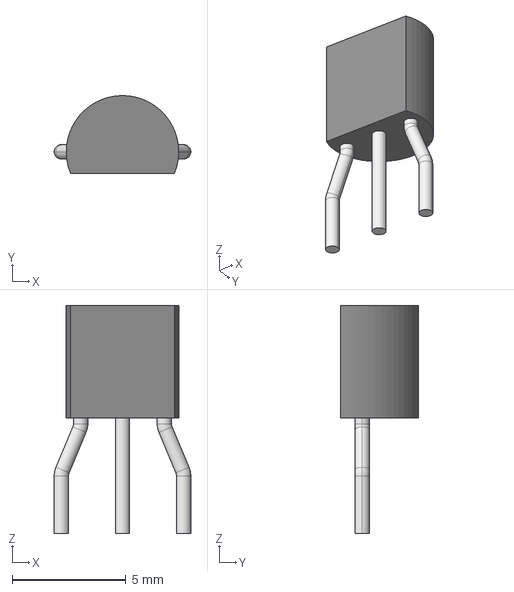
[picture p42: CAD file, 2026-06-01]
Hardware/Altium_libs/ul_DS28E07-T/Altium/21-0250_Q3+4_MXM.step
6.01 x 3.43 x 10.0 mm

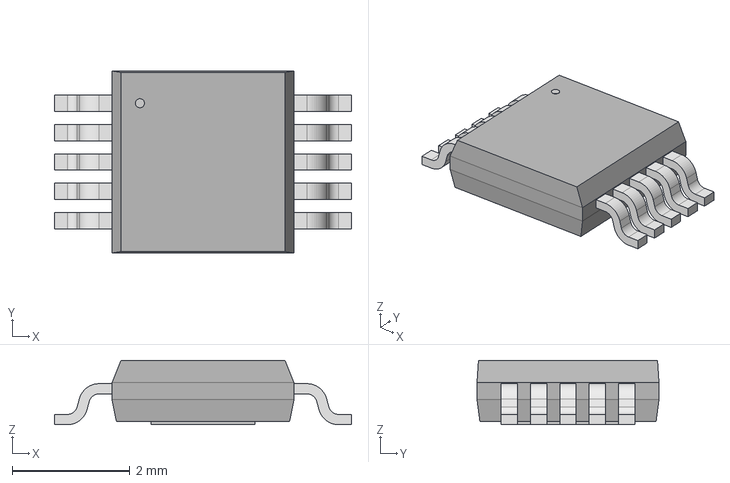
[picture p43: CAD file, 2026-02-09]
Hardware/Altium_libs/ul_LT3042EMSE-TRPBF/Altium/LT3042EMSE-TRPBF/05-08-1664_ADI.step
5.05 x 3.10 x 1.09 mm

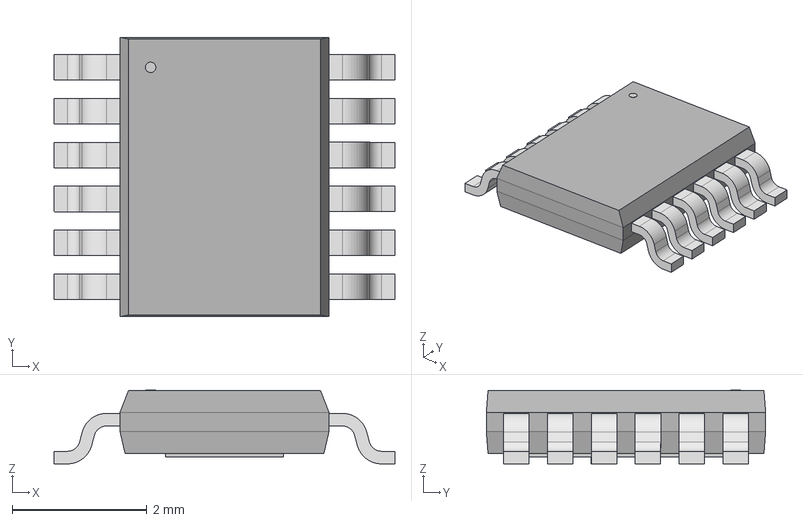
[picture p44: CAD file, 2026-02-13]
Hardware/Altium_libs/ul_LT3094EMSE-TRPBF/Altium/LT3094EMSE-TRPBF/MSE_05-08-1666_ADI.step
5.05 x 4.14 x 1.09 mm

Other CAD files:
Hardware/Altium_libs/ul_DS28E05R-U/Altium/21-0051H_MXM.step
Hardware/Altium_libs/ul_OPA197IDBVR/Altium/OPA197IDBVR/DBV5_TEX.step
Hardware/Altium_libs/ul_POPA928DR (1)/Altium/POPA928DR/SOIC8_D_TEX.step
Hardware/Altium_libs/ul_SN65LVDS2DBVR/Altium/SN65LVDS2DBVR/DBV5.step
Hardware/Altium_libs/ul_TLV76733DGNR/Altium/TLV76733DGNR/VSSOP8_DGN_TEX.step
Hardware/Altium_libs/ul_Y0062100K000T9L/Altium/RES_S102K_7P62X2P67_VIS.step

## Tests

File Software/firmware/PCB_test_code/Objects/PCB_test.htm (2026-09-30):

# Static Call Graph for image .\Objects\PCB_test.axf

#<CALLGRAPH># ARM Linker, 6190004: Last Updated: Wed Sep 30 15:44:04 2026

### Maximum Stack Usage = 324 bytes + Unknown(Functions without stacksize, Cycles, Untraceable Function Pointers)

### Call chain for Maximum Stack Depth:

_printf_f ⇒ _printf_fp_dec ⇒ _printf_fp_dec_real ⇒ _fp_digits ⇒ _btod_etento ⇒ _btod_emul ⇒ _e2e

### Functions with no stack information

- __user_initial_stackheap

### Mutually Recursive functions

- NMI_Handler ⇒ NMI_Handler
- HardFault_Handler ⇒ HardFault_Handler
- MemManage_Handler ⇒ MemManage_Handler
- BusFault_Handler ⇒ BusFault_Handler
- UsageFault_Handler ⇒ UsageFault_Handler
- SVC_Handler ⇒ SVC_Handler
- DebugMon_Handler ⇒ DebugMon_Handler
- PendSV_Handler ⇒ PendSV_Handler
- SysTick_Handler ⇒ SysTick_Handler
- ADC1_2_IRQHandler ⇒ ADC1_2_IRQHandler

### Function Pointers

- ADC1_2_IRQHandler from startup_stm32f10x_md.o(.text) referenced from startup_stm32f10x_md.o(RESET)
- BusFault_Handler from startup_stm32f10x_md.o(.text) referenced from startup_stm32f10x_md.o(RESET)
- CAN1_RX1_IRQHandler from startup_stm32f10x_md.o(.text) referenced from startup_stm32f10x_md.o(RESET)
- CAN1_SCE_IRQHandler from startup_stm32f10x_md.o(.text) referenced from startup_stm32f10x_md.o(RESET)
- DMA1_Channel1_IRQHandler from startup_stm32f10x_md.o(.text) referenced from startup_stm32f10x_md.o(RESET)
- DMA1_Channel2_IRQHandler from startup_stm32f10x_md.o(.text) referenced from startup_stm32f10x_md.o(RESET)
- DMA1_Channel3_IRQHandler from startup_stm32f10x_md.o(.text) referenced from startup_stm32f10x_md.o(RESET)
- DMA1_Channel4_IRQHandler from startup_stm32f10x_md.o(.text) referenced from startup_stm32f10x_md.o(RESET)
- DMA1_Channel5_IRQHandler from startup_stm32f10x_md.o(.text) referenced from startup_stm32f10x_md.o(RESET)
- DMA1_Channel6_IRQHandler from startup_stm32f10x_md.o(.text) referenced from startup_stm32f10x_md.o(RESET)
- DMA1_Channel7_IRQHandler from startup_stm32f10x_md.o(.text) referenced from startup_stm32f10x_md.o(RESET)
- DebugMon_Handler from startup_stm32f10x_md.o(.text) referenced from startup_stm32f10x_md.o(RESET)
- EXTI0_IRQHandler from startup_stm32f10x_md.o(.text) referenced from startup_stm32f10x_md.o(RESET)
- EXTI15_10_IRQHandler from startup_stm32f10x_md.o(.text) referenced from startup_stm32f10x_md.o(RESET)
- EXTI1_IRQHandler from startup_stm32f10x_md.o(.text) referenced from startup_stm32f10x_md.o(RESET)
- EXTI2_IRQHandler from startup_stm32f10x_md.o(.text) referenced from startup_stm32f10x_md.o(RESET)
- EXTI3_IRQHandler from startup_stm32f10x_md.o(.text) referenced from startup_stm32f10x_md.o(RESET)
- EXTI4_IRQHandler from startup_stm32f10x_md.o(.text) referenced from startup_stm32f10x_md.o(RESET)
- EXTI9_5_IRQHandler from startup_stm32f10x_md.o(.text) referenced from startup_stm32f10x_md.o(RESET)
- FLASH_IRQHandler from startup_stm32f10x_md.o(.text) referenced from startup_stm32f10x_md.o(RESET)
- HardFault_Handler from startup_stm32f10x_md.o(.text) referenced from startup_stm32f10x_md.o(RESET)
- I2C1_ER_IRQHandler from startup_stm32f10x_md.o(.text) referenced from startup_stm32f10x_md.o(RESET)
- I2C1_EV_IRQHandler from startup_stm32f10x_md.o(.text) referenced from startup_stm32f10x_md.o(RESET)
- I2C2_ER_IRQHandler from startup_stm32f10x_md.o(.text) referenced from startup_stm32f10x_md.o(RESET)
- I2C2_EV_IRQHandler from startup_stm32f10x_md.o(.text) referenced from startup_stm32f10x_md.o(RESET)
- MemManage_Handler from startup_stm32f10x_md.o(.text) referenced from startup_stm32f10x_md.o(RESET)
- NMI_Handler from startup_stm32f10x_md.o(.text) referenced from startup_stm32f10x_md.o(RESET)
- PVD_IRQHandler from startup_stm32f10x_md.o(.text) referenced from startup_stm32f10x_md.o(RESET)
- PendSV_Handler from startup_stm32f10x_md.o(.text) referenced from startup_stm32f10x_md.o(RESET)
- RCC_IRQHandler from startup_stm32f10x_md.o(.text) referenced from startup_stm32f10x_md.o(RESET)
- RTCAlarm_IRQHandler from startup_stm32f10x_md.o(.text) referenced from startup_stm32f10x_md.o(RESET)
- RTC_IRQHandler from startup_stm32f10x_md.o(.text) referenced from startup_stm32f10x_md.o(RESET)
- Reset_Handler from startup_stm32f10x_md.o(.text) referenced from startup_stm32f10x_md.o(RESET)
- SPI1_IRQHandler from startup_stm32f10x_md.o(.text) referenced from startup_stm32f10x_md.o(RESET)
- SPI2_IRQHandler from startup_stm32f10x_md.o(.text) referenced from startup_stm32f10x_md.o(RESET)
- SVC_Handler from startup_stm32f10x_md.o(.text) referenced from startup_stm32f10x_md.o(RESET)
- SysTick_Handler from startup_stm32f10x_md.o(.text) referenced from startup_stm32f10x_md.o(RESET)
- SystemInit from system_stm32f10x.o(.text.SystemInit) referenced from startup_stm32f10x_md.o(.text)
- TAMPER_IRQHandler from startup_stm32f10x_md.o(.text) referenced from startup_stm32f10x_md.o(RESET)
- TIM1_BRK_IRQHandler from startup_stm32f10x_md.o(.text) referenced from startup_stm32f10x_md.o(RESET)
- TIM1_CC_IRQHandler from startup_stm32f10x_md.o(.text) referenced from startup_stm32f10x_md.o(RESET)
- TIM1_TRG_COM_IRQHandler from startup_stm32f10x_md.o(.text) referenced from startup_stm32f10x_md.o(RESET)
- TIM1_UP_IRQHandler from startup_stm32f10x_md.o(.text) referenced from startup_stm32f10x_md.o(RESET)
- TIM2_IRQHandler from timer.o(.text.TIM2_IRQHandler) referenced from startup_stm32f10x_md.o(RESET)
- TIM3_IRQHandler from startup_stm32f10x_md.o(.text) referenced from startup_stm32f10x_md.o(RESET)
- TIM4_IRQHandler from startup_stm32f10x_md.o(.text) referenced from startup_stm32f10x_md.o(RESET)
- USART1_IRQHandler from uart.o(.text.USART1_IRQHandler) referenced from startup_stm32f10x_md.o(RESET)
- USART2_IRQHandler from startup_stm32f10x_md.o(.text) referenced from startup_stm32f10x_md.o(RESET)
- USART3_IRQHandler from startup_stm32f10x_md.o(.text) referenced from startup_stm32f10x_md.o(RESET)
- USBWakeUp_IRQHandler from startup_stm32f10x_md.o(.text) referenced from startup_stm32f10x_md.o(RESET)
- USB_HP_CAN1_TX_IRQHandler from startup_stm32f10x_md.o(.text) referenced from startup_stm32f10x_md.o(RESET)
- USB_LP_CAN1_RX0_IRQHandler from startup_stm32f10x_md.o(.text) referenced from startup_stm32f10x_md.o(RESET)
- UsageFault_Handler from startup_stm32f10x_md.o(.text) referenced from startup_stm32f10x_md.o(RESET)
- WWDG_IRQHandler from startup_stm32f10x_md.o(.text) referenced from startup_stm32f10x_md.o(RESET)
- __main from __main.o(!!!main) referenced from startup_stm32f10x_md.o(.text)
- _get_lc_ctype from lc_ctype_c.o(locale$$code) referenced from rt_ctype_table.o(.text)
- _printf_input_char from _printf_char_common.o(.text) referenced from _printf_char_common.o(.text)
- _sputc from _sputc.o(.text) referenced from sprintf.o(.text)

### Global Symbols

__main (Thumb, 8 bytes, Stack size 0 bytes, __main.o(!!!main))

[Calls]

- >> __rt_entry
- >> __scatterload

[Address Reference Count : 1]

- startup_stm32f10x_md.o(.text)

__scatterload (Thumb, 0 bytes, Stack size unknown bytes, __scatter.o(!!!scatter))

[Called By]

- >> __main

__scatterload_rt2 (Thumb, 44 bytes, Stack size unknown bytes, __scatter.o(!!!scatter), UNUSED)

[Calls]

- >> __rt_entry

__scatterload_rt2_thumb_only (Thumb, 0 bytes, Stack size unknown bytes, __scatter.o(!!!scatter), UNUSED)

__scatterload_null (Thumb, 0 bytes, Stack size unknown bytes, __scatter.o(!!!scatter), UNUSED)

__scatterload_copy (Thumb, 26 bytes, Stack size unknown bytes, __scatter_copy.o(!!handler_copy), UNUSED)

[Calls]

- >> __scatterload_copy

[Called By]

- >> __scatterload_copy

__scatterload_zeroinit (Thumb, 28 bytes, Stack size unknown bytes, __scatter_zi.o(!!handler_zi), UNUSED)

_printf_n (Thumb, 0 bytes, Stack size unknown bytes, _printf_n.o(.ARM.Collect$$_printf_percent$$00000001))

[Calls]

- >> _printf_charcount

_printf_percent (Thumb, 0 bytes, Stack size unknown bytes, _printf_percent.o(.ARM.Collect$$_printf_percent$$00000000))

[Called By]

- >> __printf

_printf_p (Thumb, 0 bytes, Stack size unknown bytes, _printf_p.o(.ARM.Collect$$_printf_percent$$00000002))

[Stack]

- Max Depth = 64 + Unknown Stack Size
- Call Chain = _printf_p ⇒ _printf_hex_ptr ⇒ _printf_longlong_hex ⇒ _printf_int_common ⇒ _printf_post_padding

[Calls]

- >> _printf_hex_ptr

_printf_f (Thumb, 0 bytes, Stack size unknown bytes, _printf_f.o(.ARM.Collect$$_printf_percent$$00000003))

[Stack]

- Max Depth = 324 + Unknown Stack Size
- Call Chain = _printf_f ⇒ _printf_fp_dec ⇒ _printf_fp_dec_real ⇒ _fp_digits ⇒ _btod_etento ⇒ _btod_emul ⇒ _e2e

[Calls]

- >> _printf_fp_dec

_printf_e (Thumb, 0 bytes, Stack size unknown bytes, _printf_e.o(.ARM.Collect$$_printf_percent$$00000004))

[Stack]

- Max Depth = 324 + Unknown Stack Size
- Call Chain = _printf_e ⇒ _printf_fp_dec ⇒ _printf_fp_dec_real ⇒ _fp_digits ⇒ _btod_etento ⇒ _btod_emul ⇒ _e2e

[Calls]

- >> _printf_fp_dec

_printf_g (Thumb, 0 bytes, Stack size unknown bytes, _printf_g.o(.ARM.Collect$$_printf_percent$$00000005))

[Stack]

- Max Depth = 324 + Unknown Stack Size
- Call Chain = _printf_g ⇒ _printf_fp_dec ⇒ _printf_fp_dec_real ⇒ _fp_digits ⇒ _btod_etento ⇒ _btod_emul ⇒ _e2e

[Calls]

- >> _printf_fp_dec

_printf_a (Thumb, 0 bytes, Stack size unknown bytes, _printf_a.o(.ARM.Collect$$_printf_percent$$00000006))

[Stack]

- Max Depth = 112 + Unknown Stack Size
- Call Chain = _printf_a ⇒ _printf_fp_hex ⇒ _printf_fp_hex_real ⇒ _printf_fp_infnan ⇒ _printf_post_padding

[Calls]

- >> _printf_fp_hex

_printf_ll (Thumb, 0 bytes, Stack size unknown bytes, _printf_ll.o(.ARM.Collect$$_printf_percent$$00000007))

_printf_i (Thumb, 0 bytes, Stack size unknown bytes, _printf_i.o(.ARM.Collect$$_printf_percent$$00000008))

[Stack]

- Max Depth = 72 + Unknown Stack Size
- Call Chain = _printf_i ⇒ _printf_int_dec ⇒ _printf_int_common ⇒ _printf_post_padding

[Calls]

- >> _printf_int_dec

_printf_d (Thumb, 0 bytes, Stack size unknown bytes, _printf_d.o(.ARM.Collect$$_printf_percent$$00000009))

[Stack]

- Max Depth = 72 + Unknown Stack Size
- Call Chain = _printf_d ⇒ _printf_int_dec ⇒ _printf_int_common ⇒ _printf_post_padding

[Calls]

- >> _printf_int_dec

_printf_u (Thumb, 0 bytes, Stack size unknown bytes, _printf_u.o(.ARM.Collect$$_printf_percent$$0000000A))

[Stack]

- Max Depth = 72 + Unknown Stack Size
- Call Chain = _printf_u ⇒ _printf_int_dec ⇒ _printf_int_common ⇒ _printf_post_padding

[Calls]

- >> _printf_int_dec

_printf_o (Thumb, 0 bytes, Stack size unknown bytes, _printf_o.o(.ARM.Collect$$_printf_percent$$0000000B))

[Stack]

- Max Depth = 64 + Unknown Stack Size
- Call Chain = _printf_o ⇒ _printf_int_oct ⇒ _printf_longlong_oct ⇒ _printf_int_common ⇒ _printf_post_padding

[Calls]

- >> _printf_int_oct

_printf_x (Thumb, 0 bytes, Stack size unknown bytes, _printf_x.o(.ARM.Collect$$_printf_percent$$0000000C))

[Stack]

- Max Depth = 80 + Unknown Stack Size
- Call Chain = _printf_x ⇒ _printf_int_hex ⇒ _printf_longlong_hex ⇒ _printf_int_common ⇒ _printf_post_padding

[Calls]

- >> _printf_int_hex

_printf_lli (Thumb, 0 bytes, Stack size unknown bytes, _printf_lli.o(.ARM.Collect$$_printf_percent$$0000000D))

[Stack]

- Max Depth = 72 + Unknown Stack Size
- Call Chain = _printf_lli ⇒ _printf_longlong_dec ⇒ _printf_int_common ⇒ _printf_post_padding

[Calls]

- >> _printf_longlong_dec

_printf_lld (Thumb, 0 bytes, Stack size unknown bytes, _printf_lld.o(.ARM.Collect$$_printf_percent$$0000000E))

[Stack]

- Max Depth = 72 + Unknown Stack Size
- Call Chain = _printf_lld ⇒ _printf_longlong_dec ⇒ _printf_int_common ⇒ _printf_post_padding

[Calls]

- >> _printf_longlong_dec

_printf_llu (Thumb, 0 bytes, Stack size unknown bytes, _printf_llu.o(.ARM.Collect$$_printf_percent$$0000000F))

[Stack]

- Max Depth = 72 + Unknown Stack Size
- Call Chain = _printf_llu ⇒ _printf_longlong_dec ⇒ _printf_int_common ⇒ _printf_post_padding

[Calls]

- >> _printf_longlong_dec

_printf_llo (Thumb, 0 bytes, Stack size unknown bytes, _printf_llo.o(.ARM.Collect$$_printf_percent$$00000010))

[Stack]

- Max Depth = 56 + Unknown Stack Size
- Call Chain = _printf_llo ⇒ _printf_ll_oct ⇒ _printf_longlong_oct ⇒ _printf_int_common ⇒ _printf_post_padding

[Calls]

- >> _printf_ll_oct

_printf_llx (Thumb, 0 bytes, Stack size unknown bytes, _printf_llx.o(.ARM.Collect$$_printf_percent$$00000011))

[Stack]

- Max Depth = 64 + Unknown Stack Size
- Call Chain = _printf_llx ⇒ _printf_ll_hex ⇒ _printf_longlong_hex ⇒ _printf_int_common ⇒ _printf_post_padding

[Calls]

- >> _printf_ll_hex

_printf_l (Thumb, 0 bytes, Stack size unknown bytes, _printf_l.o(.ARM.Collect$$_printf_percent$$00000012))

_printf_c (Thumb, 0 bytes, Stack size unknown bytes, _printf_c.o(.ARM.Collect$$_printf_percent$$00000013))

[Stack]

- Max Depth = 40 + Unknown Stack Size
- Call Chain = _printf_c ⇒ _printf_char ⇒ _printf_cs_common ⇒ _printf_str ⇒ _printf_post_padding

[Calls]

- >> _printf_char

_printf_s (Thumb, 0 bytes, Stack size unknown bytes, _printf_s.o(.ARM.Collect$$_printf_percent$$00000014))

[Stack]

- Max Depth = 40 + Unknown Stack Size
- Call Chain = _printf_s ⇒ _printf_string ⇒ _printf_cs_common ⇒ _printf_str ⇒ _printf_post_padding

[Calls]

- >> _printf_string

_printf_lc (Thumb, 0 bytes, Stack size unknown bytes, _printf_lc.o(.ARM.Collect$$_printf_percent$$00000015))

[Stack]

- Max Depth = 88 + Unknown Stack Size
- Call Chain = _printf_lc ⇒ _printf_wchar ⇒ _printf_lcs_common ⇒ _printf_wctomb ⇒ _wcrtomb

[Calls]

- >> _printf_wchar

_printf_ls (Thumb, 0 bytes, Stack size unknown bytes, _printf_ls.o(.ARM.Collect$$_printf_percent$$00000016))

[Stack]

- Max Depth = 88 + Unknown Stack Size
- Call Chain = _printf_ls ⇒ _printf_wstring ⇒ _printf_lcs_common ⇒ _printf_wctomb ⇒ _wcrtomb

[Calls]

- >> _printf_wstring

_printf_percent_end (Thumb, 0 bytes, Stack size unknown bytes, _printf_percent_end.o(.ARM.Collect$$_printf_percent$$00000017))

__rt_lib_init (Thumb, 0 bytes, Stack size unknown bytes, libinit.o(.ARM.Collect$$libinit$$00000000))

[Called By]

- >> __rt_entry_li

__rt_lib_init_fp_1 (Thumb, 0 bytes, Stack size unknown bytes, libinit2.o(.ARM.Collect$$libinit$$00000002))

__rt_lib_init_heap_1 (Thumb, 0 bytes, Stack size unknown bytes, libinit2.o(.ARM.Collect$$libinit$$0000000C))

__rt_lib_init_lc_common (Thumb, 0 bytes, Stack size unknown bytes, libinit2.o(.ARM.Collect$$libinit$$00000011))

[Calls]

- >> __rt_locale

__rt_lib_init_preinit_1 (Thumb, 0 bytes, Stack size unknown bytes, libinit2.o(.ARM.Collect$$libinit$$00000006))

__rt_lib_init_rand_1 (Thumb, 0 bytes, Stack size unknown bytes, libinit2.o(.ARM.Collect$$libinit$$00000010))

__rt_lib_init_relocate_pie_1 (Thumb, 0 bytes, Stack size unknown bytes, libinit2.o(.ARM.Collect$$libinit$$00000004))

__rt_lib_init_user_alloc_1 (Thumb, 0 bytes, Stack size unknown bytes, libinit2.o(.ARM.Collect$$libinit$$0000000E))

__rt_lib_init_lc_collate_1 (Thumb, 0 bytes, Stack size unknown bytes, libinit2.o(.ARM.Collect$$libinit$$00000013))

__rt_lib_init_lc_ctype_2 (Thumb, 0 bytes, Stack size unknown bytes, libinit2.o(.ARM.Collect$$libinit$$00000014))

[Stack]

- Max Depth = 8 + Unknown Stack Size
- Call Chain = __rt_lib_init_lc_ctype_2 ⇒ _get_lc_ctype

[Calls]

- >> _get_lc_ctype

__rt_lib_init_lc_ctype_1 (Thumb, 0 bytes, Stack size unknown bytes, libinit2.o(.ARM.Collect$$libinit$$00000015))

__rt_lib_init_lc_monetary_1 (Thumb, 0 bytes, Stack size unknown bytes, libinit2.o(.ARM.Collect$$libinit$$00000017))

__rt_lib_init_lc_numeric_2 (Thumb, 0 bytes, Stack size unknown bytes, libinit2.o(.ARM.Collect$$libinit$$00000018))

[Stack]

- Max Depth = 8 + Unknown Stack Size
- Call Chain = __rt_lib_init_lc_numeric_2 ⇒ _get_lc_numeric

[Calls]

- >> _get_lc_numeric

__rt_lib_init_alloca_1 (Thumb, 0 bytes, Stack size unknown bytes, libinit2.o(.ARM.Collect$$libinit$$00000030))

__rt_lib_init_argv_1 (Thumb, 0 bytes, Stack size unknown bytes, libinit2.o(.ARM.Collect$$libinit$$0000002E))

__rt_lib_init_atexit_1 (Thumb, 0 bytes, Stack size unknown bytes, libinit2.o(.ARM.Collect$$libinit$$0000001D))

__rt_lib_init_clock_1 (Thumb, 0 bytes, Stack size unknown bytes, libinit2.o(.ARM.Collect$$libinit$$00000023))

__rt_lib_init_cpp_1 (Thumb, 0 bytes, Stack size unknown bytes, libinit2.o(.ARM.Collect$$libinit$$00000034))

__rt_lib_init_exceptions_1 (Thumb, 0 bytes, Stack size unknown bytes, libinit2.o(.ARM.Collect$$libinit$$00000032))

__rt_lib_init_fp_trap_1 (Thumb, 0 bytes, Stack size unknown bytes, libinit2.o(.ARM.Collect$$libinit$$00000021))

__rt_lib_init_getenv_1 (Thumb, 0 bytes, Stack size unknown bytes, libinit2.o(.ARM.Collect$$libinit$$00000025))

__rt_lib_init_lc_numeric_1 (Thumb, 0 bytes, Stack size unknown bytes, libinit2.o(.ARM.Collect$$libinit$$00000019))

__rt_lib_init_lc_time_1 (Thumb, 0 bytes, Stack size unknown bytes, libinit2.o(.ARM.Collect$$libinit$$0000001B))

__rt_lib_init_return (Thumb, 0 bytes, Stack size unknown bytes, libinit2.o(.ARM.Collect$$libinit$$00000035))

__rt_lib_init_signal_1 (Thumb, 0 bytes, Stack size unknown bytes, libinit2.o(.ARM.Collect$$libinit$$0000001F))

__rt_lib_init_stdio_1 (Thumb, 0 bytes, Stack size unknown bytes, libinit2.o(.ARM.Collect$$libinit$$00000027))

__rt_lib_shutdown (Thumb, 0 bytes, Stack size unknown bytes, libshutdown.o(.ARM.Collect$$libshutdown$$00000000))

[Called By]

- >> __rt_exit_ls

__rt_lib_shutdown_cpp_1 (Thumb, 0 bytes, Stack size unknown bytes, libshutdown2.o(.ARM.Collect$$libshutdown$$00000002))

__rt_lib_shutdown_fp_trap_1 (Thumb, 0 bytes, Stack size unknown bytes, libshutdown2.o(.ARM.Collect$$libshutdown$$00000007))

__rt_lib_shutdown_heap_1 (Thumb, 0 bytes, Stack size unknown bytes, libshutdown2.o(.ARM.Collect$$libshutdown$$0000000F))

__rt_lib_shutdown_return (Thumb, 0 bytes, Stack size unknown bytes, libshutdown2.o(.ARM.Collect$$libshutdown$$00000010))

__rt_lib_shutdown_signal_1 (Thumb, 0 bytes, Stack size unknown bytes, libshutdown2.o(.ARM.Collect$$libshutdown$$0000000A))

__rt_lib_shutdown_stdio_1 (Thumb, 0 bytes, Stack size unknown bytes, libshutdown2.o(.ARM.Collect$$libshutdown$$00000004))

__rt_lib_shutdown_user_alloc_1 (Thumb, 0 bytes, Stack size unknown bytes, libshutdown2.o(.ARM.Collect$$libshutdown$$0000000C))

__rt_entry (Thumb, 0 bytes, Stack size unknown bytes, __rtentry.o(.ARM.Collect$$rtentry$$00000000))

[Called By]

- >> __main
- >> __scatterload_rt2

__rt_entry_presh_1 (Thumb, 0 bytes, Stack size unknown bytes, __rtentry2.o(.ARM.Collect$$rtentry$$00000002))

__rt_entry_sh (Thumb, 0 bytes, Stack size unknown bytes, __rtentry4.o(.ARM.Collect$$rtentry$$00000004))

[Stack]

- Max Depth = 8 + Unknown Stack Size
- Call Chain = __rt_entry_sh ⇒ __user_setup_stackheap

[Calls]

- >> __user_setup_stackheap

__rt_entry_li (Thumb, 0 bytes, Stack size unknown bytes, __rtentry2.o(.ARM.Collect$$rtentry$$0000000A))

[Calls]

- >> __rt_lib_init

__rt_entry_postsh_1 (Thumb, 0 bytes, Stack size unknown bytes, __rtentry2.o(.ARM.Collect$$rtentry$$00000009))

__rt_entry_main (Thumb, 0 bytes, Stack size unknown bytes, __rtentry2.o(.ARM.Collect$$rtentry$$0000000D))

[Stack]

- Max Depth = 176 + Unknown Stack Size
- Call Chain = __rt_entry_main ⇒ main ⇒ sprintf ⇒ _printf_char_common ⇒ __printf

[Calls]

- >> main
- >> exit

__rt_entry_postli_1 (Thumb, 0 bytes, Stack size unknown bytes, __rtentry2.o(.ARM.Collect$$rtentry$$0000000C))

__rt_exit (Thumb, 0 bytes, Stack size unknown bytes, rtexit.o(.ARM.Collect$$rtexit$$00000000))

[Called By]

- >> exit

__rt_exit_ls (Thumb, 0 bytes, Stack size unknown bytes, rtexit2.o(.ARM.Collect$$rtexit$$00000003))

[Calls]

- >> __rt_lib_shutdown

__rt_exit_prels_1 (Thumb, 0 bytes, Stack size unknown bytes, rtexit2.o(.ARM.Collect$$rtexit$$00000002))

__rt_exit_exit (Thumb, 0 bytes, Stack size unknown bytes, rtexit2.o(.ARM.Collect$$rtexit$$00000004))

[Calls]

- >> _sys_exit

Reset_Handler (Thumb, 8 bytes, Stack size 0 bytes, startup_stm32f10x_md.o(.text))
[Address Reference Count : 1]

- startup_stm32f10x_md.o(RESET)

NMI_Handler (Thumb, 2 bytes, Stack size 0 bytes, startup_stm32f10x_md.o(.text))

[Calls]

- >> NMI_Handler

[Called By]

- >> NMI_Handler

[Address Reference Count : 1]

- startup_stm32f10x_md.o(RESET)

HardFault_Handler (Thumb, 2 bytes, Stack size 0 bytes, startup_stm32f10x_md.o(.text))

[Calls]

- >> HardFault_Handler

[Called By]

- >> HardFault_Handler

[Address Reference Count : 1]

- startup_stm32f10x_md.o(RESET)

MemManage_Handler (Thumb, 2 bytes, Stack size 0 bytes, startup_stm32f10x_md.o(.text))

[Calls]

- >> MemManage_Handler

[Called By]

- >> MemManage_Handler

[Address Reference Count : 1]

- startup_stm32f10x_md.o(RESET)

BusFault_Handler (Thumb, 2 bytes, Stack size 0 bytes, startup_stm32f10x_md.o(.text))

[Calls]

- >> BusFault_Handler

[Called By]

- >> BusFault_Handler

[Address Reference Count : 1]

- startup_stm32f10x_md.o(RESET)

UsageFault_Handler (Thumb, 2 bytes, Stack size 0 bytes, startup_stm32f10x_md.o(.text))

[Calls]

- >> UsageFault_Handler

[Called By]

- >> UsageFault_Handler

[Address Reference Count : 1]

- startup_stm32f10x_md.o(RESET)

SVC_Handler (Thumb, 2 bytes, Stack size 0 bytes, startup_stm32f10x_md.o(.text))

[Calls]

- >> SVC_Handler

[Called By]

- >> SVC_Handler

[Address Reference Count : 1]

- startup_stm32f10x_md.o(RESET)

DebugMon_Handler (Thumb, 2 bytes, Stack size 0 bytes, startup_stm32f10x_md.o(.text))

[Calls]

- >> DebugMon_Handler

[Called By]

- >> DebugMon_Handler

[Address Reference Count : 1]

- startup_stm32f10x_md.o(RESET)

PendSV_Handler (Thumb, 2 bytes, Stack size 0 bytes, startup_stm32f10x_md.o(.text))

[Calls]

- >> PendSV_Handler

[Called By]

- >> PendSV_Handler

[Address Reference Count : 1]

- startup_stm32f10x_md.o(RESET)

SysTick_Handler (Thumb, 2 bytes, Stack size 0 bytes, startup_stm32f10x_md.o(.text))

[Calls]

- >> SysTick_Handler

[Called By]

- >> SysTick_Handler

[Address Reference Count : 1]

- startup_stm32f10x_md.o(RESET)

ADC1_2_IRQHandler (Thumb, 0 bytes, Stack size 0 bytes, startup_stm32f10x_md.o(.text))

[Calls]

- >> ADC1_2_IRQHandler

[Called By]

- >> ADC1_2_IRQHandler

[Address Reference Count : 1]

- startup_stm32f10x_md.o(RESET)

CAN1_RX1_IRQHandler (Thumb, 0 bytes, Stack size 0 bytes, startup_stm32f10x_md.o(.text))
[Address Reference Count : 1]

- startup_stm32f10x_md.o(RESET)

CAN1_SCE_IRQHandler (Thumb, 0 bytes, Stack size 0 bytes, startup_stm32f10x_md.o(.text))
[Address Reference Count : 1]

- startup_stm32f10x_md.o(RESET)

DMA1_Channel1_IRQHandler (Thumb, 0 bytes, Stack size 0 bytes, startup_stm32f10x_md.o(.text))
[Address Reference Count : 1]

- startup_stm32f10x_md.o(RESET)

DMA1_Channel2_IRQHandler (Thumb, 0 bytes, Stack size 0 bytes, startup_stm32f10x_md.o(.text))
[Address Reference Count : 1]

- startup_stm32f10x_md.o(RESET)

DMA1_Channel3_IRQHandler (Thumb, 0 bytes, Stack size 0 bytes, startup_stm32f10x_md.o(.text))
[Address Reference Count : 1]

- startup_stm32f10x_md.o(RESET)

DMA1_Channel4_IRQHandler (Thumb, 0 bytes, Stack size 0 bytes, startup_stm32f10x_md.o(.text))
[Address Reference Count : 1]

- startup_stm32f10x_md.o(RESET)

DMA1_Channel5_IRQHandler (Thumb, 0 bytes, Stack size 0 bytes, startup_stm32f10x_md.o(.text))
[Address Reference Count : 1]

- startup_stm32f10x_md.o(RESET)

DMA1_Channel6_IRQHandler (Thumb, 0 bytes, Stack size 0 bytes, startup_stm32f10x_md.o(.text))
[Address Reference Count : 1]

- startup_stm32f10x_md.o(RESET)

DMA1_Channel7_IRQHandler (Thumb, 0 bytes, Stack size 0 bytes, startup_stm32f10x_md.o(.text))
[Address Reference Count : 1]

- startup_stm32f10x_md.o(RESET)

EXTI0_IRQHandler (Thumb, 0 bytes, Stack size 0 bytes, startup_stm32f10x_md.o(.text))
[Address Reference Count : 1]

- startup_stm32f10x_md.o(RESET)

EXTI15_10_IRQHandler (Thumb, 0 bytes, Stack size 0 bytes, startup_stm32f10x_md.o(.text))
[Address Reference Count : 1]

- startup_stm32f10x_md.o(RESET)

EXTI1_IRQHandler (Thumb, 0 bytes, Stack size 0 bytes, startup_stm32f10x_md.o(.text))
[Address Reference Count : 1]

- startup_stm32f10x_md.o(RESET)

EXTI2_IRQHandler (Thumb, 0 bytes, Stack size 0 bytes, startup_stm32f10x_md.o(.text))
[Address Reference Count : 1]

- startup_stm32f10x_md.o(RESET)
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

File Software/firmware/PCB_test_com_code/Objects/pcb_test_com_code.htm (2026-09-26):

# Static Call Graph for image .\Objects\pcb_test_com_code.axf

#<CALLGRAPH># ARM Linker, 6190004: Last Updated: Sat Sep 26 12:09:29 2026

### Maximum Stack Usage = 324 bytes + Unknown(Functions without stacksize, Cycles, Untraceable Function Pointers)

### Call chain for Maximum Stack Depth:

_printf_f ⇒ _printf_fp_dec ⇒ _printf_fp_dec_real ⇒ _fp_digits ⇒ _btod_etento ⇒ _btod_emul ⇒ _e2e

### Functions with no stack information

- __user_initial_stackheap

### Mutually Recursive functions

- NMI_Handler ⇒ NMI_Handler
- HardFault_Handler ⇒ HardFault_Handler
- MemManage_Handler ⇒ MemManage_Handler
- BusFault_Handler ⇒ BusFault_Handler
- UsageFault_Handler ⇒ UsageFault_Handler
- SVC_Handler ⇒ SVC_Handler
- DebugMon_Handler ⇒ DebugMon_Handler
- PendSV_Handler ⇒ PendSV_Handler
- SysTick_Handler ⇒ SysTick_Handler
- ADC1_2_IRQHandler ⇒ ADC1_2_IRQHandler

### Function Pointers

- ADC1_2_IRQHandler from startup_stm32f10x_md.o(.text) referenced from startup_stm32f10x_md.o(RESET)
- BusFault_Handler from startup_stm32f10x_md.o(.text) referenced from startup_stm32f10x_md.o(RESET)
- CAN1_RX1_IRQHandler from startup_stm32f10x_md.o(.text) referenced from startup_stm32f10x_md.o(RESET)
- CAN1_SCE_IRQHandler from startup_stm32f10x_md.o(.text) referenced from startup_stm32f10x_md.o(RESET)
- DMA1_Channel1_IRQHandler from startup_stm32f10x_md.o(.text) referenced from startup_stm32f10x_md.o(RESET)
- DMA1_Channel2_IRQHandler from startup_stm32f10x_md.o(.text) referenced from startup_stm32f10x_md.o(RESET)
- DMA1_Channel3_IRQHandler from startup_stm32f10x_md.o(.text) referenced from startup_stm32f10x_md.o(RESET)
- DMA1_Channel4_IRQHandler from startup_stm32f10x_md.o(.text) referenced from startup_stm32f10x_md.o(RESET)
- DMA1_Channel5_IRQHandler from startup_stm32f10x_md.o(.text) referenced from startup_stm32f10x_md.o(RESET)
- DMA1_Channel6_IRQHandler from startup_stm32f10x_md.o(.text) referenced from startup_stm32f10x_md.o(RESET)
- DMA1_Channel7_IRQHandler from startup_stm32f10x_md.o(.text) referenced from startup_stm32f10x_md.o(RESET)
- DebugMon_Handler from startup_stm32f10x_md.o(.text) referenced from startup_stm32f10x_md.o(RESET)
- EXTI0_IRQHandler from startup_stm32f10x_md.o(.text) referenced from startup_stm32f10x_md.o(RESET)
- EXTI15_10_IRQHandler from startup_stm32f10x_md.o(.text) referenced from startup_stm32f10x_md.o(RESET)
- EXTI1_IRQHandler from startup_stm32f10x_md.o(.text) referenced from startup_stm32f10x_md.o(RESET)
- EXTI2_IRQHandler from startup_stm32f10x_md.o(.text) referenced from startup_stm32f10x_md.o(RESET)
- EXTI3_IRQHandler from startup_stm32f10x_md.o(.text) referenced from startup_stm32f10x_md.o(RESET)
- EXTI4_IRQHandler from startup_stm32f10x_md.o(.text) referenced from startup_stm32f10x_md.o(RESET)
- EXTI9_5_IRQHandler from startup_stm32f10x_md.o(.text) referenced from startup_stm32f10x_md.o(RESET)
- FLASH_IRQHandler from startup_stm32f10x_md.o(.text) referenced from startup_stm32f10x_md.o(RESET)
- HardFault_Handler from startup_stm32f10x_md.o(.text) referenced from startup_stm32f10x_md.o(RESET)
- I2C1_ER_IRQHandler from startup_stm32f10x_md.o(.text) referenced from startup_stm32f10x_md.o(RESET)
- I2C1_EV_IRQHandler from startup_stm32f10x_md.o(.text) referenced from startup_stm32f10x_md.o(RESET)
- I2C2_ER_IRQHandler from startup_stm32f10x_md.o(.text) referenced from startup_stm32f10x_md.o(RESET)
- I2C2_EV_IRQHandler from startup_stm32f10x_md.o(.text) referenced from startup_stm32f10x_md.o(RESET)
- MemManage_Handler from startup_stm32f10x_md.o(.text) referenced from startup_stm32f10x_md.o(RESET)
- NMI_Handler from startup_stm32f10x_md.o(.text) referenced from startup_stm32f10x_md.o(RESET)
- PVD_IRQHandler from startup_stm32f10x_md.o(.text) referenced from startup_stm32f10x_md.o(RESET)
- PendSV_Handler from startup_stm32f10x_md.o(.text) referenced from startup_stm32f10x_md.o(RESET)
- RCC_IRQHandler from startup_stm32f10x_md.o(.text) referenced from startup_stm32f10x_md.o(RESET)
- RTCAlarm_IRQHandler from startup_stm32f10x_md.o(.text) referenced from startup_stm32f10x_md.o(RESET)
- RTC_IRQHandler from startup_stm32f10x_md.o(.text) referenced from startup_stm32f10x_md.o(RESET)
- Reset_Handler from startup_stm32f10x_md.o(.text) referenced from startup_stm32f10x_md.o(RESET)
- SPI1_IRQHandler from startup_stm32f10x_md.o(.text) referenced from startup_stm32f10x_md.o(RESET)
- SPI2_IRQHandler from startup_stm32f10x_md.o(.text) referenced from startup_stm32f10x_md.o(RESET)
- SVC_Handler from startup_stm32f10x_md.o(.text) referenced from startup_stm32f10x_md.o(RESET)
- SysTick_Handler from startup_stm32f10x_md.o(.text) referenced from startup_stm32f10x_md.o(RESET)
- SystemInit from system_stm32f10x.o(.text.SystemInit) referenced from startup_stm32f10x_md.o(.text)
- TAMPER_IRQHandler from startup_stm32f10x_md.o(.text) referenced from startup_stm32f10x_md.o(RESET)
- TIM1_BRK_IRQHandler from startup_stm32f10x_md.o(.text) referenced from startup_stm32f10x_md.o(RESET)
- TIM1_CC_IRQHandler from startup_stm32f10x_md.o(.text) referenced from startup_stm32f10x_md.o(RESET)
- TIM1_TRG_COM_IRQHandler from startup_stm32f10x_md.o(.text) referenced from startup_stm32f10x_md.o(RESET)
- TIM1_UP_IRQHandler from startup_stm32f10x_md.o(.text) referenced from startup_stm32f10x_md.o(RESET)
- TIM2_IRQHandler from startup_stm32f10x_md.o(.text) referenced from startup_stm32f10x_md.o(RESET)
- TIM3_IRQHandler from startup_stm32f10x_md.o(.text) referenced from startup_stm32f10x_md.o(RESET)
- TIM4_IRQHandler from startup_stm32f10x_md.o(.text) referenced from startup_stm32f10x_md.o(RESET)
- USART1_IRQHandler from uart.o(.text.USART1_IRQHandler) referenced from startup_stm32f10x_md.o(RESET)
- USART2_IRQHandler from startup_stm32f10x_md.o(.text) referenced from startup_stm32f10x_md.o(RESET)
- USART3_IRQHandler from startup_stm32f10x_md.o(.text) referenced from startup_stm32f10x_md.o(RESET)
- USBWakeUp_IRQHandler from startup_stm32f10x_md.o(.text) referenced from startup_stm32f10x_md.o(RESET)
- USB_HP_CAN1_TX_IRQHandler from startup_stm32f10x_md.o(.text) referenced from startup_stm32f10x_md.o(RESET)
- USB_LP_CAN1_RX0_IRQHandler from startup_stm32f10x_md.o(.text) referenced from startup_stm32f10x_md.o(RESET)
- UsageFault_Handler from startup_stm32f10x_md.o(.text) referenced from startup_stm32f10x_md.o(RESET)
- WWDG_IRQHandler from startup_stm32f10x_md.o(.text) referenced from startup_stm32f10x_md.o(RESET)
- __main from __main.o(!!!main) referenced from startup_stm32f10x_md.o(.text)
- _get_lc_ctype from lc_ctype_c.o(locale$$code) referenced from rt_ctype_table.o(.text)
- _printf_input_char from _printf_char_common.o(.text) referenced from _printf_char_common.o(.text)
- _sputc from _sputc.o(.text) referenced from sprintf.o(.text)

### Global Symbols

__main (Thumb, 8 bytes, Stack size 0 bytes, __main.o(!!!main))

[Calls]

- >> __rt_entry
- >> __scatterload

[Address Reference Count : 1]

- startup_stm32f10x_md.o(.text)

__scatterload (Thumb, 0 bytes, Stack size unknown bytes, __scatter.o(!!!scatter))

[Called By]

- >> __main

__scatterload_rt2 (Thumb, 44 bytes, Stack size unknown bytes, __scatter.o(!!!scatter), UNUSED)

[Calls]

- >> __rt_entry

__scatterload_rt2_thumb_only (Thumb, 0 bytes, Stack size unknown bytes, __scatter.o(!!!scatter), UNUSED)

__scatterload_null (Thumb, 0 bytes, Stack size unknown bytes, __scatter.o(!!!scatter), UNUSED)

__decompress (Thumb, 100 bytes, Stack size unknown bytes, __dclz77c.o(!!dclz77c), UNUSED)

__decompress2 (Thumb, 0 bytes, Stack size unknown bytes, __dclz77c.o(!!dclz77c), UNUSED)

__scatterload_zeroinit (Thumb, 28 bytes, Stack size unknown bytes, __scatter_zi.o(!!handler_zi), UNUSED)

_printf_n (Thumb, 0 bytes, Stack size unknown bytes, _printf_n.o(.ARM.Collect$$_printf_percent$$00000001))

[Calls]

- >> _printf_charcount

_printf_percent (Thumb, 0 bytes, Stack size unknown bytes, _printf_percent.o(.ARM.Collect$$_printf_percent$$00000000))

[Called By]

- >> __printf

_printf_p (Thumb, 0 bytes, Stack size unknown bytes, _printf_p.o(.ARM.Collect$$_printf_percent$$00000002))

[Stack]

- Max Depth = 64 + Unknown Stack Size
- Call Chain = _printf_p ⇒ _printf_hex_ptr ⇒ _printf_longlong_hex ⇒ _printf_int_common ⇒ _printf_post_padding

[Calls]

- >> _printf_hex_ptr

_printf_f (Thumb, 0 bytes, Stack size unknown bytes, _printf_f.o(.ARM.Collect$$_printf_percent$$00000003))

[Stack]

- Max Depth = 324 + Unknown Stack Size
- Call Chain = _printf_f ⇒ _printf_fp_dec ⇒ _printf_fp_dec_real ⇒ _fp_digits ⇒ _btod_etento ⇒ _btod_emul ⇒ _e2e

[Calls]

- >> _printf_fp_dec

_printf_e (Thumb, 0 bytes, Stack size unknown bytes, _printf_e.o(.ARM.Collect$$_printf_percent$$00000004))

[Stack]

- Max Depth = 324 + Unknown Stack Size
- Call Chain = _printf_e ⇒ _printf_fp_dec ⇒ _printf_fp_dec_real ⇒ _fp_digits ⇒ _btod_etento ⇒ _btod_emul ⇒ _e2e

[Calls]

- >> _printf_fp_dec

_printf_g (Thumb, 0 bytes, Stack size unknown bytes, _printf_g.o(.ARM.Collect$$_printf_percent$$00000005))

[Stack]

- Max Depth = 324 + Unknown Stack Size
- Call Chain = _printf_g ⇒ _printf_fp_dec ⇒ _printf_fp_dec_real ⇒ _fp_digits ⇒ _btod_etento ⇒ _btod_emul ⇒ _e2e

[Calls]

- >> _printf_fp_dec

_printf_a (Thumb, 0 bytes, Stack size unknown bytes, _printf_a.o(.ARM.Collect$$_printf_percent$$00000006))

[Stack]

- Max Depth = 112 + Unknown Stack Size
- Call Chain = _printf_a ⇒ _printf_fp_hex ⇒ _printf_fp_hex_real ⇒ _printf_fp_infnan ⇒ _printf_post_padding

[Calls]

- >> _printf_fp_hex

_printf_ll (Thumb, 0 bytes, Stack size unknown bytes, _printf_ll.o(.ARM.Collect$$_printf_percent$$00000007))

_printf_i (Thumb, 0 bytes, Stack size unknown bytes, _printf_i.o(.ARM.Collect$$_printf_percent$$00000008))

[Stack]

- Max Depth = 72 + Unknown Stack Size
- Call Chain = _printf_i ⇒ _printf_int_dec ⇒ _printf_int_common ⇒ _printf_post_padding

[Calls]

- >> _printf_int_dec

_printf_d (Thumb, 0 bytes, Stack size unknown bytes, _printf_d.o(.ARM.Collect$$_printf_percent$$00000009))

[Stack]

- Max Depth = 72 + Unknown Stack Size
- Call Chain = _printf_d ⇒ _printf_int_dec ⇒ _printf_int_common ⇒ _printf_post_padding

[Calls]

- >> _printf_int_dec

_printf_u (Thumb, 0 bytes, Stack size unknown bytes, _printf_u.o(.ARM.Collect$$_printf_percent$$0000000A))

[Stack]

- Max Depth = 72 + Unknown Stack Size
- Call Chain = _printf_u ⇒ _printf_int_dec ⇒ _printf_int_common ⇒ _printf_post_padding

[Calls]

- >> _printf_int_dec

_printf_o (Thumb, 0 bytes, Stack size unknown bytes, _printf_o.o(.ARM.Collect$$_printf_percent$$0000000B))

[Stack]

- Max Depth = 64 + Unknown Stack Size
- Call Chain = _printf_o ⇒ _printf_int_oct ⇒ _printf_longlong_oct ⇒ _printf_int_common ⇒ _printf_post_padding

[Calls]

- >> _printf_int_oct

_printf_x (Thumb, 0 bytes, Stack size unknown bytes, _printf_x.o(.ARM.Collect$$_printf_percent$$0000000C))

[Stack]

- Max Depth = 80 + Unknown Stack Size
- Call Chain = _printf_x ⇒ _printf_int_hex ⇒ _printf_longlong_hex ⇒ _printf_int_common ⇒ _printf_post_padding

[Calls]

- >> _printf_int_hex

_printf_lli (Thumb, 0 bytes, Stack size unknown bytes, _printf_lli.o(.ARM.Collect$$_printf_percent$$0000000D))

[Stack]

- Max Depth = 72 + Unknown Stack Size
- Call Chain = _printf_lli ⇒ _printf_longlong_dec ⇒ _printf_int_common ⇒ _printf_post_padding

[Calls]

- >> _printf_longlong_dec

_printf_lld (Thumb, 0 bytes, Stack size unknown bytes, _printf_lld.o(.ARM.Collect$$_printf_percent$$0000000E))

[Stack]

- Max Depth = 72 + Unknown Stack Size
- Call Chain = _printf_lld ⇒ _printf_longlong_dec ⇒ _printf_int_common ⇒ _printf_post_padding

[Calls]

- >> _printf_longlong_dec

_printf_llu (Thumb, 0 bytes, Stack size unknown bytes, _printf_llu.o(.ARM.Collect$$_printf_percent$$0000000F))

[Stack]

- Max Depth = 72 + Unknown Stack Size
- Call Chain = _printf_llu ⇒ _printf_longlong_dec ⇒ _printf_int_common ⇒ _printf_post_padding

[Calls]

- >> _printf_longlong_dec

_printf_llo (Thumb, 0 bytes, Stack size unknown bytes, _printf_llo.o(.ARM.Collect$$_printf_percent$$00000010))

[Stack]

- Max Depth = 56 + Unknown Stack Size
- Call Chain = _printf_llo ⇒ _printf_ll_oct ⇒ _printf_longlong_oct ⇒ _printf_int_common ⇒ _printf_post_padding

[Calls]

- >> _printf_ll_oct

_printf_llx (Thumb, 0 bytes, Stack size unknown bytes, _printf_llx.o(.ARM.Collect$$_printf_percent$$00000011))

[Stack]

- Max Depth = 64 + Unknown Stack Size
- Call Chain = _printf_llx ⇒ _printf_ll_hex ⇒ _printf_longlong_hex ⇒ _printf_int_common ⇒ _printf_post_padding

[Calls]

- >> _printf_ll_hex

_printf_l (Thumb, 0 bytes, Stack size unknown bytes, _printf_l.o(.ARM.Collect$$_printf_percent$$00000012))

_printf_c (Thumb, 0 bytes, Stack size unknown bytes, _printf_c.o(.ARM.Collect$$_printf_percent$$00000013))

[Stack]

- Max Depth = 40 + Unknown Stack Size
- Call Chain = _printf_c ⇒ _printf_char ⇒ _printf_cs_common ⇒ _printf_str ⇒ _printf_post_padding

[Calls]

- >> _printf_char

_printf_s (Thumb, 0 bytes, Stack size unknown bytes, _printf_s.o(.ARM.Collect$$_printf_percent$$00000014))

[Stack]

- Max Depth = 40 + Unknown Stack Size
- Call Chain = _printf_s ⇒ _printf_string ⇒ _printf_cs_common ⇒ _printf_str ⇒ _printf_post_padding

[Calls]

- >> _printf_string

_printf_lc (Thumb, 0 bytes, Stack size unknown bytes, _printf_lc.o(.ARM.Collect$$_printf_percent$$00000015))

[Stack]

- Max Depth = 88 + Unknown Stack Size
- Call Chain = _printf_lc ⇒ _printf_wchar ⇒ _printf_lcs_common ⇒ _printf_wctomb ⇒ _wcrtomb

[Calls]

- >> _printf_wchar

_printf_ls (Thumb, 0 bytes, Stack size unknown bytes, _printf_ls.o(.ARM.Collect$$_printf_percent$$00000016))

[Stack]

- Max Depth = 88 + Unknown Stack Size
- Call Chain = _printf_ls ⇒ _printf_wstring ⇒ _printf_lcs_common ⇒ _printf_wctomb ⇒ _wcrtomb

[Calls]

- >> _printf_wstring

_printf_percent_end (Thumb, 0 bytes, Stack size unknown bytes, _printf_percent_end.o(.ARM.Collect$$_printf_percent$$00000017))

__rt_lib_init (Thumb, 0 bytes, Stack size unknown bytes, libinit.o(.ARM.Collect$$libinit$$00000000))

[Called By]

- >> __rt_entry_li

__rt_lib_init_fp_1 (Thumb, 0 bytes, Stack size unknown bytes, libinit2.o(.ARM.Collect$$libinit$$00000002))

__rt_lib_init_heap_1 (Thumb, 0 bytes, Stack size unknown bytes, libinit2.o(.ARM.Collect$$libinit$$0000000C))

__rt_lib_init_lc_common (Thumb, 0 bytes, Stack size unknown bytes, libinit2.o(.ARM.Collect$$libinit$$00000011))

[Calls]

- >> __rt_locale

__rt_lib_init_preinit_1 (Thumb, 0 bytes, Stack size unknown bytes, libinit2.o(.ARM.Collect$$libinit$$00000006))

__rt_lib_init_rand_1 (Thumb, 0 bytes, Stack size unknown bytes, libinit2.o(.ARM.Collect$$libinit$$00000010))

__rt_lib_init_relocate_pie_1 (Thumb, 0 bytes, Stack size unknown bytes, libinit2.o(.ARM.Collect$$libinit$$00000004))

__rt_lib_init_user_alloc_1 (Thumb, 0 bytes, Stack size unknown bytes, libinit2.o(.ARM.Collect$$libinit$$0000000E))

__rt_lib_init_lc_collate_1 (Thumb, 0 bytes, Stack size unknown bytes, libinit2.o(.ARM.Collect$$libinit$$00000013))

__rt_lib_init_lc_ctype_2 (Thumb, 0 bytes, Stack size unknown bytes, libinit2.o(.ARM.Collect$$libinit$$00000014))

[Stack]

- Max Depth = 8 + Unknown Stack Size
- Call Chain = __rt_lib_init_lc_ctype_2 ⇒ _get_lc_ctype

[Calls]

- >> _get_lc_ctype

__rt_lib_init_lc_ctype_1 (Thumb, 0 bytes, Stack size unknown bytes, libinit2.o(.ARM.Collect$$libinit$$00000015))

__rt_lib_init_lc_monetary_1 (Thumb, 0 bytes, Stack size unknown bytes, libinit2.o(.ARM.Collect$$libinit$$00000017))

__rt_lib_init_lc_numeric_2 (Thumb, 0 bytes, Stack size unknown bytes, libinit2.o(.ARM.Collect$$libinit$$00000018))

[Stack]

- Max Depth = 8 + Unknown Stack Size
- Call Chain = __rt_lib_init_lc_numeric_2 ⇒ _get_lc_numeric

[Calls]

- >> _get_lc_numeric

__rt_lib_init_alloca_1 (Thumb, 0 bytes, Stack size unknown bytes, libinit2.o(.ARM.Collect$$libinit$$00000030))

__rt_lib_init_argv_1 (Thumb, 0 bytes, Stack size unknown bytes, libinit2.o(.ARM.Collect$$libinit$$0000002E))

__rt_lib_init_atexit_1 (Thumb, 0 bytes, Stack size unknown bytes, libinit2.o(.ARM.Collect$$libinit$$0000001D))

__rt_lib_init_clock_1 (Thumb, 0 bytes, Stack size unknown bytes, libinit2.o(.ARM.Collect$$libinit$$00000023))
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

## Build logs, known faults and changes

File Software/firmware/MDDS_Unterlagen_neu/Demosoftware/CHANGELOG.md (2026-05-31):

0.9.3 [2022-10-21]:
-------------------
 * Anpassung der Schalterreihenfolge wegen neuer Revision (Rev03)
   von PMOD Switches Modul
 * Anpassung der LED-Reihenfolge wegen neuer Revsion (Rev03)
   von PMOD LEDs Modul

0.9.2 [2020-10-05]:
-------------------
 * Format UART1 output (PC communication)
 * Support different DS18B20 variants
 * Code cleanup

0.9.1 [2020-09-27]:
-------------------
 * BUGFIX: Temperature sensor read process

0.9.0 [2020-09-26]:
-------------------
 * initial version

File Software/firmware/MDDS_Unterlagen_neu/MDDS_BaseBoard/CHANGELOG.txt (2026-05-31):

Rev. 5 [2020-01-30]:
==================== 
 * Doppelten Spannungsversorgungs-Umschalter eingebaut:
   33V_R/50_R <-> 33V_M/50V_M
 * Bestueckungsplan aktualisiert
 * Schaltplan-Template aktualisiert
 * Alle Vias sind nun "tented"
 * PMOD Pins entsprechend der PMOD Spezifikation nummeriert und beschriftet:
   https://reference.digilentinc.com/_media/reference/pmod/pmod-interface-specification-1_1_0.pdf

Rev. 4 [2019-01-14]:
====================
 * LED V1 durch SMD 0805 ersetzt
 * Schalter S1 durch SMD-Taster ersetzt
 * Stecker X13 hinzugefügt, um das Display mit 5V versorgen zu können
 * Beschriftung: "DIL" und "RPi" bei Stecker X8 war vertauscht
 * Bei Stecker X9 den PIN für den Schreibschutz beschriftet ("nWP")
 * Umstellung auf Versionierung mit GIT

Rev. 3 [2018-10-07]:
====================
 * Teardrops überall hinzugefügt
 * Neues HTL-Logo verwendet
 * I2C Pull-Up (Jumperbar)
 * GND-Jumper hinzugefügt
 * Temperaturfühler DS18B20 hinzugefügt
 * Active BOM Stückliste erstellt (ermöglich einfache Bestellung)
 * PMOD1 angepasst: PMOD Spec. konform UART, SPI (STM32F103RB)
 * PMOD2 angepasst: PMOD Spec. konform I2C (STM32F103RB)
 * PMOD3 angepasst: PMOD Spec. konform UART (STM32F103RB)
 * DIL-Reset-PIN mit Raspberry GPIO20 verbunden
 * RPI SPI0 auf 103 SPI1 korrigiert (auf RPI 40 polig)
 * EEPROM auf V33 (statt V33_R) gehängt, damit es auch ohne
   Raspberry Pi versorgt ist und von DIL angesprochen werden kann

Rev. 2 [2017-10-22]:
====================
 * Abmessungen exakt auf die Raspberry Pi HAT-Specification angepasst:
   https://github.com/raspberrypi/hats/blob/master/hat-board-mechanical.pdf
   (Platine wurde dadurch etwas kleiner)
 * Verzinnung bei Befestigungsbohrungen entfernt
 * Ursprung versetzt
 * Bemaßung verbessert
 * Fertigungsdokumenteinstellungen
 * Beschriftungen "BS" und "LS" hinzugefügt (Silkscreen)
 * Teardrops bei PMODs und Stiftleisten hinzugefügt
 * Leiterbahnen weiter vom Rand entfernt platziert
 * Gerberdateien und Drilldaten für PcbWay erzeugt:
   MAX1000BaseBoard_Gerber_Rev_2.zip

Rev. 1 [2017-09-12]:
====================
 * Initiales Release
 * Produktion von 20 Stück bei pcbway.com

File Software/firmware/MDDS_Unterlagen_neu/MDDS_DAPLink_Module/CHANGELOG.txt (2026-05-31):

Rev. 2 [2020-06-07]:
====================
 o Vorwiderstände bei LEDs auf von 560 Ohm -> 1k geändert

Rev. 1 [2019-12-09]:
====================
 o Initiales Release

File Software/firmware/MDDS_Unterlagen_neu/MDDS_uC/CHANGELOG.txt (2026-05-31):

Rev 9 [2020-06-29]:
===================
 * Automatische Stückliste fertig gemacht (Stueckliste.BomDoc)
 * PMOD Pins entsprechend der PMOD Spezifikation nummeriert und beschriftet:
   https://reference.digilentinc.com/_media/reference/pmod/pmod-interface-specification-1_1_0.pdf
 * Target.SchDoc: Grafik/Screenshot von MDDS uC PCB getauscht

Rev. 8 [2019-12-09]:
====================
 * Der Debugger "DAPLink" wird nun ist nun als Modul ausgeführt, um
   ein einfacheres Bestücken für Schüler des 3. Jahrgangs zu ermöglichen
 * Alle Vias auf "tented" umgestellt
 * Die PMOD-Buchse ist nun 2-reihig
   -> zusätzliche Leitungen PC6 und PC10 (+zwei andere rausführen)
      (werden für Audio-Modul benötigt)
   -> USB_DP, USB_DM sind nun ebenfalls bei dieser Buchse verfügbar
 * Auf kompaktere P-Channel-Mosfets bei Stromversorgung gewechselt:
   FDS9933A -> TT8J11 (Rohm)
 * Vorwiderstand bei Power-LED (Power_Supply.SchDoc) erhöht: 560 Ohm -> 2.7 kOhm
 * Footprint bei Power-LED (Power_Supply.SchDoc) geändert: 0603 -> 0805
 * USB-Schnittstelle (Stiftleiste) entfernt, USB_DP/USB_DM stattdessen auf PMOD
 * PowerSupply: LDO ersetzt - LMS8117ADT_3.3 -> TLV1117LV33DCYR (kleinerer Footprint)
 * PowerSupply: Mosfets ersetzt: FDS9933A (SO-8) ->
 * Resettaster ersetzt: Randschalter ersetzt

Rev. 7 [2018-11-12]:
====================
 * HTL-Template (A4) aktualisiert
 * PcbDoc umbenannt: "DIL-28.PcbDoc" -> "MDDC_uC_103.PcbDoc"
 * Beschriftungsbereich unter PMOD (Bottom) hinzugefügt
 * Samtec Buchsenleisten-Footprint gesetzt und gedreht
   (Stiftleiste war unten)
 * PCB-Grafik in Target-Schematic eingefügt
 * Cortex Pin-Nummer Beschriftung bei Buchsenleiste hinzugefügt
 * GND-Pin bei USB-Stiftleiste beschriftet

Rev. 6 [2018-10-08]:
====================
 * Abstand der Leiterbahnen zum Rand muss >= 0.25mm sein

Rev. 5 [2018-10-08]:
====================
 * Holesize auf >= 0.3 mm erhöht, damit günstiger produziert werden kann
   (Footprint angepasst: LPC11U35FHI33_501_Rev2.IntLib)

Rev. 4 [2018-10-07]:
====================
 * Clearance angepasst (>= 6 mil) damit günstiger
   produziert werden kann
 * USB-Device 3-PIN Header für Kabel hinzugefügt
 * Neues HTL-Logo
 * Reset Taster bei Target entfernt
 * SWD-Leitungen von Target auf Stecker geführt
   (ermöglicht zukünftig auch ein Bestücken ohne Debugger)
 * Reset des Targets wurde auch auf Steckerleiste geführt
 * Versorgungsleitungen teilweise verbreitert

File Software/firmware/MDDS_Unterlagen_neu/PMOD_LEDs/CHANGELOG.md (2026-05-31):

Rev. 03 [2022-04-22]:
=====================
 * Florian Kralitschek:
   LED-Reihenfolge an Baseboard PA0-PA7 angepasst
   (damit 1 Byte in der richtigen Reihenfolge ausgegeben wird)

Rev. 02 [2020-08-23]:
=====================
 * Widerstandswerte im Schaltplan angepasst (Tests Wolfgang Kauer):
   Rot, Gelb: 2.7k
   Grün:      3.9k
 * Korrektur: Beschriftung beim Schalter "LEDs" und "7Seg" waren
              vertauscht
 * Alle Vias auf "Tented" umgestellt
 * Teardrops hinzugefügt
 * Kathodenlinie bei LEDs hinzugefügt
 * PMOD Pins entsprechend der PMOD Spezifikation nummeriert und beschriftet:
   https://reference.digilentinc.com/_media/reference/pmod/pmod-interface-specification-1_1_0.pdf

Rev. 01 [2019-01-14]
====================
 * initial release

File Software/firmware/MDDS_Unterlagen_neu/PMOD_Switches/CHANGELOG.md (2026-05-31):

Rev. 03 [2022-04-22]:
=====================
 * Florian Kralitschek:
   Ändern des Schalter-Aufdrucks von Schalter (DIP <==> ENC)
   Ändern der PMOD Belgung (Wunsch Josef Reisinger)

Rev. 02 [2020-08-23]:
=====================
 * Alle Vias auf "Tented" umgestellt
 * Teardrops hinzugefügt
 * PMOD Pins entsprechend der PMOD Spezifikation nummeriert und beschriftet:
   https://reference.digilentinc.com/_media/reference/pmod/pmod-interface-specification-1_1_0.pdf

Rev. 01 [2019-01-14]
====================
 * initial release

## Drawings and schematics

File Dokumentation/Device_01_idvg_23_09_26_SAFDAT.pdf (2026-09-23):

## Device 01 IDVG

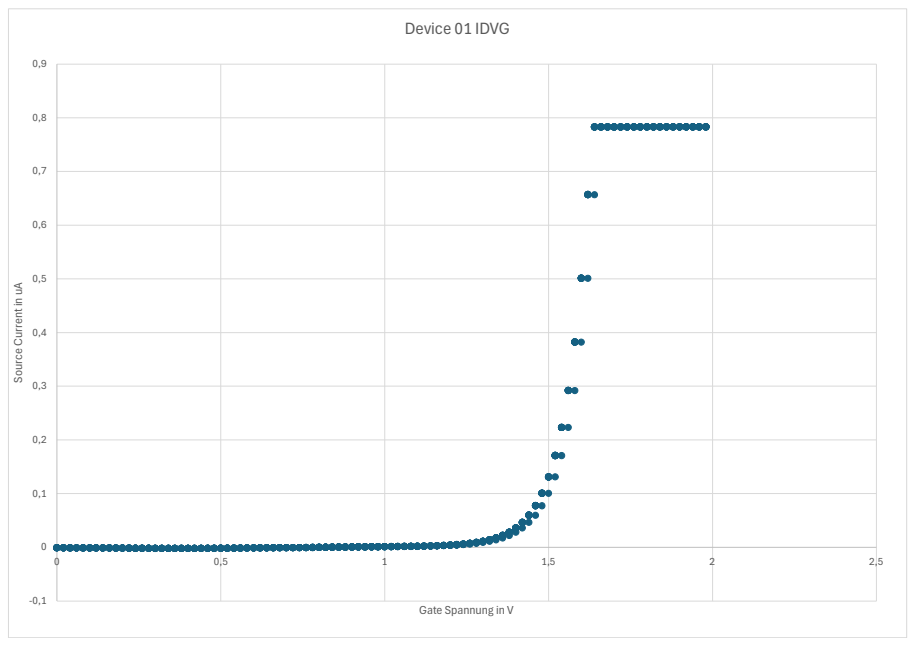
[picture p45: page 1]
2,5 Source Current in uA

Gate Spannung in V

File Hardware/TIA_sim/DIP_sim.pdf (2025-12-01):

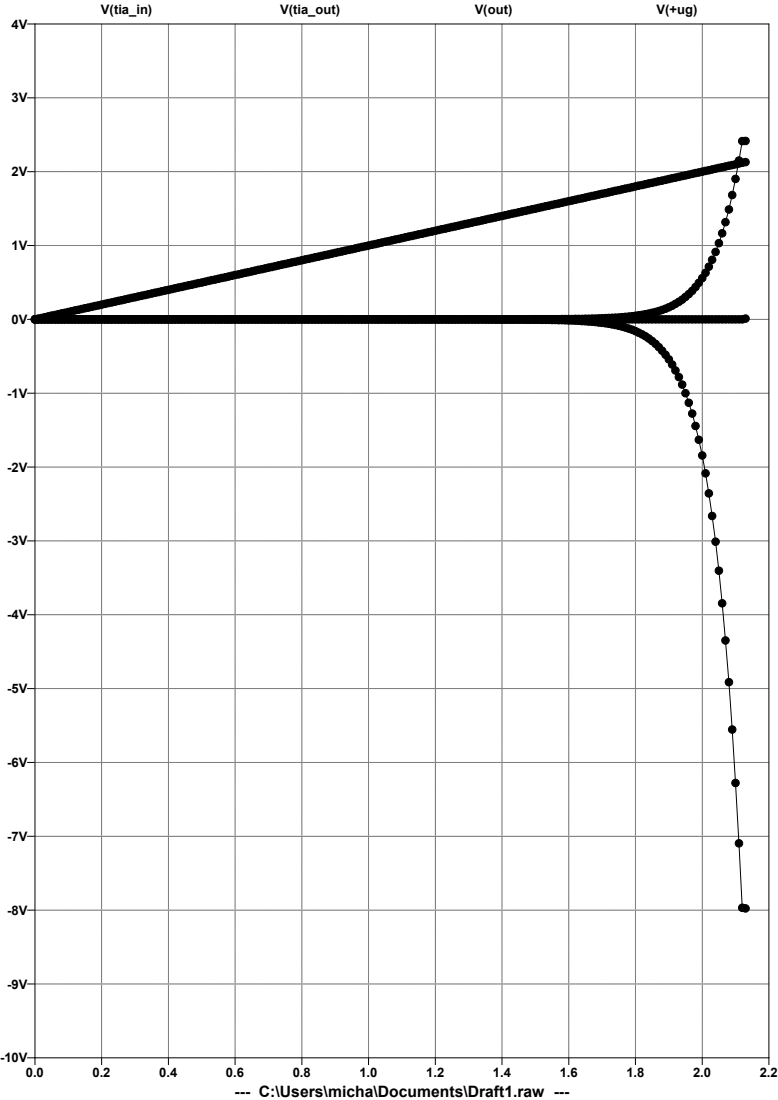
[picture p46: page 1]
V(tia_in); V(tia_out); V(out)

--- C:\Users\micha\Documents\Draft1.raw ---

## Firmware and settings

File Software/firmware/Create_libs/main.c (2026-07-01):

#include <stm32f10x.h>
#include <stdio.h>
#include <stdint.h>
#include <stdlib.h>
#include <stdbool.h>
#include <string.h>

#include "Pin_def_lib.h"
#include "UART1_com.h"
#include "SPI.h"
#include "ads8681_lib.h"

int main()
{
	set_up_uart1();
	spi1_init();
	
	ADC_SPI_NCS = 0;
	
	while(1)
	{
		uint32_t adc_wert = ADS8681_send_Command_blocking(ADS868X_SPI_COMMAND_NOP, ADS868X_REGISTER_ADDRESS_DEVICE_ID, 0x00);
		
		char temp_buffer[20];
	
		sprintf(temp_buffer, "adc_wert:%u\r\n", adc_wert);
	
		uart_put_string(temp_buffer);
	}
}

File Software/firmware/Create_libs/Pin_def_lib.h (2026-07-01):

#ifndef PIN_DEF_LIB_H
#define PIN_DEF_LIB_H

#define BITBAND_PERI(a,b) ((PERIPH_BB_BASE + (a-PERIPH_BASE)*32 + (b*4)))
#define GPIOA_ODR GPIOA_BASE + 3*sizeof(uint32_t)
#define GPIOA_IDR GPIOA_BASE + 2*sizeof(uint32_t)

#define ADC_SPI_NCS *((volatile unsigned long *)(BITBAND_PERI(GPIOA_ODR,4)))
#define DAC_SPI_NCS *((volatile unsigned long *)(BITBAND_PERI(GPIOA_ODR,4)))

#endif

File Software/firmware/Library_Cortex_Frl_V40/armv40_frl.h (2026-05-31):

/******************************************************************************/
/*   (C) Copyright HTL - HOLLABRUNN  2009-2020 All rights reserved. AUSTRIA   */ 
/*                                                                            */ 
/* File Name: armv40_std.h                                                    */
/* Autor: 		Josef Reisinger/ Günter Frasl                                   */
/* Version: 	V40.00                                                          */
/* Date: 		  16/05/2023                                                      */
/* Description: Standard Library für ARM Cortex M3                            */
/******************************************************************************/
/* History: V1.00  creation										              									*/
/* 			V1.01  09.06.2010 REJ:                                            		*/
/*                 Add Bit banding Adresses for LED/Switsches Board           */
/*      V2.0   19.02.2011 REJ:                                                */
/*                 - dil_taster_init, dil_led_init hinzugefügt                */
/*                 - lcd_setcursor auf 4 zelige anzeige erweiterst            */
/*                 - Bitbanding Definitiones von Pointer (Adresse der 		  	*/
/*                   Speicherzelle auf Inhalt der Speicherzelle umgestellt    */
/*				         - Fehler bei Portmodi Settings in Init_led Switsches 	  	*/ 
/*                   korrigiert												  											*/
/*      V3.0   21.09.2020                                                     */
/*                 - convert to MMDS Rev9                        							*/
/*                   (Elimination DIL Schalter /DIL LEd's, adapt to           */ 
/*                   LED/Switches to new port lines, Elimination LCD Display  */
/*                   Elimination von ton Funktion                             */
/*			V30.0  06.04.2021																											*/
/*								 - MDDS library adapt UART2 and UART3												*/
/*			V40.0  16.05.2023																											*/
/*								 - MDDS library adapt UART2 and UART3												*/
/******************************************************************************/
/* Define to prevent recursive inclusion -------------------------------------*/
#ifndef __ARMV30_STD_H
#define __ARMV30_STD_H

/* ----------------------------Includes ---------------------------------------*/
#include <stm32f10x.h>
#include <stdio.h>

/*----------------------------- Define Pins for LED and Swistches--------------*/
/* ------------------------  Einzel-Portpins im Bitbandbereich festlegen       */

#define GPIOA_IDR GPIOA_BASE + 2*sizeof(uint32_t)    // Calc peripheral address GPIOA IDR
#define GPIOA_ODR GPIOA_BASE + 3*sizeof(uint32_t)
#define GPIOB_IDR GPIOB_BASE + 2*sizeof(uint32_t)
#define GPIOB_ODR GPIOB_BASE + 3*sizeof(uint32_t)	 // Calc peripheral address GPIOB ODR
#define GPIOC_IDR GPIOC_BASE + 2*sizeof(uint32_t)
#define GPIOC_ODR GPIOC_BASE + 3*sizeof(uint32_t)

// Calc Bit Band Adress from peripheral address: a = peripheral address b = Bit number
#define BITBAND_PERI(a,b) ((PERIPH_BB_BASE + (a-PERIPH_BASE)*32 + (b*4)))  

#define SW0  *((volatile unsigned long *)(BITBAND_PERI(GPIOC_IDR,0)))		// PC0
#define SW1  *((volatile unsigned long *)(BITBAND_PERI(GPIOC_IDR,1)))	 	// PC1
#define SW2  *((volatile unsigned long *)(BITBAND_PERI(GPIOC_IDR,2)))		// PC2
#define SW3  *((volatile unsigned long *)(BITBAND_PERI(GPIOC_IDR,3)))	 	// PC3
#define SW4  *((volatile unsigned long *)(BITBAND_PERI(GPIOC_IDR,12))) 	// PC12
#define SW5  *((volatile unsigned long *)(BITBAND_PERI(GPIOC_IDR,13)))	// PC13
#define SW6  *((volatile unsigned long *)(BITBAND_PERI(GPIOB_IDR,6)))	 	// PB6
#define SW7  *((volatile unsigned long *)(BITBAND_PERI(GPIOB_IDR,7))) 	// PB7
	
#define PIEZO *((volatile unsigned long *)(BITBAND_PERI(GPIOA_ODR,4)))	//Portleitung des Piezo-Summers (PA4)

#define LED0  *((volatile unsigned long *)(BITBAND_PERI(GPIOA_ODR,0)))	// PA0
#define LED1  *((volatile unsigned long *)(BITBAND_PERI(GPIOA_ODR,1)))	// PA1
#define LED2  *((volatile unsigned long *)(BITBAND_PERI(GPIOA_ODR,2)))	// PA2
#define LED3  *((volatile unsigned long *)(BITBAND_PERI(GPIOA_ODR,3)))	// PA3
#define LED4  *((volatile unsigned long *)(BITBAND_PERI(GPIOA_ODR,4)))	// PA4
#define LED5  *((volatile unsigned long *)(BITBAND_PERI(GPIOA_ODR,5)))	// PA5
#define LED6  *((volatile unsigned long *)(BITBAND_PERI(GPIOA_ODR,6)))	// PA6
#define LED7  *((volatile unsigned long *)(BITBAND_PERI(GPIOA_ODR,7)))	// PA7

#ifdef ARMV30_STD_MOD
#define EXPORT
#else
#define EXPORT extern
#endif 

/* ----------------------------Exported functions ---------------------------- */

/* ------------------------- Reset and Clock Control    -----------------------*/
/******************************************************************************/
/*            U N T E R P R O G R A M M:                                      */
/*                                                                            */
/* Aufgabe: Set System Clock to 72MHz                                         */
/* Input:   none                                                              */
/* return:	none                                                              */
/******************************************************************************/
EXPORT void set_clock_72MHz(void); 

/* ------------------------- LED/ Switches Board Funktions -------------------*/

/******************************************************************************/
/*            U N T E R P R O G R A M M:    init_leds_switches                */
/*                                                                            */
/* Aufgabe:   Initialisiert Portleitungen für LED / Schalterplatine           */
/* Input:                                                                     */
/* return:	                                                                  */
/******************************************************************************/
EXPORT void init_leds_switches(void); 

/*******************************************************************************/
/*            U N T E R P R O G R A M M:    set_leds                          */
/*                                                                            */
/* Aufgabe:  gibt hexadezimalen Wert in auf 8 Leds aus                        */
/*           (an Port 0 angeschlossen)                                        */
/* Input:    value = Wert auf den LEDS gesetzt werden sollen                  */                                                               
/* return:	                                                                  */
/******************************************************************************/
EXPORT void set_leds (char value);
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

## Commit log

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2026-02-06 alles andere
    [ADS8681IPW.PcbLib, ADS8681IPW.SchLib, DBV5.step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]
2026-02-09 psu hwe hinzugerfügt
    [05-08-1664_ADI.step, DAC_Diver_OPV.SchDoc, DIP_LIB.SchLib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]
2026-02-13 dip dok
    [PCB1.PcbDoc, TOP_Sheet.SchDoc]
2026-02-24 DIP Pools
    [Source_OPV_ADC.SchDoc]
2026-02-26 änderungen messbox und Arbeitseit - 10min
    [Arbeits_zeit.xlsx, Arbeitszeit.xlsx]
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2026-02-26 PCB update PG -40min
    [Arbeitszeit.xlsx, OPV_Psu.SchDoc, PCB1.PcbDoc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]
2026-02-26 dip recherche -15min
    [Source_OPV_ADC.SchDoc, TOP_Sheet.SchDoc]
2026-02-26 ja vergessen
    [Arbeitszeit.xlsx]
2026-02-27 ja -20min
    [Arbeitszeit.xlsx, DAC_Diver_OPV.SchDoc, PCB1.PcbDoc]
2026-02-27 changes -30min
    [Arbeitszeit.xlsx]
2026-03-01 case überselgungen -30min
    [Arbeitszeit.xlsx, DAC_Diver_OPV.SchDoc]
2026-03-01 stressen und messure -30min
    [Arbeitszeit.xlsx]
2026-03-10 pcb und tuangabe überarbeitung -2h
    [Arbeitszeit.xlsx, PCB1.PcbDoc, PCB_Testing_Projekt.PrjPcb]
2026-03-13 tia sim -2h
    tia sim und dac buffer 0-3,3 -> +-5
    [DAC_Diver.SchDoc, DAC_Diver_OPV.SchDoc, PCB1.PcbDoc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]
2026-03-13 sachen altium -3h
    [DAC_Diver.SchDoc, DIP_LIB.SchLib, ESP32-DEVKITC-32UE.SchLib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]
2026-03-16 messung und auswertung -4h
    [IDVG_BS170_first_jey.xlsx]
2026-03-17 messungsauswertung fertigung der PCB -4h
    [DAC.SchDoc, DAC8562SDGST.PcbLib, DAC8562SDGST.SchLib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]
2026-03-18 change -2h
    [OPV_Psu.SchDoc, PCB1.PcbDoc]
2026-03-20 altium -2h
    [AD5689RBRUZ.PcbLib, AD5689RBRUZ.SchLib, DAC.SchDoc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]
2026-03-22 ja nicht viel -2h
    [PCB1.PcbDoc]
2026-03-27 pcb -3h
    [PCB1.PcbDoc, TOP_Sheet.SchDoc]
2026-03-27 ja changes source PCB -3h
    [PCB1.PcbDoc, Source_OPV_ADC.SchDoc]
2026-03-27 ja -1h
    [PCB1.PcbDoc]
2026-03-27 changes -4h
    [CNS020-10KP.PcbLib, CNS020-10KP.SchLib, DIP_LIB.SchLib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]
2026-03-27 pcb -1h
    [DAC.SchDoc, DAC_Diver.SchDoc, OPV_Psu.SchDoc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]
2026-04-07 pcb shit -4h
    [PCB1.PcbDoc]
2026-04-07 ja sachen pcb guard -2h
    [PCB1.PcbDoc, TOP_Sheet.SchDoc]
2026-04-08 pcb shit -2h
    [PCB1.PcbDoc]
2026-04-08 pcb guard reserch -4h
    [PCB1.PcbDoc, POPA928DR.PcbLib, POPA928DR.SchLib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]
2026-04-09 ja schane .-3h
    [PCB1.PcbDoc, Source_OPV_ADC.SchDoc]
2026-04-10 pcb -2h
    [PCB1.PcbDoc, Source_OPV_ADC.SchDoc]
2026-04-13 pcb -10min
    [PCB1.PcbDoc]
2026-04-19 pcb recherche -4h
    [PCB1.PcbDoc]
2026-04-21 pcb-5h
    habe neu angefangen und ein stm model gemacht
    [ADC_8681.SchDoc, AD_5689_DAC.SchDoc, CortexM3_dev.SchDoc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]
2026-04-22 pcb -4h
    [472192001.PcbLib, 472192001.SchLib, ADC_8681.SchDoc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]
2026-04-23 pcb desing-2h
    [ADC_8681.SchDoc, AD_5689_DAC.SchDoc, CortexM3_dev.SchDoc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]
2026-04-24 fertige pcb V01 -2h
    [PCB1.PcbDoc, Temp_Sensors.SchDoc]
2026-04-24 tht shit -10min
    [PCB1.PcbDoc]
2026-04-24 jetzt aba -10min
    [PCB1.PcbDoc]
2026-05-05 shematic -1h
    [ADC_8681.SchDoc, Analog_PSU_5.SchDoc, CortexM3_dev.SchDoc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]
2026-05-06 pcb changes -1h
    [CortexM3_dev.SchDoc, PCB1.PcbDoc, Top_Sheet.SchDoc]
2026-05-06 pcb manu tips -2h
    [PCB1.PcbDoc]
2026-05-07 push -2h
    [Keithley_23_24_10meg.xlsx]
2026-05-07 desing rule chack -2h
    [2N7002.PcbLib, 2N7002.SchLib, CortexM3_dev.SchDoc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]
2026-05-10 testpoints pcb -1h
    [1N4148W-7.PcbLib, 1N4148W-7.SchLib, Mappe1.xlsx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]
2026-05-10 testpoints finishes -10min
    [PCB1.PcbDoc]
2026-05-11 pcb fehler gefunden -2h
    [Cal.SchDoc, CortexM3_dev.SchDoc, DAC_Buffer_Filter.SchDoc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]
2026-05-12 pcb tia -2h
    [Cal.SchDoc, CortexM3_dev.SchDoc, PCB1.PcbDoc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]
2026-05-13 pcb psu -1h
    [21-0051H_MXM.step, Analog_PSU_5.SchDoc, DS28E05R&plus_U.PcbLib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]
2026-05-13 pcb alle schaltungen getrennt -3h
    [DAC_Buffer_Filter.SchDoc, PCB1.PcbDoc, PSRAM_SPI.SchDoc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]
2026-05-21 pcb layout power und ic anordnung -4h
    [Copy of CortexM3_dev.SchDoc, CortexM3_dev.SchDoc, PCB1.PcbDoc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]
2026-05-26 pcb fertig? -2h
    [ADC_8681.SchDoc, AD_5689_DAC.SchDoc, Analog_PSU_5.SchDoc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]
2026-05-27 pcb dip vorbesprechung, zip pcb for KUE-2h
    [PCB1.PcbDoc, PCB_Project.PrjPcb, Source_TIA.SchDoc]
2026-05-31 software convert arduino to stm-2h
    [MDDS_BaseBoard_Rev05_Stueckliste.xlsx, MDDS_DAPLink_Module_Rev02_Stueckliste.xls, MDDS_uC_Rev09_Stueckliste.xlsx]
2026-06-01 bom und fehler behebung von nicht aktiven bauteilen- 3h
    [21-0250_Q3+4_MXM.step, 2N7002DW.PcbLib, 2N7002DW.SchLib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]
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2026-06-02 pcb desing error -1,5h
    [BOM_DIGIKEY_01_06_2026.xlsx, BOM_DIGIKEY_01_06_2026_mit100k.xlsx, PCB1.PcbDoc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]
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2026-06-19 worktime excel file python -1h
    [Michael_worktime.xlsx, worktime.xlsx]
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2026-06-24 referenz lib und word template angelegt -3h
    [ADR4040_Voltage_ref.PrjPcb, ADR4540BRZ.PcbLib, ADR4540BRZ.SchLib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]
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2026-06-30 messung einer IDVG mittels Keithley BS170 -4h
    [Device#01_idvg_05_10.xlsx, Michael_worktime.xlsx]
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2026-07-09 pcb fehler gefunden und umgelötet -2h
    [PCB_Project.PrjPcb]
2026-07-10 DIP schreiben LDO Versorgung -3h
    [Digital_Psu.SchDoc, Top_Sheet.SchDoc]
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2026-07-20 PCB trubbelshoot und keil projekt drivers fertig -8h
    [Analog_PSU_5.SchDoc, OPV_psu.SchDoc]
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2026-09-20 tia test alles gut problem mit relai gng aber passt
    [main.c]
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2026-09-23 messung DIC raum -4h Messung am FET
    [messung_erste_divice01.xlsx]
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
